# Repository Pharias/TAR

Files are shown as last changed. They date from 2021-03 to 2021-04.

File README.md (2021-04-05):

# TAR
Git-Projekt für TAR von Felix Kuschel und Manuel Starz

Enthält die Projektdateien:
  -  Dokumentation (LaTeX)
  -  Schaltplan (KiCAD)
  -  Programmcode (C/C++)

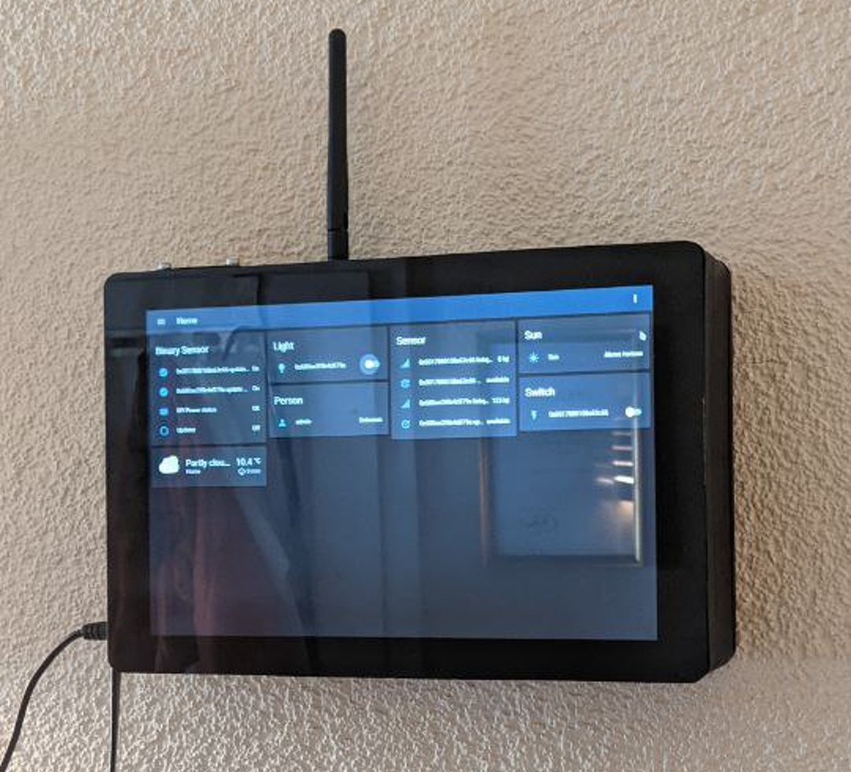
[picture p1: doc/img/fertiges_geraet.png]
Bild der SHZ


## Image für Raspberry Pi
Images für die einfache Einrichtung (Basierend auf Raspberry Pi OS):
 -  Raspberry Pi 4: [mediafire Download](https://www.mediafire.com/file/eujoh6s4thpg363/shz_rp4.img.gz/file)
 -  Raspberry Pi 3: [mediafire Download](https://www.mediafire.com/file/bc2o542na3rea7j/shz_rp3.img.gz/file)

Kann mit [Raspberry Pi Imager](https://www.raspberrypi.org/software/) auf SD-Karte geflasht werden.

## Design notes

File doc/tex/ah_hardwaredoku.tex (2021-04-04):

\subsection{Hardware-Dokumentationen}\label{hardwaredoku}
Durch den Umfang der einzelnen Dokumentationen hier nur eine Auflistung der Dokumentationen mit dem Link zu den PDF im GIT-Projekt bzw. zu den Herstellerseiten.
\begin{itemize}
 	\item Raspberry Pi:\\ {\url{https://www.raspberrypi.org/documentation/hardware/raspberrypi/bcm2711/rpi_DATA_2711_1p0.pdf}}
 	\item MiFare MFRC522:\\ {\url{https://www.nxp.com/docs/en/data-sheet/MFRC522.pdf}}
 	\item CC2531 ZigBee SoC:\\ {\url{https://www.ti.com/lit/ds/symlink/cc2531.pdf}}
 	\item ATmega128RFA1-ZU:\\ {\url{https://ww1.microchip.com/downloads/en/DeviceDoc/Atmel-8266-MCU_Wireless-ATmega128RFA1_Datasheet.pdf}}
\end{itemize}
\newpage

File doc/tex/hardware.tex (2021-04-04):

\section{Hardware}\label{hardware}
% Raspberry Pi 4
\input{tex/hw_raspberrypi}
% Aufbau des Prototypen
\input{tex/hw_prototype}
% Gehäuse
\input{tex/hw_case}
\newpage
% Raspberry Pi HAT
\input{tex/hw_hat}
% Dokumentation des Testaufbaus
\input{tex/hw_testaufbau}
\newpage

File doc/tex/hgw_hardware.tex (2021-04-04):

\subsection{Hardware}\label{hgw_hardware}
Bei der Entwicklung der Hardware haben wir für unser Projekt intern einige Rahmenbedinungen festgelegt:
\begin{itemize}
	\item das Projekt sollte nach Möglichkeit von durchschnittlich begabten Hobbyhandwerkern durchgeführt werden
	\item die Fertigstellung des Projekts sollte mit handelsüblichen Werkzeugen möglich sein
	\item die Grundplattform sollte der 2020 herausgebrachte Raspberry Pi 4 8GB sein\footnote{Wikipedia: Raspberry Pi - Generations}
	\item das Gerät sollte Zigbee-Endgeräte
verwalten können, da diese von vielen Herstellern vertriebenen werden.
\end{itemize}
\noindent Die Beschaffung der Teile lief dank Online-Versandhandel relativ problemlos. 
Beim Erstellen des Prototyps haben wir nur aus Bildschirm, dem Raspberry Pi und dem Zigbee-USB-Stick zusammengebaut (vgl. Abschnitt \ref{hw_prototype}: \nameref{hw_prototype}). 
Die Vorlage  Standfüße stammt vom Hersteller des Bildschirms Sunfounder \footnote{Sunfounder: 10.1 Inch Touch Screen for Raspberry Pi(NEW) - 3D-printed Touch Screen Support}.
Diese haben wir aus PETG\footnote{PETG: Glycol modifiziertes PET} auf dem 3D-Drucker Ender 3  selbst gedruckt. 
Im Folgenden haben wir uns mit der Software des Projekts befasst (vgl. Abschnitt \ref{hgw_software}: \nameref{hgw_software} und Kapitel \ref{software}: \nameref{software}).\par
\noindent Nachdem der Prototyp soweit funktionsfähig war, haben wir das Präsentationsmodell entworfen. 
Dabei ging es uns vornehmlich um die Unterbringung der geplanten Komponenten in einem einfach herzustellendem Gehäuse. 
Hierfür waren einige Verlängerung der Kabel nötig, um Stromzufuhr, Netzwerk und die Antenne des Zigbee-Sticks nach außen zu führen (vgl. Abschnitt \ref{hw_case_modellentwicklung}: \nameref{hw_case_modellentwicklung} und Abschnitt \ref{ku_produkt}: \nameref{ku_produkt}). \\
\noindent Das Gehäuse wurde nach dem Druck mit dem Bildschirm verklebt und die einzelnen Komponenten eingebaut (vgl. Abschnitt \ref{hw_case_herstellung}: \nameref{hw_case_herstellung}). 
Nach dem Zusammenbau haben wir einen Präsentationsaufbau, der die Funktionsweise unseres Prototyps in einem ,,typischen'' Heimnetzwerk darstellen soll (vgl. Abschnitt \ref{hw_testaufbau}: \nameref{hw_testaufbau}).\\
\noindent Näheres zur Umsetzung der Hardware im Kapitel \ref{hardware}: \nameref{hardware}.

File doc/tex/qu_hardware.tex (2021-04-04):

\subsection{Verwendete Hardware}\label{qu_hardware}
\begin{table}[H]
\begin{tabularx}{\textwidth}{|p{5cm}|p{6cm}|p{3.2cm}|}
    	\hline
 	    \textbf{Hardware} & \textbf{Verwendung} & \textbf{Version} \\
    	\hline
    	\hline
    	Raspberry Pi & Hauptplatine für die Smart Home Zentrale & Version 4B (8GB)\\
 	    \hline
 	    CC2531 Zigbee USB Stick mit Firmware & USB-Stick mit ZigBee-Chip & Rev 2.4\\
    	\hline
    	Sunfounder 10.1 Touch Screen  & Bildschirm und Input für die Smart Home Zentrale & Unbekannt\\
 	    \hline
 	    Creality Ender 3 Pro & Fertigung der Kunststoffteile & Modifiziert\\
 	    \hline
    \end{tabularx}
    \caption{Verwendete Hardware}
    \label{tab:qu_hardware}
\end{table}

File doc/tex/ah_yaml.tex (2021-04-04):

\subsection{YAML-Dateien}\label{ah_yaml}
\subsubsection{Home Assistant Konfiguration}\label{ah_yaml_ha_configuration}
\inputminted[
frame=lines,
framesep=2mm,
baselinestretch=1.2,
fontsize=\footnotesize,
linenos,
breaklines, 
breakafter=d
]{yaml}{misc/ha_configuration.yaml}
\subsubsection{Zigbee2MQTT Konfiguration}\label{ah_yaml_zigbee2mqtt}
\inputminted[
frame=lines,
framesep=2mm,
baselinestretch=1.2,
fontsize=\footnotesize,
linenos,
breaklines, 
breakafter=d
]{yaml}{misc/zigbee2mqtt_configuration.yaml}
\subsubsection{Zigbee Geräteauflistung}\label{ah_yaml_devices}
\inputminted[
frame=lines,
framesep=2mm,
baselinestretch=1.2,
fontsize=\footnotesize,
linenos,
breaklines, 
breakafter=d
]{yaml}{misc/devices.yaml}
\newpage

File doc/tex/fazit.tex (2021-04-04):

\section{Epilog \& Fazit}\label{fazit}
% Hier können wir jeder noch n kleines Fazit bzw ne Danksagung oder sowas machen ;)
Zum Abschluss möchten wir sagen, dass wir nach knapp fünf Monaten eine recht ansehnliche Lösung für Smart Home Besitzer entwerfen konnten. 
Dieses Projekt ist in dieser Zeit zu einer Herzensangelegenheit von uns beiden geworden und wird noch einige Zeit über die Abgabe dieser Technikerarbeit hinaus von uns erweitert und betreut.\\
\noindent Unser Ziel wird es sein, das ganze Projekt als ein Baukastensystem für den technisch versierten Smart Home Besitzer, als auch für den Anfänger im Smart Home Bereich auf den Markt zu bringen.
% Statistik?
%\input{tex/fz_statistik}
% Fehler und Probleme
\input{tex/fz_probleme}
% Danksagung
\input{tex/fz_danksagung}
% Latex vs. Word. Auskommentieren für Herr Kohlers Sonderversion ;)
%\input{tex/fz_LatexVsWord}
\newpage

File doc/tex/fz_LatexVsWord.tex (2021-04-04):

\subsection{\LaTeX vs Word}\label{fz_LatexVsWord}
Danke Herr Kohler. 
Ihre fast zwei Jahre langes Gejammer über WYSIWYG-Dokumenteneditoren haben dazu geführt, dass wir uns in den letzten Zügen der Dokumentation dazu entschlossen haben, OHNE JEGLICHE VORERFAHRUNG diese in \LaTeX zu schreiben. 
Ich hoffe, Sie sind stolz auf das Monster, dass Sie geschaffen haben...
\newpage

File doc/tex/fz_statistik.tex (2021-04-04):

\subsection{Statistik}\label{fz_statistik}
Neu aufgesetzte Raspberry Pis: 143\\
Zeilen Bash-Skript: 397\\
Tassen Kaffee: 41\\
Tassen Kakao: 79\\
Filament: 127,31m\\
Erfolgserlebnisse: 15\\
Niederschläge: 18\\
Aha!-Momente: 36\\
Größe der Images: 5.276.969.656 Byte\\
% Muss man noch zählen...
Zeilen \LaTeX - Skript: alle!\\

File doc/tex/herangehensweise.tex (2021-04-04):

\section{Herangehensweise}\label{herangehensweise}
Nach Festlegung der Anforderungen haben wir uns an die Beschaffung der benötigten Materialien und die Einrichtung der Hard- und Software gemacht. 
Hierfür wurde zum Teil bereits vorhandene Hardware, z.B. den Raspberry Pi 4 mit weiteren Komponenten wie dem Touch-Bildschirm, Lautsprechern und einem Mikrofon ergänzt. 
Wir haben die Umsetzung des Projekts in zwei Abschnitte aufgegliedert:
% Hardware
\input{tex/hgw_hardware}
\newpage
% Software
\input{tex/hgw_software}
\newpage

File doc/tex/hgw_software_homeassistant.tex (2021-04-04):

\subsubsection{Home Assistant}\label{hwg_software_homeassistant}
Im Bereich Software haben wir uns bereits verfügbare Lösungen für Smart Home Zentralen angeschaut. 
Ursprünglich war unser Plan, eine eigene Softwarelösung mit Web-Interface oder einer App-Anbindung für Smartphones zu programmieren.\\
\noindent Diese Idee haben wir nach kurzer Zeit aber wieder verworfen, da dieser Markt sowohl mit kostenlosen als auch kostenpflichtigen Lösungen mehr als gesättigt ist. 
Von den kostenlosen und quelloffenen Lösungen war für uns Home Assistant am interessantesten.
Vor allem wegen der großen Menge an Erweitrungsmöglichkeiten und der unserer Meinung nach recht ansprechenden Web-Oberfläche.
Home Assistant verfügt über drei grundlegende Möglichkeiten, installiert zu werden:
\begin{itemize}
    \item als eigenes Betriebssystem-Image (Home Assistant Operating System)
    \item als Docker Container
    \item als Programm auf einem Server.
\end{itemize}
Unabhängig von der Installationsart wird der Home Assistant in zwei Versionen angeboten:
\begin{itemize}
    \item als Core Version
    \item als Supervised Version.
\end{itemize}
Die Core Version ist die einfache Basisversion des Home Assistants, während die Supervised Version ein Addon-Repository integriert. \footnote{siehe \url{https://www.home-assistant.io/installation/}}\\
\noindent Zusätzlich vertreibt Home Assistant auch noch eine fertige Out-of-the-Box-Lösung namens Home Assistant Blue\footnote{siehe \url{https://www.home-assistant.io/blue}} für 140\$ , allerdings gibt es nur wenige Länder, in denen das Gerät verfügbar ist und es besitzt anders als unsere Lösung integrierten keinen Bildschirm.\\
\noindent Für unsere Anwendung war das eigene Betriebssystem-Image nicht verwendbar, da sich auf dem System keine grafische Oberfläche nachinstallieren ließ. 
Aus diesem Grund haben wir uns für zuerst die Programm-Variante des Home Assistants entschieden.\\
\noindent Allerdings gab es bei der Installation der Supervised Version auf unterschiedlichen Versionen des Raspberry Pis Probleme.
Die Core-Version war für unsere Zwecke ungeeignet, da der Arbeitsaufwand für die Integration von zusätzlichen Komponenten und Systemerweiterungen für die Zielgruppe des Projekts zu komplex wäre. \\
\noindent Während unserer Testphase hat sich gezeigt, dass die Verknüpfung von Home Assistant Core, Mosquitto Broker sowie Zigbee2MQTT nicht zu dauerhaft reproduzierbaren Erfolgen geführt hat und sich deshalb nicht wie von uns geplant automatisieren ließ. 
Deshalb haben wir uns für die Container-Variante mit Docker entschieden. 
Das Installationsskript (vgl. \ref{ah_skript}: \nameref{ah_skript}) installiert die benötigten Programme und übernimmt die Grundeinrichtung des Home Assistants bis zu dem Punkt, an dem die Einrichtung über die Weboberfläche durch den Nutzer erfolgt.\\
\noindent Um neben dem Skript noch eine weitere Art der Installation zu ermöglichen, bieten wir die Möglichkeit der Nutzung eines Images.
Für die beiden in Verwendung befindlichen Raspberry Pi Versionen\footnote{Raspberry Pi B Version 3 und Version 4(8GB)} haben wir entspechend nach Ablauf des Installationsskripts ein Backup-Image erzeugt.
Der Benutzername und das Passwort entsprechen bei den Images den standardmäßig in Raspberry Pi OS hinterlegten Nutzern und sollten beim booten sicherheitshalber geändert werden.\\
\noindent Nähere Informationen hierzu im Kapitel \ref{software}: \nameref{software}.

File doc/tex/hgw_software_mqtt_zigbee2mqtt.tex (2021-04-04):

\subsubsection{MQTT und Zigbee2MQTT}\label{hwg_software_mqtt_zibee2mqtt}
Um mit Zigbee die von uns angestrebte Steuerung und Integration von Leuchtmitteln und Geräten zu ermöglichen, benötigen wir den Übertragungsstandard MQTT. Dieser bietet die Möglichkeit, die Zigbee-Daten an den Home Assistant weiter zu reichen.
%Um die von uns angestrebte Steuerung und Integration mit Zigbee-Leuchtmitteln und -Geräten zu ermöglichen, benötigen wir den Übertragungsstandard MQTT und die Möglichkeit die Zigbee Daten über diesen an Home Assistant weiter zu reichen. 
Wir haben uns schon frühzeitig auf den Mosquitto Broker zur Verarbeitung des Zigbee-Protokolls entschieden.
\begin{itemize}
    \item Mosquitto broker (Opensource MQTT broker)
    \item Zigbee2MQTT als Zigbee Schnittstelle
\end{itemize}
\noindent \paragraph{Beschreibung MQTT}
\begin{quote}
    \color{quotetext}
    MQTT is an OASIS standard for IoT connectivity. It is a publish/subscribe, extremely simple and lightweight messaging protocol, designed for constrained devices and low-bandwidth, high-latency or unreliable networks. The design principles are to minimise network bandwidth and device resource requirements whilst also attempting to ensure reliability and some degree of assurance of delivery. These principles also turn out to make the protocol ideal of the “Internet of Things” world of connected devices, and for mobile applications where bandwidth and battery power are at a premium.\footnote{MQTT.org (2021): What is MQTT}
\end{quote}
\noindent \paragraph{Beschreibung Mosquitto Broker}
\begin{quote}
    \color{quotetext}
 	    Eclipse Mosquitto is an open source (EPL/EDL licensed) message broker that implements the MQTT protocol versions 5.0, 3.1.1 and 3.1. Mosquitto is lightweight and is suitable for use on all devices from low power single board computers to full servers.

        The MQTT protocol provides a lightweight method of carrying out messaging using a publish/subscribe model. This makes it suitable for Internet of Things messaging such as with low power sensors or mobile devices such as phones, embedded computers or microcontrollers.

        The Mosquitto project also provides a C library for implementing MQTT clients, and the very popular mosquitto-pub and mosquitto-sub command line MQTT clients.\footnote{mosquitto.org (2021): Eclipse Mosquitto$^{TM}$ An open source MQTT broker}
\end{quote}
\newpage
\noindent \paragraph{Beschreibung Zigbee2MQTT}
\begin{quote}
    \color{quotetext}
 		Zigbee2MQTT is made up of three modules, each developed in its own Github project. Starting from the hardware (adapter) and moving up; zigbee-herdsman connects to your Zigbee adapter an makes an API available to the higher levels of the stack. For e.g. Texas Instruments hardware, zigbee-herdsman uses the TI zStack monitoring and test API to communicate with the adapter. Zigbee-herdsman handles the core Zigbee communication. The module zigbee-herdsman-converters handles the mapping from individual device models to the Zigbee clusters they support. Zigbee clusters are the layers of the Zigbee protocol on top of the base protocol that define things like how lights, sensors and switches talk to each other over the Zigbee network. Finally, the Zigbee2MQTT module drives zigbee-herdsman and maps the zigbee messages to MQTT messages. Zigbee2MQTT also keeps track of the state of the system. It uses a database.db file to store this state; a text file with a JSON database of connected devices and their capabilities.\footnote{Koen Kanters (2021): Zigbee2MQTT}
\end{quote}

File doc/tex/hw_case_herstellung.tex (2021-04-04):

\subsubsection{Herstellung des Gehäuses}\label{hw_case_herstellung}
Zur Herstellung des Gehäuses kommt ein 3D-Drucker der Marke Creality 3D zum Einsatz. 
Der stark modifizierte Ender 3 Pro (vgl. Abb. \ref{fig:ender3}: \nameref{fig:ender3}) druckt die zuvor erstellten STL-Dateien mit PETG-Filament der Firma dasfilament. 
Der für den 3D-Druck nötige G-Code haben wir mit Ultimaker CURA generiert und mit Hilfe von OctoPrint (vgl. Abb. \ref{fig:octoprint}: \nameref{fig:octoprint}) an den Drucker übertragen. Das Gehäuse besteht aus vier Einzelteilen, je zwei Teile für die Seitenwände und zwei Teile für den Deckel.\par
\begin{figure}[H]
	\begin{center}
	
	\end{center}
	\caption[3D-Drucker Ender 3 Pro (mod)]{3D-Drucker Ender 3 Pro (mod)}
	\label{fig:ender3}
\end{figure}
\begin{figure}[H]
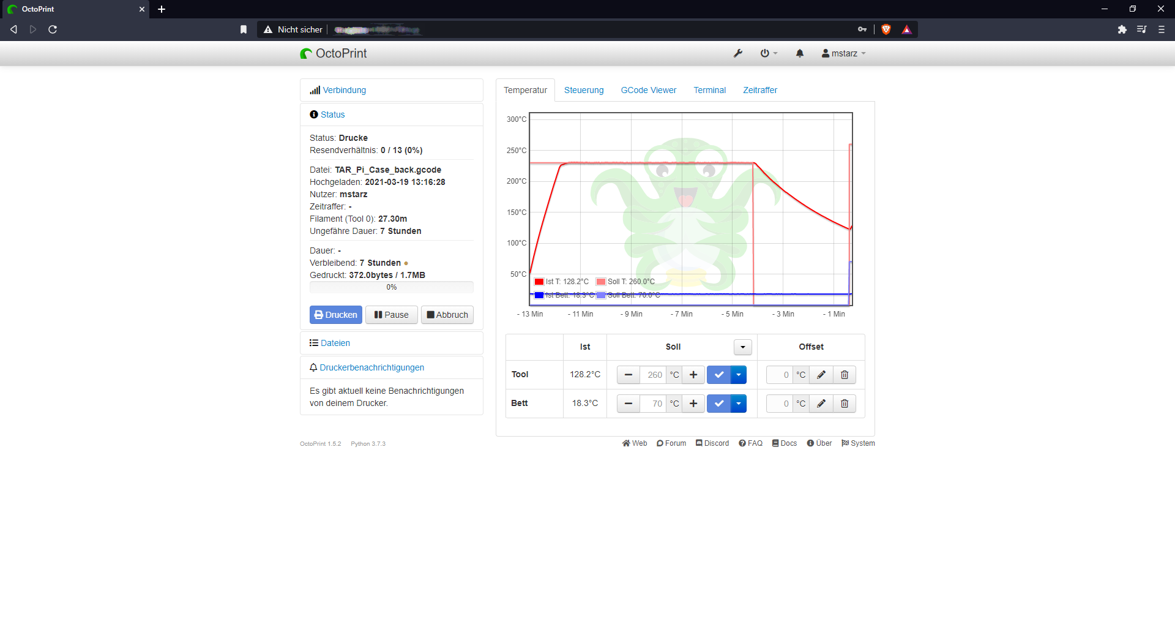
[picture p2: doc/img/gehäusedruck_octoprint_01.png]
	
	\caption[OctoPrint-Weboberfläche]{OctoPrint-Weboberfläche}
	\label{fig:octoprint}
\end{figure}
\noindent Die gedruckten Teile (vgl. Abb. \ref{fig:printet_parts}: \nameref{fig:printet_parts}) werden dann zum Teil mit Zwei-Komponenten-Epoxid-Kleber verbunden (vgl. Abb. \ref{fig:glued_parts}: \nameref{fig:glued_parts}) und mit Hilfe von Schleifpapier und einigen Schichten Klarlack zu einem klavierlackähnlichen Finish veredelt (vgl. Abb. \ref{fig:filed_and_painted_parts}: \nameref{fig:filed_and_painted_parts}).\\ 
\noindent Die Seitenwände werden dann mit dem Bildschirm mit Hilfe des Zwei-Komponenten-Epoxidklebers und Heißkleber permanent verklebt (vgl. Abb. \ref{fig:finished_case_front}: \nameref{fig:finished_case_front}).
Danach wurden die Platinen und Kabel im Gehäuse angebracht (vgl. Abb. \ref{fig:finished_case_front}: \nameref{fig:finished_case_front}). 
Die Rückseite besteht der Einfachheit halber aus zwei identischen, punktsymmetrischen Teilen, die ebenfalls miteinander verklebt wurden.\par
\begin{figure}[H]
	\begin{subfigure}[b]{0.5\linewidth}
		\centering
		
		\caption[Druck eines der Deckel-Teile]{Druck eines der Deckel-Teile}
	\end{subfigure}
	\begin{subfigure}[b]{0.5\linewidth}
		
		\caption[Druck der Wand-Teile]{Druck der Wand-Teile}
	\end{subfigure}
	\caption[Das Gehäuse entsteht]{Das Gehäuse entsteht}
	\label{fig:printing_parts}
\end{figure}
\par
\begin{figure}[H]
	\centering
	\begin{subfigure}[b]{0.3\linewidth}
		
		\caption[Rückseite]{Rückseite}
		\label{printet_parts_back}
	\end{subfigure}
	\begin{subfigure}[b]{0.3\linewidth}
		
		\caption[Linke Seite]{Linke Seite}
		\label{printet_parts_left}
	\end{subfigure}
	\begin{subfigure}[b]{0.3\linewidth}
		
		\caption[Rechte Seite]{Rechte Seite}
		\label{printet_parts_right}
	\end{subfigure}
	\caption[Ausgedruckte Teile des Gehäuses]{Ausgedruckte Teile des Gehäuses}
	\label{fig:printet_parts}
\end{figure}
\par
\begin{figure}[H]
	\begin{subfigure}[b]{0.5\linewidth}
		\centering
		
		\caption[Verklebung des Gehäuses]{Verklebung des Gehäuses}
		\label{fig:glued_parts}
	\end{subfigure}
	\begin{subfigure}[b]{0.5\linewidth}
		\centering
		
		\caption[Abgeschliffene und lackierte Teile]{Abgeschliffene und lackierte Teile}
		\label{fig:filed_and_painted_parts}
	\end{subfigure}
	\begin{subfigure}[b]{0.5\linewidth}
		\centering
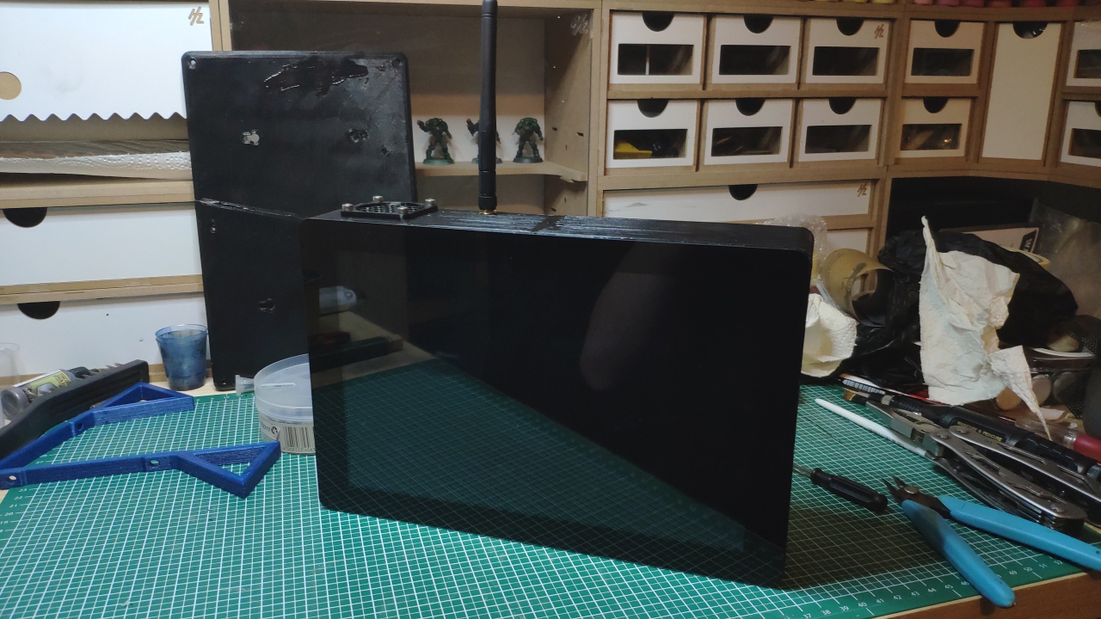
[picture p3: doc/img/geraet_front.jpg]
		
		\caption[Gehäuse und Bildschirm verklebt (von vorne)]{Gehäuse und Bildschirm verklebt (von vorne)}
		\label{fig:finished_case_front}
	\end{subfigure}
	\begin{subfigure}[b]{0.5\linewidth}
		\centering
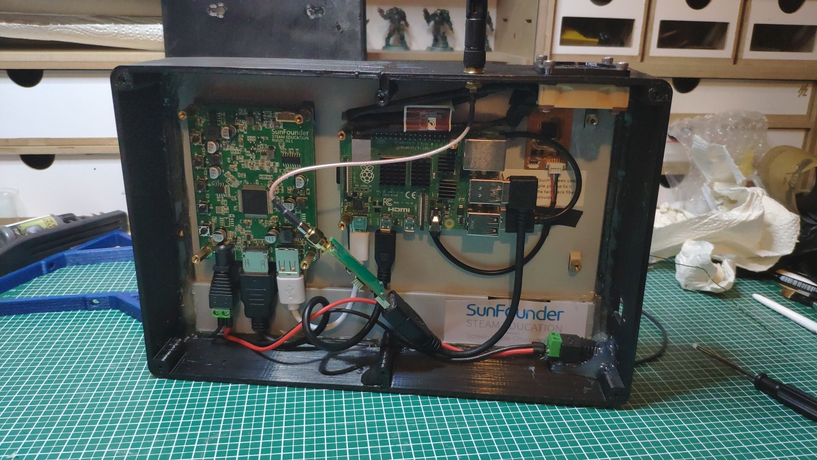
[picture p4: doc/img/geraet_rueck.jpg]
		
		\caption[Gehäuse und Bildschirm verklebt (von hinten)]{Gehäuse und Bildschirm verklebt (von hinten)}
		\label{fig:finished_case_back}
	\end{subfigure}
	\caption[Fertigung des Gehäuses]{Fertigung des Gehäuses}
	\label{fig:creating-case}
\end{figure}\par
\noindent Bei der Herstellung ist es aber zu einem Problem gekommen. 
Die Stützstrukturen haben den Druck am Lüftereinlass gestört, was dazu führt, dass das Lüftergitter an der  linken Seitenwand (vgl. Abb. \ref{printet_parts_left}: \nameref{printet_parts_left}) nicht richtig gedruckt wurde und die losen Filamentstücke zu Macken an den Gehäusewänden führen.

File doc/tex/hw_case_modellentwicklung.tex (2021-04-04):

\subsubsection{Modellentwicklung am Objekt}\label{hw_case_modellentwicklung}
\paragraph{Grundskizze}\\
\noindent Nachdem das Testmodell (vgl. Abb. \ref{fig:print-case-test_04}: \nameref{fig:print-case-test_04}) nicht zu 100 \% gepasst hat, haben wir die Abmessungen neu erfasst und diese in Fusion 360 übertragen (vgl. Abb. \ref{fig:case_footprint}: \nameref{fig:case_footprint}). 
Um Material für den 3D-Druck zu sparen, haben wir eine Papierschablone erstellt, die Zeichnung dann im Maßstab 1:1 auf Papier ausgedruckt, ausgeschnitten und am Bildschirm angelegt.\par
\noindent So haben wir die Maße angepasst und den Plan entsprechend ergänzt(vgl. Abb. \ref{fig:case_footprint_final}: \nameref{fig:case_footprint_final}).\\
\noindent Die Zeichnung haben wir in zwei eigenständige Dateien gesplittet, um die linke und die rechte Seite des Gehäuses konstruieren zu können.\par
\noindent Die Grundabmessung des Bildschirms haben wir in Fusion 360 als neue Zeichnung angelegt. 
Hierzu haben wir ein einfaches Rechteck mit den entsprechenden Außenmaßen gezeichnet (vlg. Abb. \ref{fig:design-case-01}: \nameref{fig:design-case-01}) und anschließend die Ecken mit einem Radius von 7 mm abgerundet (vgl. Abb. \ref{fig:design-case-02}: \nameref{fig:design-case-02}). 
Die Zeichnung haben wir in der Mitte geteilt, um die beiden Hälften des Gehäuses unabhängig von einander konstruieren zu können.\par
\begin{figure}[H]
	\begin{subfigure}[b]{.5\linewidth}
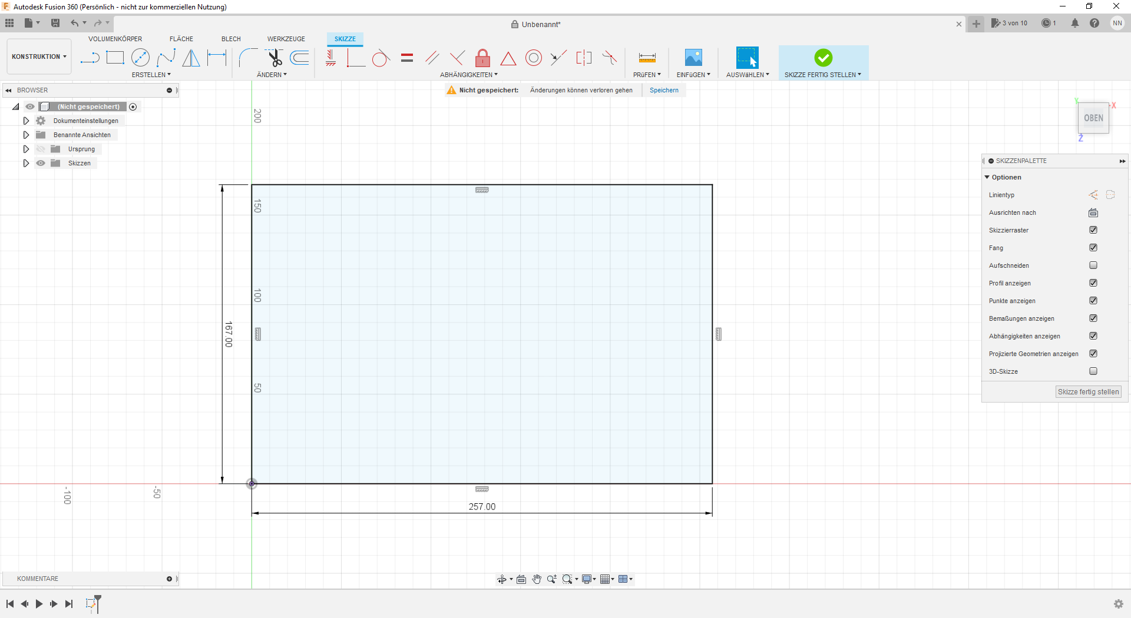
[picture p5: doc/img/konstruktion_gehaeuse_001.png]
		
		\caption[Zeichnen der Außenmaße]{Zeichnen der Außenmaße}
		\label{fig:design-case-01}
	\end{subfigure}
	\begin{subfigure}[b]{.5\linewidth}
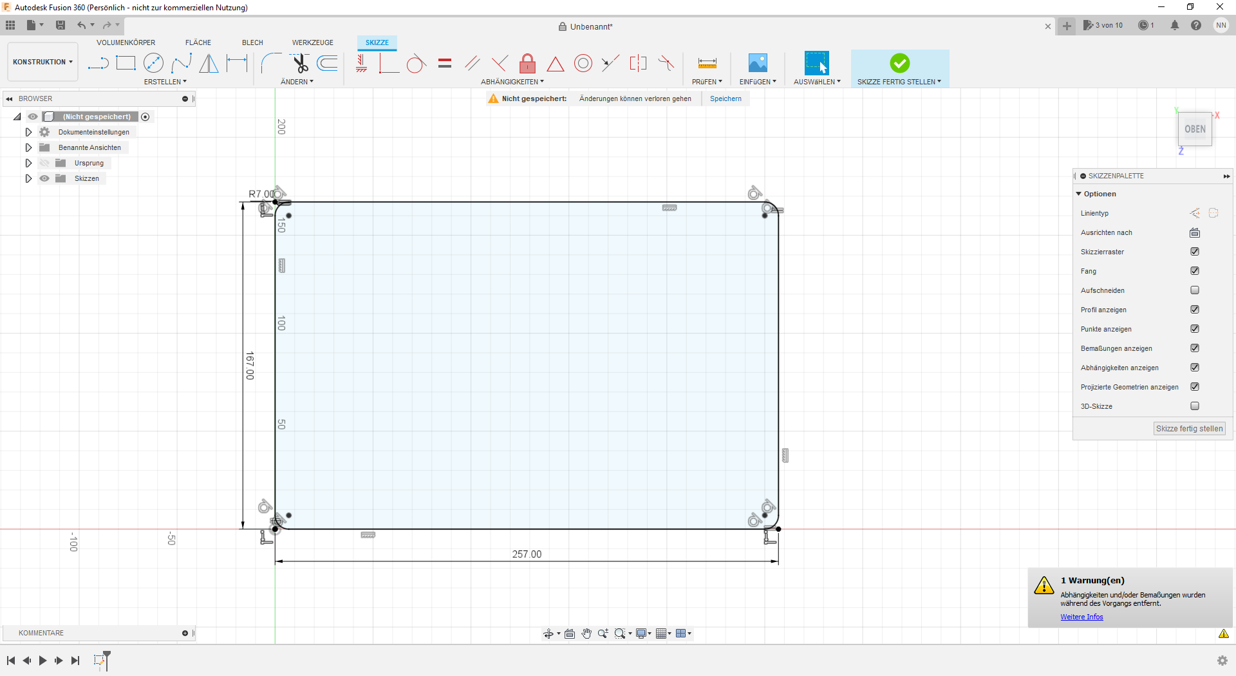
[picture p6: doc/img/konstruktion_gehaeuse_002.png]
		
		\caption[Abrunden der Ecken]{Abrunden der Ecken}
		\label{fig:design-case-02}
	\end{subfigure}
	\begin{subfigure}[b]{.5\linewidth}
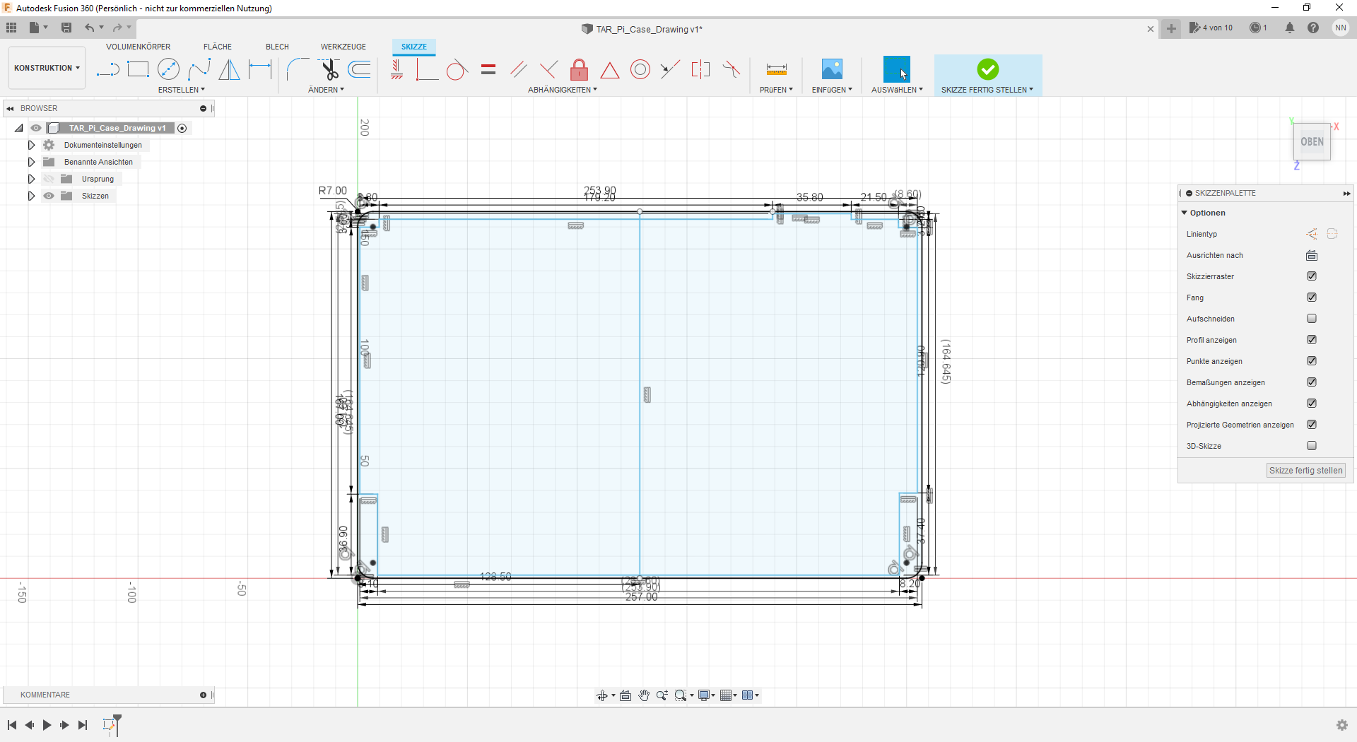
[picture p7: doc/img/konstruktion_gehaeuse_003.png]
		
		\caption[Zeichnen der Auflageflächen für das Gehäuse]{Zeichnen der Auflageflächen}
		\label{fig:design-case-03}
	\end{subfigure}
	\caption[Grundzeichnung als Basis des Modells]{Grundzeichnung als Basis des Modells}
	\label{fig:design-case-base}
\end{figure}\par
\noindent Die so entstandene Zeichnung (vgl. Abb. \ref{fig:design-case-03}: \nameref{fig:design-case-03}) haben wir dann in eine weitere Datei kopiert, die als Grundlage für die beide Seitenteile dient. 
Ausgehend von dieser Zeichnung aus haben wir die beiden Wandteile unabhängig voneinander entworfen.\par
\paragraph{Linkes Wandteil}
Beim linken Wandteil haben wir die Zeichnung um 2 mm entlang der Z-Achse nach oben extrudiert (vgl. Abb. \ref{fig:design-left-01}: \nameref{fig:design-left-01}), um eine Auflagefläche zu erzeugen. 
Auf der Oberseite haben wir eine weitere Zeichnung gelegt, um die Kontaktfläche für die Verklebung mit dem Bildschirm zu erweitern (vgl. Abb. \ref{fig:design-left-02}: \nameref{fig:design-left-02}), die wir dann wie zuvor um 3 mm entlang der Z-Achse extrudiert haben (vgl. Abb. \ref{fig:design-left-03}: \nameref{fig:design-left-03}) um auf die gleiche Höhe des Blechs auf der Rückseite des Bildschirms zu gelangen. \\
\noindent Diese sollte dem Gehäuse genug Auflagefläche auf dem Bildschirm bieten, um die Verklebung so stabil wie möglich zu machen. 
Auf die nun entstandene Erhöhung haben wir eine Zeichnung des Rahmens von 3 mm Stärke erstellt (vgl. Abb. \ref{fig:design-left-04}: \nameref{fig:design-left-04}), die wir dann um 6 mm entlang der Z-Achse extrudiert haben, um für die Verbinder der Schrauben genügend Platz vor dem herausstehenden Blechbereich im unteren Teil des Bildschirms zu bieten (vgl. Abb.  \ref{fig:design-left-05}: \nameref{fig:design-left-05}). \\
\noindent Auf die nun obenliegende Seite des Gehäuses haben wir die Zeichnung der Verbindungsstücke gelegt (vgl. Abbildung \ref{fig:design-left-06}: \nameref{fig:design-left-06}), um 19 mm entlang der Z-Achse extrudiert (vgl. Abb. \ref{fig:design-left-07}: \nameref{fig:design-left-07}). 
Im Kreismittelpunkt der Zeichnungen eine Bohrung für M3-Gewinde gesetzt (vgl. Abb. \ref{fig:design-left-08}: \nameref{fig:design-left-08}). 
Auf die Oberseite haben wir die Zeichnung für die Verbindung von Deckel und dem Seitenteil gesetzt (vgl. Abb. \ref{fig:design-left-09}: \nameref{fig:design-left-09}) und um 25 mm entlang der Z-Achse extrudiert (vgl. Abb. \ref{fig:design-left-10}: \nameref{fig:design-left-10}), damit der von uns verwendete 40 mm Lüfter im Gehäuse Platz findet.
Dies haben wir ebenfalls mit Bohrungen für M3-Gewinde versehen (vgl. Abb. \ref{fig:design-left-11}: \nameref{fig:design-left-11}).\par
\begin{figure}[H]
	\begin{subfigure}[t]{.3\linewidth}
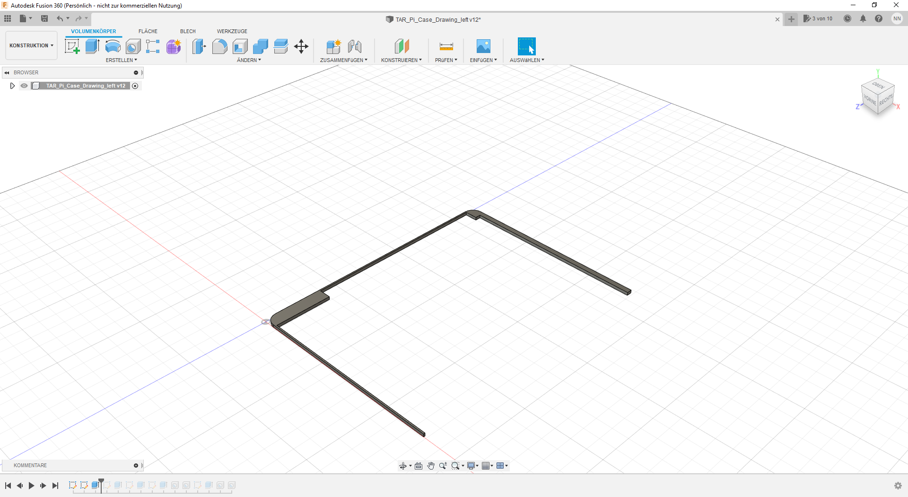
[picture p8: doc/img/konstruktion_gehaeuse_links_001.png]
		
		\caption[Extrusion der Grundzeichnung]{Extrusion der Grundzeichnung}
		\label{fig:design-left-01}
	\end{subfigure}
	\begin{subfigure}[t]{.3\linewidth}
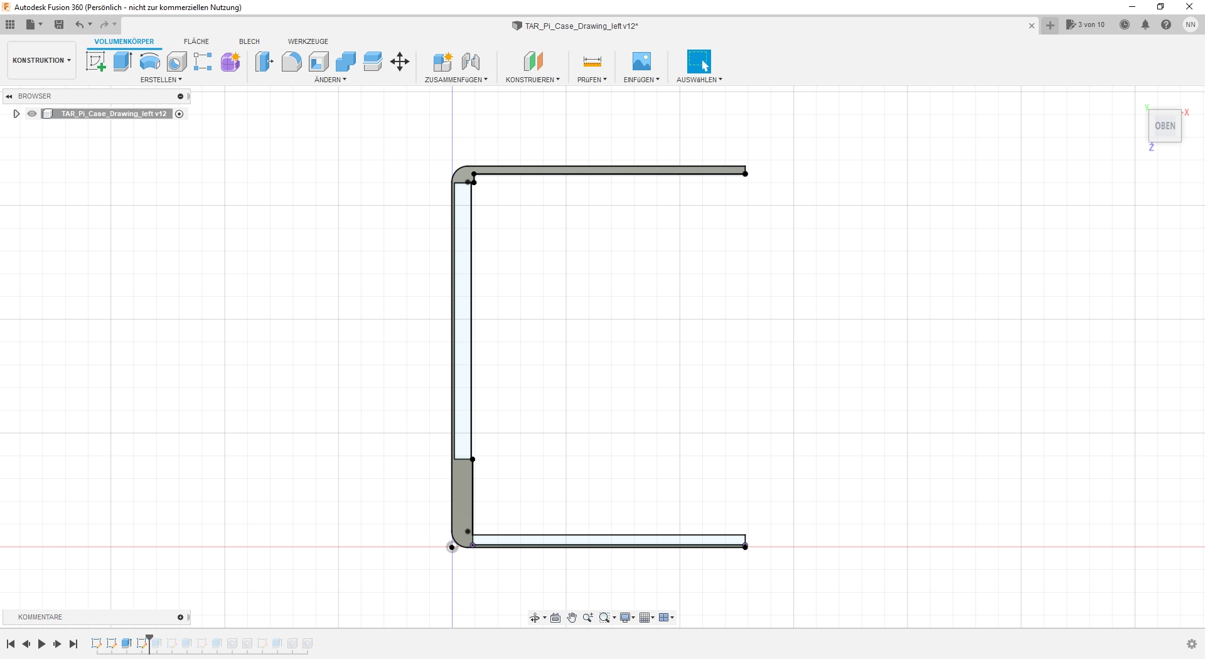
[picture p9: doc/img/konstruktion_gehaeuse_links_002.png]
		
		\caption[Erstellung der Folgezeichnung um Blech]{Erstellung der Folgezeichnung um Blech}
		\label{fig:design-left-02}
	\end{subfigure}
	\begin{subfigure}[t]{.3\linewidth}
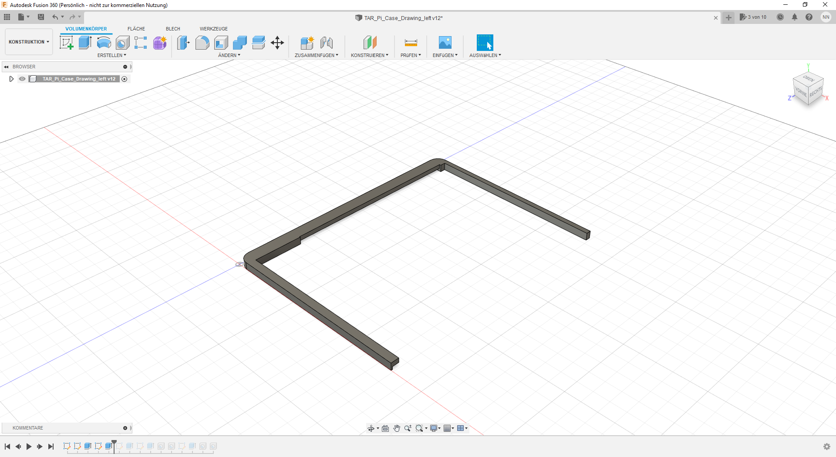
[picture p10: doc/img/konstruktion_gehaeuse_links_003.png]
		
		\caption[Extrusion der neuen Zeichnung]{Extrusion der neuen Zeichnung}
		\label{fig:design-left-03}
	\end{subfigure}
	\begin{subfigure}[t]{.3\linewidth}
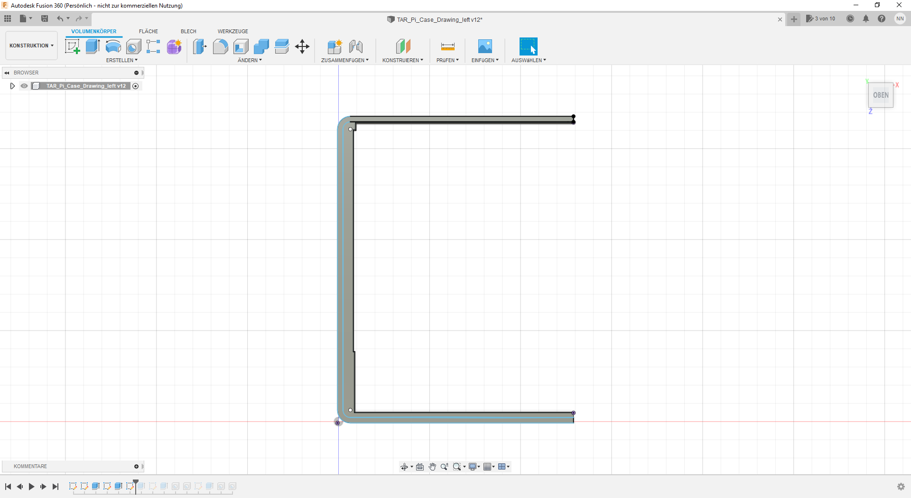
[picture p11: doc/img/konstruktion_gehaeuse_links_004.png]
		
		\caption[Zeichnung der Hauptwandstärke]{Zeichnung der Hauptwandstärke}
		\label{fig:design-left-04}
	\end{subfigure}
	\begin{subfigure}[t]{.3\linewidth}
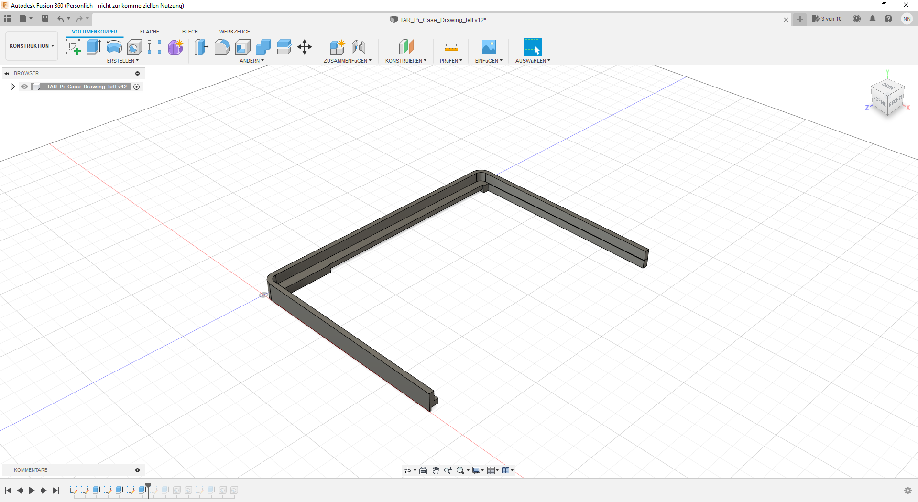
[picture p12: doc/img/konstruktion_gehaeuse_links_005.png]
		
		\caption[Extrusion der Hauptwand]{Extrusion der Hauptwand}
		\label{fig:design-left-05}
	\end{subfigure}
	\begin{subfigure}[t]{.3\linewidth}
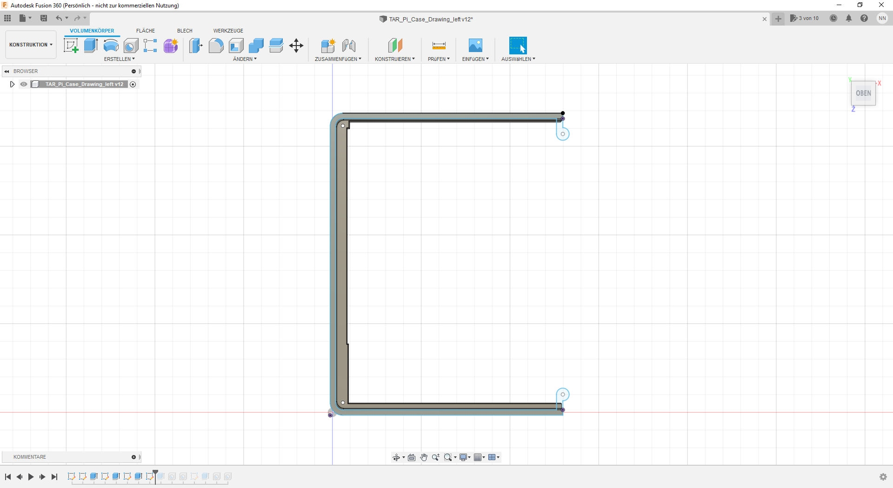
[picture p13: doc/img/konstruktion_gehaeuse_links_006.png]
		
		\caption[Zeichnung der Verbindungsstücke]{Zeichnung der Verbindungsstücke}
		\label{fig:design-left-06}
	\end{subfigure}
	\begin{subfigure}[t]{.3\linewidth}
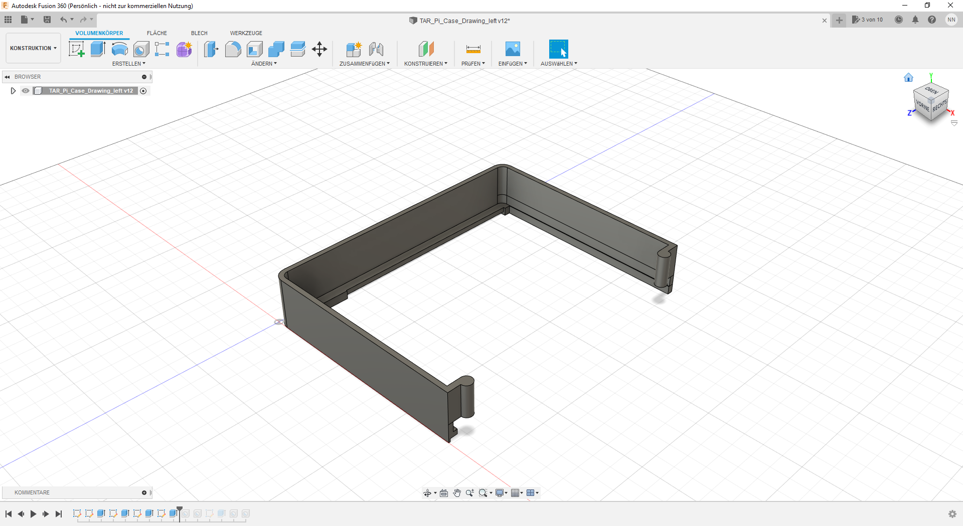
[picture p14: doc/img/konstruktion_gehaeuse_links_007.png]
		
		\caption[Extrusion der Hauptwand mit Verbindungsstücken]{Extrusion der Hauptwand mit Verbindungsstücken}
		\label{fig:design-left-07}
	\end{subfigure}
	\begin{subfigure}[t]{.3\linewidth}
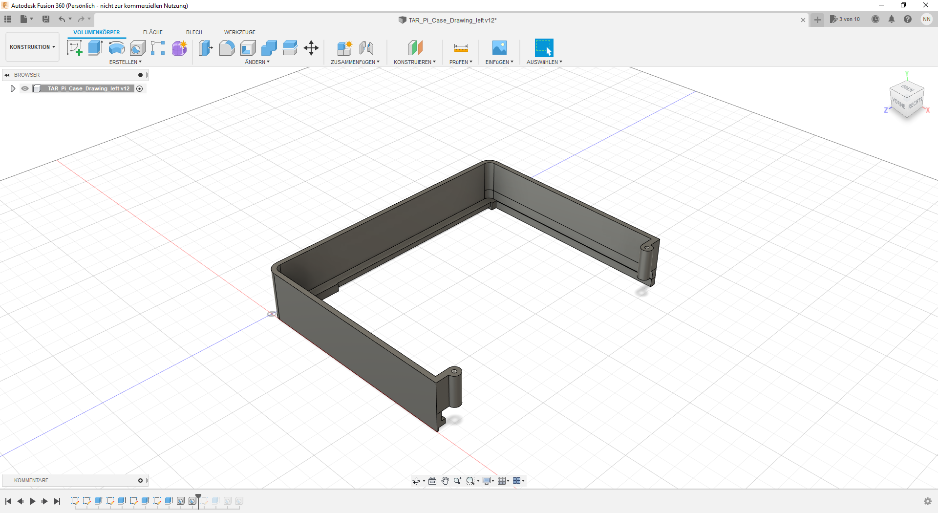
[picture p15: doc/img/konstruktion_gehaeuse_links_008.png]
		
		\caption[Bohrung für Schrauben]{Bohrung für Schrauben}
		\label{fig:design-left-08}
	\end{subfigure}
	\begin{subfigure}[t]{.3\linewidth}
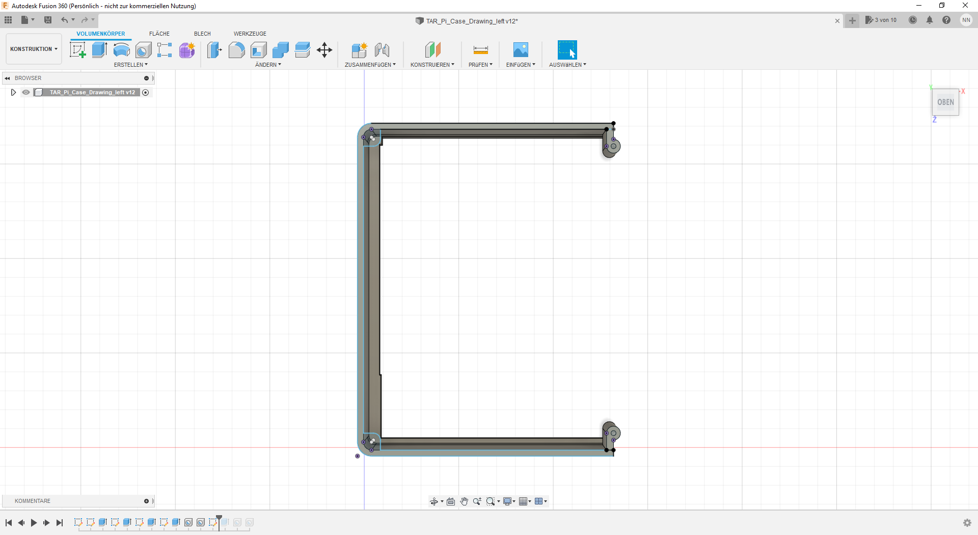
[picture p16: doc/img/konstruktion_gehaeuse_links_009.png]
		
		\caption[Zeichnung der Deckelverbindung]{Zeichnung der Deckelverbindung}
		\label{fig:design-left-09}
	\end{subfigure}
	\begin{subfigure}[t]{.3\linewidth}
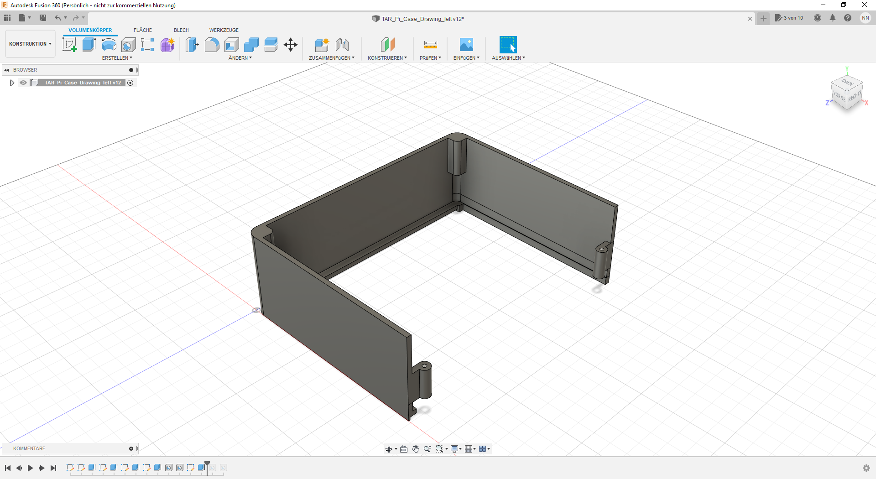
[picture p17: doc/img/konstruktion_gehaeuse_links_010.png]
		
		\caption[Extrusion der Hauptwand mit Deckelverbindung]{Extrusion der Hauptwand mit Deckelverbindung}
		\label{fig:design-left-10}
	\end{subfigure}
	\begin{subfigure}[t]{.3\linewidth}
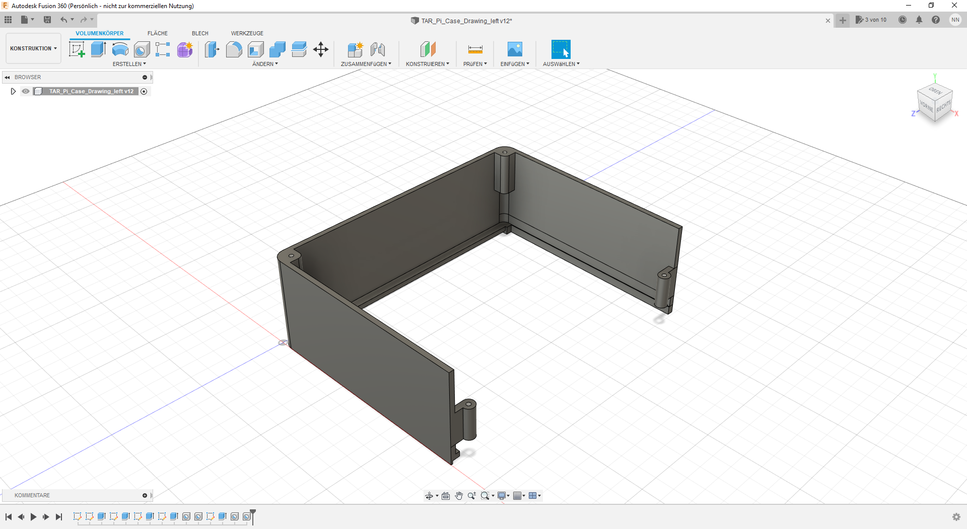
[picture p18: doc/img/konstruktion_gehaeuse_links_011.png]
		
		\caption[Bohrungen der Deckelverbindung]{Bohrungen der Deckelverbindung}
		\label{fig:design-left-11}
	\end{subfigure}
	\caption[Entwurf des linken Wandteils]{Entwurf des linken Wandteils}
	\label{fig:design-left}
\end{figure}\par
\newpage
\paragraph{Rechtes Wandteil}
Beim rechten Teil des Gehäuses ist die Vorgehensweise weitestgehend die selbe wie beim linken Gehäuseteil (vgl. Abb. \ref{fig:design-right-01}: \nameref{fig:design-right-01} - Abb. \ref{fig:design-right-08}: \nameref{fig:design-right-08} mit Abb. \ref{fig:design-left}: \nameref{fig:design-left}). 
Der Unterschied zwischen beiden Teilen, abgesehen von den Verbindungsstücken und der Aussparung für das Flachkabel des Bildschirms, sind zusätzlich die Aussparungen für Lüfter, Antenne, Netzwerkanschluss und Strombuchse. \\
\noindent Für den Lüfter und die Antenne haben wir auf dem oberen Teil des Gehäuses eine Zeichnung aufgelegt (vgl. Abb. \ref{fig:design-right-09}: \nameref{fig:design-right-09}), die  wir dann ins Negative extrudiert haben, um die gezeichnete Fläche aus dem Gehäuse zu löschen (vgl. Abb. \ref{fig:design-right-10}: \nameref{fig:design-right-10}). 
Mit der selben Vorgehensweise haben wir die Aussparung für eine RJ45-Verlängerung und eine 5,5 mm DC-Buchse gesetzt. 
Zuerst haben wir die Zeichnung für die Aussparung auf die Seite gelegt (vgl. Abb.  \ref{fig:design-right-11}: \nameref{fig:design-right-11}) und diese dann ebenfalls ins Negative extrudiert (vgl. Abb. \ref{fig:design-right-12}: \nameref{fig:design-right-12}). \\
\noindent Um für die Befestigung der 5,5 mm DC-Buchse eine Unterlage im Gehäuse zu haben, haben wir der Grundriss eines Rechtecks auf die Innenseite des Gehäusebodens gelegt (vgl. Abb.  \ref{fig:design-right-13}: \nameref{fig:design-right-13}) und extrudiert (vgl. Abb. \ref{fig:design-right-14}: \nameref{fig:design-right-14}), um die Möglichkeit zu haben, die Buchse mit dem Gehäuse zu verkleben. 
Damit die Buchse nicht zu tief im Gehäuse steckt, haben wir eine Zeichnung eines konzentrischen Kreises auf die bereits vorhandene Aussparung auf die Innenseite gelegt  (vgl. Abb.  \ref{fig:design-right-15}: \nameref{fig:design-right-15}) und dann um einige Millimeter ins Negative verkürzt, um die Aussparung zu generieren (vgl. Abb. \ref{fig:design-right}: \nameref{fig:design-right}).\par
\begin{figure}[H]
	\begin{subfigure}[t]{.3\linewidth}
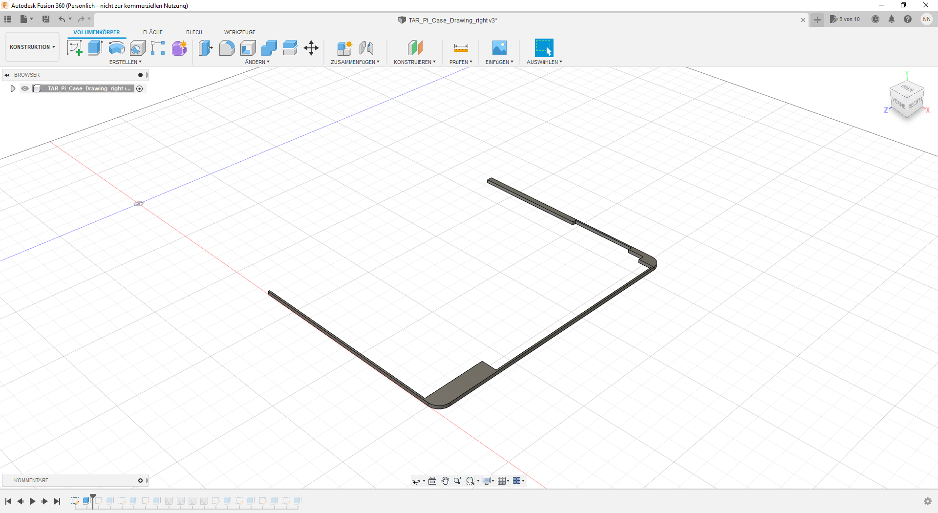
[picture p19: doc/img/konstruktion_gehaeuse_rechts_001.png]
		
		\caption[Extrusion der Grundzeichnung]{Extrusion der Grundzeichnung}
		\label{fig:design-right-01}
	\end{subfigure}
	\begin{subfigure}[t]{.3\linewidth}
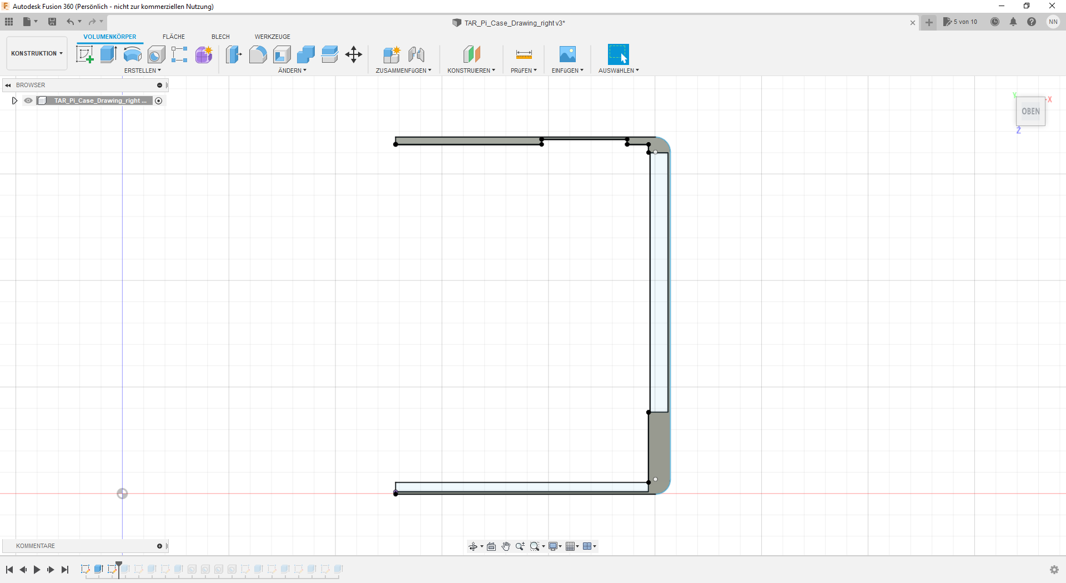
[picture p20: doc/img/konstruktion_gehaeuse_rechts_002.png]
		
		\caption[Erstellung der Folgezeichnung um Blech]{Erstellung der Folgezeichnung um Blech}
		\label{fig:design-right-02}
	\end{subfigure}
	\begin{subfigure}[t]{.3\linewidth}
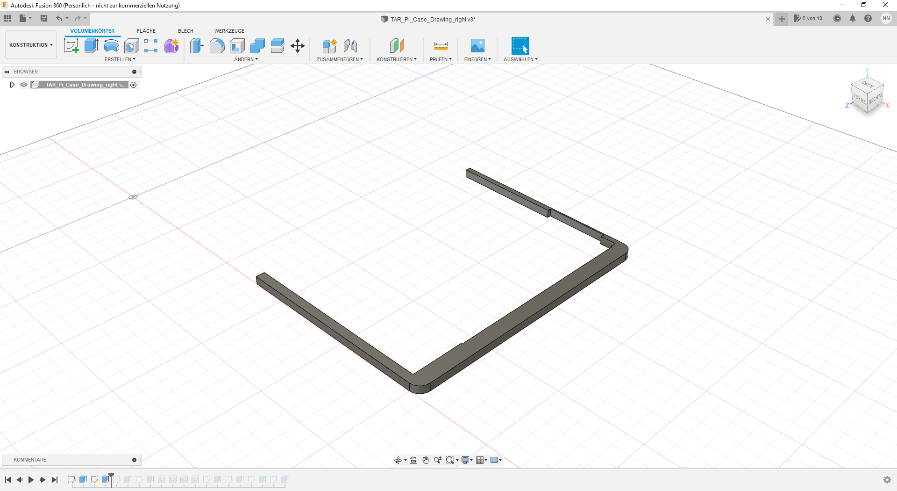
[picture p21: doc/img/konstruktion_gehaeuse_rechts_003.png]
		
		\caption[Extrusion der neuen Zeichnung]{Extrusion der neuen Zeichnung}
		\label{fig:design-right-03}
	\end{subfigure}
	\begin{subfigure}[t]{.3\linewidth}
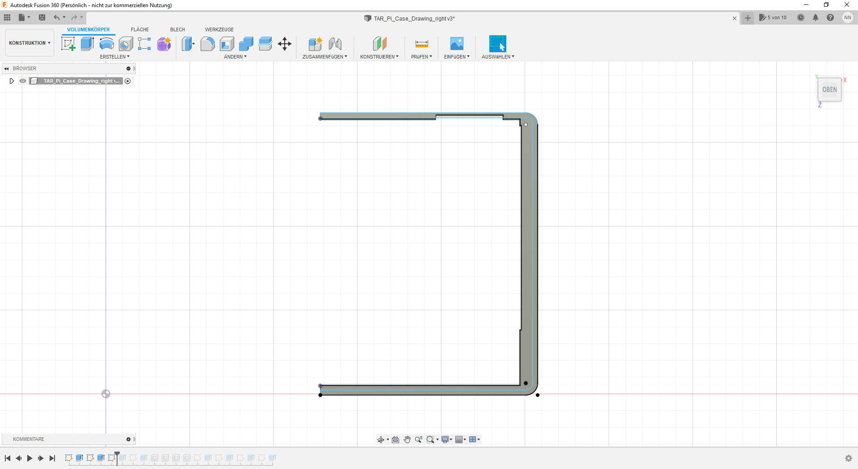
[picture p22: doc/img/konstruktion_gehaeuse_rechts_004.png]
		
		\caption[Zeichnung der Hauptwandstärke]{Zeichnung der Hauptwandstärke}
		\label{fig:design-right-04}
	\end{subfigure}
	\begin{subfigure}[t]{.3\linewidth}
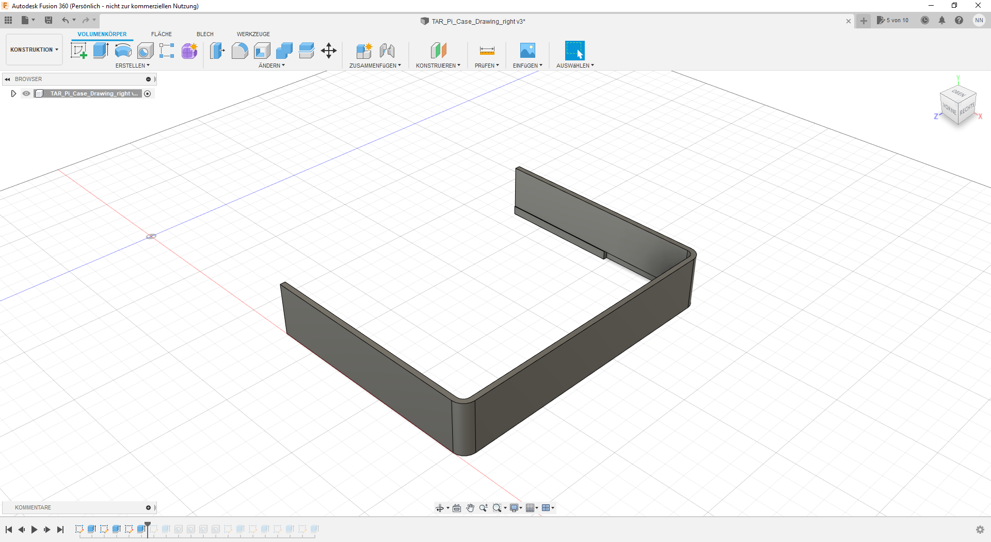
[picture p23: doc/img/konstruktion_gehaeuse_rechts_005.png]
		
		\caption[Extrusion der Hauptwand]{Extrusion der Hauptwand}
		\label{fig:design-right-05}
	\end{subfigure}
	\begin{subfigure}[t]{.3\linewidth}
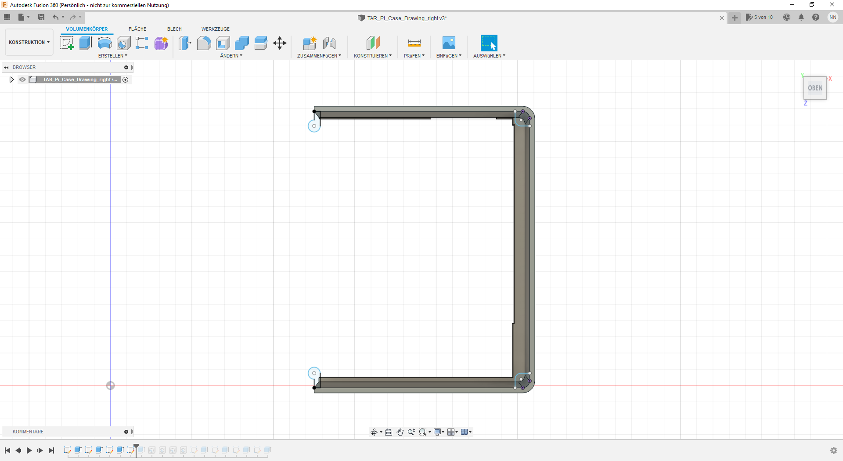
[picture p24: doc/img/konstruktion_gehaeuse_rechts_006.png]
		
		\caption[Zeichnung der Verbindungsstücke \& Deckelverbindung]{Zeichnung der Verbindungsstücke \& Deckelverbindung}
		\label{fig:design-right-06}
	\end{subfigure}
	\begin{subfigure}[t]{.3\linewidth}
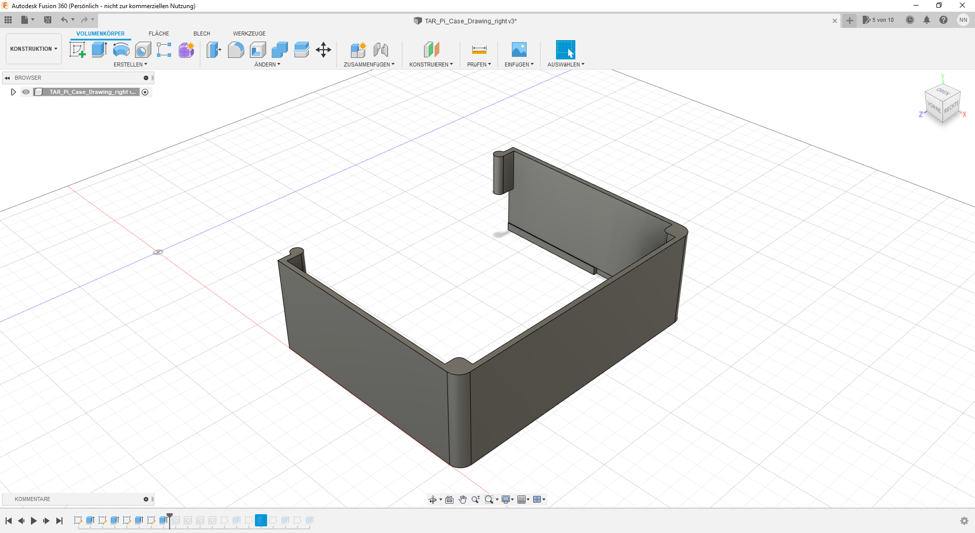
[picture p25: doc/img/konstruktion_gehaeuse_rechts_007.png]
		
		\caption[Extrusion der Hauptwand mit Deckelverbindung]{Extrusion der Hauptwand mit Deckelverbindung}
		\label{fig:design-right-07}
	\end{subfigure}
	\begin{subfigure}[t]{.3\linewidth}
		
		\caption[Bohrung für Schrauben]{Bohrung für Schrauben}
		\label{fig:design-right-08}
	\end{subfigure}
	\begin{subfigure}[t]{.3\linewidth}
		
		\caption[Zeichnung für Lüfteröffnung \& Antennenausgang]{Zeichnung für Lüfteröffnung \& Antennenausgang}
		\label{fig:design-right-09}
	\end{subfigure}
	\begin{subfigure}[t]{.3\linewidth}
		
		\caption[Extrusion der Lüfteröffnung]{Extrusion der Lüfteröffnung}
		\label{fig:design-right-10}
	\end{subfigure}
	\begin{subfigure}[t]{.3\linewidth}
		
		\caption[Zeichnung der Aussparung für Stromanschluss \& Netzwerkbuchse]{Zeichnung der Aussparung für Stromanschluss \& Netzwerkbuchse}
		\label{fig:design-right-11}
	\end{subfigure}
	\begin{subfigure}[t]{.3\linewidth}
		
		\caption[Extrusion der Netzwerkbuchse]{Extrusion der Netzwerkbuchse}
		\label{fig:design-right-12}
	\end{subfigure}
	\begin{subfigure}[t]{.3\linewidth}
		
		\caption[Zeichnung des Stromsteckerblocks]{Zeichnung des Stromsteckerblocks}
		\label{fig:design-right-13}
	\end{subfigure}
	\begin{subfigure}[t]{.3\linewidth}
		
		\caption[Extrusion des Stromsteckerblocks]{Extrusion des Stromsteckerblocks}
		\label{fig:design-right-14}
	\end{subfigure}
	\begin{subfigure}[t]{.3\linewidth}
		
		\caption[Zeichnung der Aussparung]{Zeichnung der Aussparung}
		\label{fig:design-right-15}
	\end{subfigure}
	\begin{subfigure}[t]{.3\linewidth}
		
		\caption[Extrusion der Aussparung]{Extrusion der Aussparung}
		\label{fig:design-right-16}
	\end{subfigure}
	\caption[Entwurf des rechten Wandteils]{Entwurf des rechten Wandteils}
	\label{fig:design-right}
\end{figure}\par
\paragraph{Gehäuserückwand}\par
Das Design der Gehäuserückwand basiert nur rudimentär auf der in Abb. \ref{fig:design-case-base}: \nameref{fig:design-case-base} erstellten Zeichnung. 
Die Außenmaße stimmen zwar überein, die Zeichnung für die Auflage auf den Seitenwänden haben wir aber neu erstellt. 
Zusätzlich haben wir eine Diagonale zur punktsymmetrischen Trennung der Teile eingefügt (vgl. Abb. \ref{fig:design-back-01}: \nameref{fig:design-back-01}), welche den Zeitaufwand für den Druck von zwei unterschiedlichen Teilen für die Rückseite reduzieren soll. \\
\noindent Nachdem wir die  Zeichnung extrudiert haben (vgl. Abb. \ref{fig:design-back-02}: \nameref{fig:design-back-02}), haben wir noch einen Vorsprung auf der kurzen Seite des Bauteils extrudiert (vgl. Abb. \ref{fig:design-back-03}: \nameref{fig:design-back-03}), um die beiden Rückwandteile besser verbinden zu können. 
Anschließend haben wir ein weiter Teil der inneren Zeichnung ins Negative extrudiert, um diesen Bereich freizustellen (vgl. Abb. \ref{fig:design-back-04}: \nameref{fig:design-back-04}) und um beim Druck der Teile Material zu sparen. \\
\noindent Damit für eventuelle Toleranzen zwischen den beiden Teilen Platz ist, haben wir auf dem Vorsprung die Aussparung für die darunterliegende Schraubendurchführung erhöht (vgl. Abb. \ref{fig:design-back-05}: \nameref{fig:design-back-05}) und den Vorsprung von unten mit einer Fase versehen, was den Materialverbrauch für das Teil weiter reduziert (vgl. Abb. \ref{fig:design-back-06}: \nameref{fig:design-back-06}). 
Zudem haben wir die obere Kante (vgl. Abb. \ref{fig:design-back-07}: \nameref{fig:design-back-07}), die Innenseite (vgl. Abb. \ref{fig:design-back-08}: \nameref{fig:design-back-08}) und auch den Vorsprung (vgl. Abbildung \ref{fig:design-back-09}: \nameref{fig:design-back-09}) mit einer Fase versehen. \\
\noindent Um die Bohrungen an die richtige Stellen setzen zu können, haben wir eine Hilfszeichnung auf die Außenfläche, also die Außenseite der Rückwand, aufgelegt (vgl. Abb. \ref{fig:design-back-10}: \nameref{fig:design-back-10}). 
Dort haben wir dann drei M3-Bohrungen für Senkkopfschrauben gesetzt (vgl. Abb. \ref{fig:design-back-11}: \nameref{fig:design-back-11}). \\
\noindent Für die Aufhängungen auf der Rückseite des Gehäuses haben wir eine weitere Zeichnung aufgelegt (vgl. Abb. \ref{fig:design-back-12}: \nameref{fig:design-back-12}) und dann ins Negativ extrudiert (vgl. Abb. \ref{fig:design-back-13}: \nameref{fig:design-back-13}).
So kann das Gehäuse mit zwei Schrauben an der Wand angebracht werden.  
Um beim Aufhängen nicht an einen bestimmten Typ Schrauben gebunden zu sein, haben wir eine kleine Fase an den engeren Teil der Aufhängungen gelegt (vgl. Abb. \ref{fig:design-back-14}: \nameref{fig:design-back-14}). 
\begin{figure}[H]
	\begin{subfigure}[t]{.3\linewidth}
		
		\caption[Grundrisszeichnung]{Grundrisszeichnung}
		\label{fig:design-back-01}
	\end{subfigure}	
	\begin{subfigure}[t]{.3\linewidth}
		
		\caption[Extrusion der Grundform]{Extrusion der Grundform}
		\label{fig:design-back-02}
	\end{subfigure}
	\begin{subfigure}[t]{.3\linewidth}
		
		\caption[Extrusion des Vorsprungs]{Extrusion des Vorsprungs}
		\label{fig:design-back-03}
	\end{subfigure}
	\begin{subfigure}[t]{.3\linewidth}
		
		\caption[Erstellen der Aussparung]{Erstellen der Aussparung}
		\label{fig:design-back-04}
	\end{subfigure}
	\begin{subfigure}[t]{.3\linewidth}
		
		\caption[Anpassung für Toleranz]{Anpassung für Toleranz}
		\label{fig:design-back-05}
	\end{subfigure}
	\begin{subfigure}[t]{.3\linewidth}
		
		\caption[Abfasen des Vorsprungs]{Abfasen des Vorsprungs}
		\label{fig:design-back-06}
	\end{subfigure}
	\begin{subfigure}[t]{.3\linewidth}
		
		\caption[Abfasen der Außenseite]{Abfasen der Außenseite}
		\label{fig:design-back-07}
	\end{subfigure}
	\begin{subfigure}[t]{.3\linewidth}
		
		\caption[Anbringung der Fase an der Innenseite]{Anbringung der Fase an der Innenseite}
		\label{fig:design-back-08}
	\end{subfigure}
	\begin{subfigure}[t]{.3\linewidth}
		
		\caption[Anbringung der Fase am Vorsprung]{Anbringung der Fase am Vorsprung}
		\label{fig:design-back-09}
	\end{subfigure}
	\begin{subfigure}[t]{.3\linewidth}
		
		\caption[Hilfszeichnung für Bohrungen]{Hilfszeichnung für Bohrungen}
		\label{fig:design-back-10}
	\end{subfigure}
	\begin{subfigure}[t]{.3\linewidth}
		
		\caption[Bohrungen mit Aussparung für Senkkopfschrauben]{Bohrungen mit Aussparung für Senkkopfschrauben}
		\label{fig:design-back-11}
	\end{subfigure}
	\begin{subfigure}[t]{.3\linewidth}
		
		\caption[Zeichnung für Wandaufhängungslöcher]{Zeichnung für Wandaufhängungslöcher}
		\label{fig:design-back-12}
	\end{subfigure}
	\begin{subfigure}[t]{.3\linewidth}
		
		\caption[Extrusion der Wandaufhängungslöcher]{Extrusion der Wandaufhängungslöcher}
		\label{fig:design-back-13}
	\end{subfigure}
	\begin{subfigure}[t]{.3\linewidth}
		
		\caption[Abfasen der Wandaufhängungslöcher]{Abfasen der Wandaufhängungslöcher}
		\label{fig:design-back-14}
	\end{subfigure}
	\begin{subfigure}[t]{.3\linewidth}
		
		\caption[Abfasen des Vorsprungs in der Mitte]{Abfasen des Vorsprungs in der Mitte}
		\label{fig:design-back-15}
	\end{subfigure}
	\caption[Entwurf der Gehäuserückwand]{Entwurf der Gehäuserückwand}
	\label{fig:design-back}
\end{figure}\par
\newpage

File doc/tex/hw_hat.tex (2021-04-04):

\subsection{Erstellung des RPi-HATs}\label{hw_hat}
Zur Schaltplanzeichnung haben wir das OpenSource-Programm KiCAD genutzt.
Dieses ist für zahlreiche Betriebssysteme verfügbar.\footnote{Siehe \url{https://www.kicad.org/download/}} 
Teilebibliotheken sind ebenso zahlreich im Internet verfügbar, wir haben uns auf den Anbieter SnapEDA beschränkt, da dieser die meisten gängigen Bauteile für Elektronik-CAD-Systeme anbietet. 
Eine weitere Bezugsquelle ist der Verkäufer Digi-Key Electronics, der einen Großteil seines Sortiments an SMD-Bauteilen als Bibliothek anbietet\footnote{Siehe \url{https://www.digikey.de/de/resources/design-tools/kicad}}. 
Als Grundlage für den HAT sollte die Projektvorlage ,,Raspberry Pi - 40-Pin HAT'' von Jon Buford dienen.
Diese Vorlage richtete sich nach den offiziellen HAT-Spezifikationen für den Raspberry Pi\footnote{Siehe \url{https://github.com/raspberrypi/hats}}.\par
\noindent Zu Beginn des Projekts haben wir in KiCAD die GPIO-Ports anhand der offiziellen Dokumentation beschriftet, um das Nachschlagen der Belegung für die Zukunft zu vermeiden.
\begin{figure}[H]
	
	\caption[Raspberry Pi 4 GPIO-Pins]{Raspberry Pi 4 GPIO-Pins}
	\label{rpi-gpio-pins}
\end{figure}
\par
\noindent Anschließend haben wir die (unserer Meinung nach) benötigten Komponenten auf den Schaltplan gezogen beziehungsweise vorher importiert und dann diese sauber verdrahtet (vgl. Abb. \ref{hat-design}: \nameref{hat-design}).\par
\begin{figure}[H]
	
	\caption[Aktueller Stand HAT-Design]{Aktueller Stand HAT-Design}
	\label{hat-design}
\end{figure}
\noindent Aufgrund der bereits weit vorangeschrittenen Zeit im Projektplan, der aktuellen COVID-19-Pandemie und unserer Unwissenheit im Bezug auf Schaltplanentwicklung, sowie der von uns verwendeten Hardware, mussten wir aber einsehen, dass die Entwicklung und Fertigung eines HAT's den Zeitrahmen sprengen würde und so haben wir Ende Februar 2021 beschlossen, dieses Projekt vorerst zurückzustellen und uns auf die Fertigstellung unserer bisherigen Testerfolge und Prototypen zu fokusieren.
Die KiCAD-Projekt-Dateien stehen, wie alle anderen Dateien des Projekts nach Abgabe der Technikerarbeit frei über das entsprechende GITHUB zur Verfügung.\par

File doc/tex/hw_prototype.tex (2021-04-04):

\subsection{Aufbau des Prototypen}\label{hw_prototype}
Der Prototyp war eine Kombination aus dem verwendeten Touchscreen sowie dem Raspberry Pi 4 und dem Zigbee-Stick. 
Dieser Prototyp diente als Entwicklungsplattform für die Software.\\
\noindent Auf der Detailansicht der Rückseite (vgl. Abb. \ref{fig:prototype_back}: \nameref{fig:prototype_back}) erkennt man den Raspberry Pi mt dem Zigbee-Stick und der angeschlossenen Antenne auf der rechten Seite.
Auf der linken Seite ist das Controller-Board des Bildschirms.
Dies dient gleichzeitig als Stromversorgung für den Raspberry Pi.
\begin{figure}[H]
	\begin{subfigure}[b]{0.5\linewidth}
		
		\caption[Vorderseite des Prototypen]{Vorderseite des Prototypen}
	\end{subfigure}
	\begin{subfigure}[b]{0.5\linewidth}
		
		\caption[Rückseiteseite des Prototypen]{Rückseite des Prototypen}
	\end{subfigure}
	\begin{subfigure}[b]{1\linewidth}
		
		\caption[Detailansicht der Rückseite]{Detailansicht der Rückseite}
		\label{fig:prototype_back}
	\end{subfigure}
	\caption[Prototyp der Smart Home Zentrale]{Prototyp der Smart Home Zentrale}
	\label{prototype}
\end{figure}
\newpage

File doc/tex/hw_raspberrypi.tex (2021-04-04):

\subsection{Raspberry Pi 4}\label{hw_raspberrypi}
Als Basis für die Smart Home Zentrale haben wir einen Raspberry Pi in der Version 4 mit 8 GB gewählt, um als von anderen Servern unabhängige Plattform agieren zu können. 
Der Raspberry Pi 4 ist mit einem ARM Cortex-A72 Prozessor ausgestattet, der über 4 Kerne verfügt.
Zusätzlich hat der Raspberry Pi 4 über einen Gigabit-Netzanschluss.
In der Makerszene ist der Raspberry Pi weit verbreitet und dient bei anspruchsvolleren Projekten als Kern.\par
\begin{quote}
 		\color{quotetext}
 		Der Raspberry Pi hat sich seit der ersten Veröffentlichung Anfang 2012 weltweit schon millionenfach verkauft und erfreut sich immer noch größter Beliebtheit. Denn viele Raspberry Pi User haben nicht nur einen Einplatinen-Computer zu Hause, sondern teils 4-5 Stück.
Der eine fungiert als HD-Mediaplayer mit externer Festplatte für das heimische Kino oder als Internetradio mit Display, der nächste als Webcam-Server für die Kameraüberwachung mit Livestream auf das Handy, dann noch einer für die Hausautomatisierung wie bspw. die Heizungs- oder Lichtsteuerung und noch einer als einfacher WLAN-Druckerserver oder als Mini-Computer zum allgemeinen Surfen im Internet, um ein paar wenige Anwendungsszenarien zu nennen.
Sie merken, der kleine ,,Tausendsassa'' kann nicht nur viel, sondern ist zudem auch noch extrem günstig und eben das macht den Reiz aus. Lediglich den Hang zum Programmieren sollten Sie mitbringen und selbst nicht mal das, denn Sie können auch einfach nach Anleitung aus Foren oder Büchern nachprogrammieren, oder ganz bequem ein fertiges Image auf den Raspberry Pi installieren - trauen Sie sich! 
\footnote{reichelt.de: Produktbeschreibung des Raspberry Pi 4}
\end{quote}
\newpage

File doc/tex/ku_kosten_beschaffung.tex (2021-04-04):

\subsubsection{Beschaffungskosten}\label{ku_kosten_beschaffung}
\begin{center}
\begin{table}[H]
    \begin{tabularx}{\textwidth}{|p{5.6cm}|p{1.2cm}|p{3.44cm}|p{3.5cm}|}
        \hline
 	    \textbf{Produkt} & \textbf{Menge} & \textbf{Kosten pro Stück}  & \textbf{Kosten insgesamt}\\
	    \hline
	    \hline
	    Raspberry Pi 4 Modell B 8 GB & 1 & 87,22 \euro{} & 87,22 \euro{} \\
	    \hline
	    SanDisk Extreme microSD 128 GB & 1 & 19,99 \euro{} & 19,99 \euro{} \\
	    \hline
	    SUNFOUNDER RPi 10.1'' Touch Display & 1 & 129,99 \euro{} & 129,99 \euro{} \\
	    \hline
	    Noctua NF-A4x10 5v & 1 & 12,90 \euro{} & 12,90 \euro{} \\
	    \hline
	    ITSTUFF CC2531 Zigbee USB-Stick & 1 & 14,90 \euro{} & 14,90 \euro{} \\
	    \hline
	    ITSTUFF Alu-Kühlkörper Set RPi 4 & 1 & 4,91 \euro{} & 4,91 \euro{} \\
	    \hline
	    Eightwood SMA Verlängerung & 1 & 7,99 \euro{} & 7,99 \euro{} \\ 
	    \hline
	    VCE 5,5 mm Stecker \& Buchse & 1 & 8,29 \euro{} & 8,29 \euro{} \\
	    \hline
	    dasFilament PTGE schwarz 1,75 mm & 0,52 & 24,95 \euro{}\footnote{Kosten der Spule (800 g).} & 11,61\euro{}\footnote{Kosten verwendetes Material für Gehäusedruck} \\
	    \hline
	    USB-Verlängerung & 1 & 9,99 \euro{} & 9,99 \euro{}\\
	    \hline
	    \hline
	    % hier noch die Kosten für das Zeug, das du gekauft hast, Felix. der Stick steht ja schon drin, aber weiß nicht ob der Preis passt...
	    %\hline
	    \textbf{Gesamtkosten} &  &  & \textbf{309,37 \euro{}} \\ % Kosten zusammenrechnen ;)
	    \hline
    \end{tabularx}
    \caption{Beschaffungskosten}
    \label{tab:ku_kostenberechnung}
\end{table}
\end{center}

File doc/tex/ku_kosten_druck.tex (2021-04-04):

\subsubsection{Kostenberechung für die 3D-Druckteile}\label{ku_kosten_druck}
\noindent Die Kosten lassen mit folgender Formel darstellen:\\
\[
K_{gesamt} =  (K_{Material/g} \cdot M_{Material}) +  (T_{Druck} \cdot  K_{kWh} \cdot V_{\emptyset/h})
\]
Die Kosten der 3D-Druckteile lassen sich in zwei Einzelpositionen aufteilen: Material und Energie.
Die Materialkosten lassen sich leicht erfassen, da wir die Kosten der Spule Filament mit 24,95 \euro{} und einem Gewicht von 800 g Filament auf der Spule gegeben haben.
So ergibt sich ein Preis von 0,03(12...)\euro{} ($K_{Material/g}$) pro Gramm verwendetem Filament.
Der Druck der Gehäuseteile verbrauchte 423 g Material ($M_{Material}$), das heißt, dass die Materialkosten sich auf 13,19 \euro{} belaufen.\par
\noindent Die Energiekosten zu berechnen ist etwas komplexer.
Der 3D-Drucker verbraucht circa 120 W pro Stunde($V_{\emptyset/h}$)\footnote{Robert (2019): Antwort auf Creality Ender 3 printer power consumption? - 3dprinting Stack Exchange}, was bei einem Strompreis von 0,31 \euro{} / kWh ($K_{kWh}$) bedeuten würde, dass wir pro Stunde etwa 0,0372 \euro{} Stromkosten haben. 
Bei einer Gesamtdruckzeit von 36 Stunden und 36 Minuten($T_{Druck}$) ergeben sich also Stromkosten von 1,37 \euro{}.\par
\noindent Addiert man nun die Kosten für Material und Energie, so ergibt sich ein Fertigungspreis von 12,98 \euro{} ($K_{gesamt}$). 
Dabei ist der Zeitaufwand für die Veredelung, also Schleifen und Lackieren, noch nicht mit einkalkuliert.\par

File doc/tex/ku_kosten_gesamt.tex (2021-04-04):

\subsubsection{Gesamtkosten}\label{ku_kosten_gesamt}
\begin{center}
\begin{table}[H]
    \begin{tabularx}{\textwidth}{|p{9.9cm}|p{4.7cm}|}
        \hline
 	    \textbf{Position} & \textbf{Kosten} \\
 	    \hline
 	    \hline
 	    Materialkosten & 309,37 \euro{} \\
	    \hline
	    Stromkosten Druck & 1,37 \euro{} \\
	    \hline
	    Stundenlohn & 3800,00 \euro{} \\
	    \hline
	    Kosten Präsentationsboard & 113,27 \euro{} \\
	    \hline
	    \hline
	    \textbf{Gesamtkosten} & \textbf{4224,01 \euro{}} \\ % Kosten zusammenrechnen ;)
	    \hline
    \end{tabularx}
    \caption{Gesamtkostenberechnung}
    \label{tab:ku_gesamtkostenberechnung}
\end{table}
\end{center}

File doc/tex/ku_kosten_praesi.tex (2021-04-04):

\subsubsection{Kosten Präsentationsboard}\label{ku_kosten_praesi}
\begin{center}
\begin{table}[H]
    \begin{tabularx}{\textwidth}{|p{5.6cm}|p{1.2cm}|p{3.44cm}|p{3.5cm}|}
        \hline
 	    \textbf{Produkt} & \textbf{Menge} & \textbf{Kosten pro Stück}  & \textbf{Kosten insgesamt}\\
	    \hline
	    \hline
	    OSB Platte & 1 & 11,22 \euro{} & 11,22 \euro{} \\
	    \hline
	    Kantholz & 4,2 m & 1,38 \euro{} & 2,76 \euro{} \\
	    \hline
	    Lampenfassung E27 Schwarz & 2 & 2,99 \euro{} & 5,98 \euro{} \\
	    \hline
	    Winkelverbinder Gleichschenklig & 4 & 4,99 \euro{} & 19,96 \euro{} \\
	    \hline
	    Konstruktionswinkel & 2 & 1,19 \euro{} & 2,38 \euro{} \\
	    \hline
	    Schrauben & 1 & 12,99 \euro{} & 12,99 \euro{} \\
	    \hline
	    Mantelleitung NYM-J 3 x 1,5 Grau 5 m & 1 & 4,99 \euro{} & 4,99 \euro{} \\ 
	    \hline
	    Abzweigkasten Aufputz & 3 & 1,59 \euro{} & 4,77 \euro{} \\
	    \hline
	    Schutzkontakt Flachstecker mit seitlicher Einführung & 1 & 1,69 \euro{}\ & 1,69\euro{} \\
	    \hline
	    Schutzkontakt Steckdose & 1 & 6,99 \euro{} & 6,99 \euro{} \\
	    \hline
	    König KNM-FTM10 Tablet Wandhalterung & 1 & 10,55 \euro{} & 10,55 \euro{} \\
	    \hline
	    Philips HUE Smart Plug & 1 & 29,99 \euro{} & 29,99 \euro{} \\
	    %\hline
	    \hline
	    \hline
	    \textbf{Gesamtkosten} &  &  & \textbf{113,27 \euro{}} \\ % Kosten zusammenrechnen ;)
	    \hline
    \end{tabularx}
    \caption{Kosten Präsentationsaufbau}
    \label{tab:ku_kostenpraesi}
\end{table}
\end{center}

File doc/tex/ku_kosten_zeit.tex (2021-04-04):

\subsubsection{Arbeitszeit}\label{ku_kosten_zeit}
Gerechnet wird in Stunden, ein Arbeitstag hat 8 Stunden.
\begin{center}
\begin{table}[H]
    \begin{tabularx}{\textwidth}{|p{11.8cm}|p{2.8cm}|}
        \hline
 	    \textbf{Projektabschnitt} & \textbf{Dauer (in h)} \\
	    \hline
	    \hline
	    Recherche & 60 \\
	    \hline
	    Themenfindung & 6 \\
	    \hline
	    Anfertigung Lastenheft & 20 \\
	    \hline
	    Beschaffung Hardware & 4 \\
	    \hline
	    Entwicklung Prototyp & 40 \\
	    \hline
	    Konstruktion Gehäuse & 40 \\
	    \hline
	    Software Installation & 8 \\
	    \hline
	    Entwurf Skript & 80 \\
	    \hline
	    Erstellung Images & 4 \\
	    \hline
	    Entwurf Raspberry Pi HAT & 30 \\
	    \hline
	    Dokumentation & 80 \\
	    \hline
	    Funktionsprüfung & 20 \\
	    \hline
	    Präsentationsaufbau & 8 \\
	    \hline
	    \hline
	    \textbf{Gesamt} & \textbf{400} \\
	    \hline
    \end{tabularx}
    \caption{Erfassung der Arbeitszeiten}
    \label{tab:ku_arbeitszeiten}
\end{table}
\end{center}
\noindent Bei dem aktuell gültigen Mindestlohn von 9,50 \euro{} \footnote{Deutscher Gewerkschaftsbund (2021): Mindestlohn 2021/2022: Was ändert sich?} kommen wir so auf Arbeitskosten von 3800 \euro{}.

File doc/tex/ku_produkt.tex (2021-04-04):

\subsection{Das ,,fertige`` Produkt}\label{ku_produkt}
\begin{figure}[H]
	
	\caption[Smart Home Zentrale]{Smart Home Zentrale}
	\label{fig:smart-home-zentrale}
\end{figure}
\noindent In Abbildung \ref{fig:smart-home-zentrale} wird das Ergebnis der Technikerarbeit von Felix Kuschel und Manuel Starz präsentiert. 
Die Smart Home Zentrale verfügt über eine ZigBee-Antenne, einem 10.1'' großen Touchbildschirm und der Möglichkeit, per LAN und oder WLAN mit dem Heimnetz in Verbindung zu treten.\par
\noindent Das Gehäuse ist für die Wand-Montage (vgl. Abb. \ref{fig:smart-home-zentrale}: \nameref{fig:smart-home-zentrale}) oder als Aufstellgerät (vgl. Abb. \ref{fig:case-with-feet}: \nameref{fig:case-with-feet}) entworfen worden.
\begin{figure}[H]
	
	\caption[Gehäuse mit Füßen (Render in Meshmixer)]{Gehäuse mit Füßen (Render in Meshmixer)}
	\label{fig:case-with-feet}
\end{figure}

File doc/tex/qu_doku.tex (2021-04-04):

\subsection{Dokumentationsquellen}\label{qu_doku}
Quellen für Verweise, die in Fußnoten innerhalb dieser Dokumentation erwähnt wurden:
\begin{itemize}
        \item github.com: Zigbee2MQTT Projektseite\\ 
        {\url{https://github.com/koenkk/zigbee2mqtt//}}
        \item mosquitto.org: Startseite\\ 
        {\url{https://mosquitto.org//}}
 		\item Li (2017): Was ist ein Smart-Home-Hub? Alles über die intelligente Zentrale\\ {\url{https://www.otto.de/updated/ratgeber/erklaert-was-ist-ein-smart-home-hub-80634/}}
 		\item Robert (2019): Antwort auf Creality Ender 3 printer power consumption? - 3dprinting Stack Exchange\\ {\url{https://3dprinting.stackexchange.com/questions/8616/creality-ender-3-printer-power-consumption#8623/}}
 		\item reichelt.de: Produktbeschreibung des Raspberry Pi 4\\{\url{https://www.reichelt.de/raspberry-pi-4-b-4x-1-5-ghz-8-gb-ram-wlan-bt-rasp-pi-4-b-8gb-p276923.html}}
 		\item Wikipedia: Raspberry Pi - Generations\\{\url{https://en.wikipedia.org/wiki/Raspberry_Pi#Generations}}
 		\item Sunfounder: 10.1 Inch Touch Screen for Raspberry Pi(NEW)\\{\url{http://wiki.sunfounder.cc/index.php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}}
 		\item MQTT.org (2021): What is MQTT\\ {\url{https://mqtt.org/faq/}}
 		\item mosquitto.org (2021): Eclipse Mosquitto$^{TM}$ An open source MQTT broker\\ {\url{https://mosquitto.org/}}
 		\item Koen Kanters (2021): Zigbee2MQTT\\ {\url{https://github.com/koenkk/zigbee2mqtt#internal-architecture}}
 		\item Deutscher Gewerkschaftsbund (2021): Mindestlohn 2021/2022: Was ändert sich?\\{\url{https://www.dgb.de/themen/++co++6ca263de-fb0e-11e9-bdcf-52540088cada#wiehoch2021}}
\end{itemize}
Quellen, die für die Herstellung dieser Dokumentation genutzt wurden:
\begin{itemize}
	\item Menmiloud Mohammed: \LaTeX -Tutorial.com\\{\url{https://latex-tutorial.com/}}
	\item Overleaf: \LaTeX -Guides\\{\url{https://www.overleaf.com/learn}}
\end{itemize}

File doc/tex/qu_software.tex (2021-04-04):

\subsection{Verwendete Software}\label{qu_software}
\begin{table}[H]
\begin{tabularx}{\textwidth}{|p{5cm}|p{6cm}|p{3.2cm}|}
 	\hline 
 	\textbf{Software} & \textbf{Verwendung} & \textbf{Version} \\ 
 	\hline 
 	\hline
 	Raspberry Pi OS & Betriebssystem und Oberfläche für Hardware & 5.4 \\ 
 	\hline 
 	Home Assistant & Betriebssystem und Oberfläche für Smart Home & 5.12 \\ 
 	\hline
 	Mosquitto broker & Broker für den MQTT Nachrichtenstandard & 5.1.1 \\ 
 	\hline
 	Zigbee2MQTT & Anbindung von Zigbee an MQTT & 1.18.1-2 \\ 
 	\hline
 	KiCad EDA & Erstellung von Schaltplan und Gerber-Datei des HAT's & 5.1.8 \\ 
 	\hline 
 	TexMaker & Erstellung der Dokumentation & 5.0.4 \\ 
 	\hline
 	\url{overleaf.com } & Gemeinsame Erstellung der Dokumentation & Web \\
 	\hline
 	Fusion360 & Erstellung von Gehäusemodell & 2.0.9849 \\ 
 	\hline
 	CURA & Erstellung von G-Code für 3D-Drucker & 4.7 \\ 
 	\hline
 	GanttProject & Erstellung von Gantt-Diagrammen & 3.0.3 \\ 
 	\hline
 	Autodesk Meshmixer & Vorschau-Render der STL-Dateien & 3.5.474 \\
 	\hline
 	paint.net & Bildmanipulation & 4.2.15\\
 	\hline
 	Win32 Disk Imager & Erstellung der Images aus den Micro-SD-Karten & 1.0 \\
 	\hline
 	7Zip & Komprimieren der Images & 19.00\\
 	\hline
 	\url{shellcheck.net/} & Überprüfung von Bash-Skripten & Web \\
 	\hline
 	\url{deepl.com/translator} & Übersetzungssoftware & Web \\
 	\hline
 	Microsoft Teams & KANBAN Board und die Kommunikation & 1.4.00.7174 \\
 	\hline
\end{tabularx} 
\caption{Verwendete Software}
\label{tab:qu_software}
\end{table}

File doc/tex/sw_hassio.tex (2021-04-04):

\subsection{Home Assistant Supervised}\label{sw_hassio}
Nachdem das Installationsskript (vgl. Abschnitt \ref{ah_skript}: \nameref{ah_skript}) fehlerfrei Home Assistant Supervised installiert hat, können wir mit der Einrichtung über die Weboberfläche fortfahren. 
Dafür öffnen wir, im selben Netzwerk wie unser Raspberry Pi, die Webseite http://<raspberry-pi-adresse>:8123 mit einem beliebigen Browser.\\
\noindent Hier sehen wir einen Anmeldebildschirm (vgl. Abb. \ref{fig:ha1}: \nameref{fig:ha1}) in welchen wir unseren Benutzeraccount mit Passwort für Home Assistant anlegen. 
Anschließend legen wir den Namen und den Standort des Home Assistant fest (vgl. Abb. \ref{fig:ha2}: \nameref{fig:ha2}). 
Der Standort dient der Ermittlung von Wetterdaten und wird für das Geofencing benötigt. 
Auf dem nächsten Bildschirm (vgl. Abb. \ref{fig:ha3}: \nameref{fig:ha3}) können wir bereits vorhandene Smart-Home-Systeme wie Google Cast und Phillips Hue integrieren. 
Da wir allerdings eine eigene Integration von Zigbee Leuchtmitteln anstreben, überspringen wir diesen Schritt. 
Nun leitet uns der Home Assistant auf seine Startseite weiter (vgl. Abb. \ref{fig:ha4}: \nameref{fig:ha4}). 
Dieses Dashboard wird von Home Assistant aus allen ihm bereits bekannten Geräten bzw. Entitäten generiert. 
\begin{figure}[H]
    \begin{subfigure}{.5\linewidth}
        
        \caption[Anmeldebildschirm]{Anmeldebildschirm}
        \label{fig:ha1}
    \end{subfigure}
    \begin{subfigure}{.5\linewidth}
        
        \caption[Festlegen von Name und Standort]{Festlegen von Name und Standort}
        \label{fig:ha2}
    \end{subfigure}
    \begin{subfigure}{.5\linewidth}
        
        \caption[Mögliche Integrationen werden erkannt]{Mögliche Integrationen werden erkannt}
        \label{fig:ha3}
    \end{subfigure}
    \begin{subfigure}{.5\linewidth}
        
        \caption{erstes Dashboard}
        \label{fig:ha4}
    \end{subfigure}
    \label{fig:Einrichtung des Home Assistant}
\end{figure}

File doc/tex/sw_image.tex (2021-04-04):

\subsection{Erstellung des Betriebssystem-Image}\label{sw_image}
Nach erfolgreichem Test des Installationsskripts\footnote{Siehe Abschnitt \ref{ah_skript}: \nameref{ah_skript}} haben wir für je einen Raspberry Pi 3 und einen Raspberry Pi 4 ein Image erstellt.\\
\noindent Hierzu haben wir mit Hilfe des Raspberry Pi Imagers eine 8 Gigabyte große Micro-SD-Karte\footnote{Zum Zeitpunkt der Erstellung des Images kleinstmögliche vorhandene Micro-SD-Karte} mit Raspberry Pi OS in der 32-Bit-Variante geflasht. 
Dieser kann über die Tastenkombination [STRG]+[SHIFT]+[X] die Grundeinstellungen wie SSH, Domänennamen und Passwort festlegen (vgl. \ref{fig:create_image_01}).
Dementsprechend wurden für die beiden Versionen folgende Einstellungen vorgenommen:\\
\begin{table}[H]
    \begin{tabularx}{\textwidth}{|p{3cm}|p{3cm}|p{4cm}|p{3.7cm}|}
        \hline
        \textbf{Image-Name} & \textbf{User} & \textbf{Passwort} & \textbf{Domänenname} \\
        \hline
        \hline
        \texttt{shz\_rp3.img.gz} & pi & raspberry & shzpi3\\
        \hline
        \texttt{shz\_rp4.img.gz} & pi & raspberry & shzpi4\\
        \hline
    \end{tabularx}
    \caption{Überblick über die Images für die Raspberry Pis}
    \label{tab:image_uebersicht}
\end{table}
\noindent Nachdem das Image auf die SD-Karte geflasht wurden, haben wir die Raspberry Pis mit den entsprechenden Karten bestückt und uns per SSH mit den Geräten verbunden.\\
\noindent Der Shell-Befehl hierfür lautet:
\mint{bat}|ssh pi@<Domänenname>|.
\noindent Mit der Verwendung des Standardpassworts haben wir uns mit den Raspberry Pis verbunden (vgl. Tab. \ref{tab:image_uebersicht}: \nameref{tab:image_uebersicht}).\\
\noindent Anschließend haben wir das Skript auf dem Pi eingerichtet und gestartet (vgl. \ref{fig:create_image_02}).
Nach der Ausführung des Skriptes (vgl. \ref{fig:create_image_03}) wurde die SD-Karte mit Win32 Disk Imager in eine .img-Datei konvertiert (vgl. \ref{fig:create_image_04}).
Anschließend wurde das Image mit 7Zip komprimiert, um Speicherplatz zu sparen (vgl. \ref{fig:create_image_05}). Diese Images können dann mit dem Raspberry Pi Imager\footnote{Alternative: balnea Etcher} wieder auf SD-Karten geflasht werden.\\
\noindent Die Images\footnote{Stand: Ende März 2021} können über folgende Links heruntergeladen werden:
\begin{itemize}
    \item Raspberry Pi 3 Image: \url{https://www.mediafire.com/file/bc2o542na3rea7j/shz_rp3.img.gz/file}
    \item Raspberry Pi 4 Image: \url{https://www.mediafire.com/file/eujoh6s4thpg363/shz_rp4.img.gz/file}
\end{itemize}
\begin{figure}[H]
    \begin{subfigure}[b]{0.5\linewidth}
        
        \caption[Einstellungen des Raspberry Pi Imager]{Einstellungen des Raspberry Pi Imager}
        \label{fig:create_image_01}
    \end{subfigure}
    \begin{subfigure}[b]{0.5\linewidth}
        
        \caption[Durchgeführte Befehle auf Raspberry Pi]{Durchgeführte Befehle auf Raspberry Pi}
        \label{fig:create_image_02}
    \end{subfigure}
    \begin{subfigure}[b]{0.5\linewidth}
        
        \caption[Letze Ausgabe des Pi]{Letzte Ausgabe des Pi}
        \label{fig:create_image_03}
    \end{subfigure}
    \begin{subfigure}[b]{0.5\linewidth}
        
        \caption[Erstellen des Images]{Erstellen des Images}
        \label{fig:create_image_04}
    \end{subfigure}
    \begin{subfigure}[b]{0.5\linewidth}
        
        \caption[7Zip-Einstellungen]{7Zip-Einstellungen}
        \label{fig:create_image_05}
    \end{subfigure}
    \caption[Erstellen der Images]{Erstellen der Images}
    \label{fig:create_image}
\end{figure}

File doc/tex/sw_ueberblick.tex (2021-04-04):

\subsection{Überblick}\label{sw_ueberblick}
Auf der Softwareseite dient Raspberry Pi OS\footnote{Raspberry Pi OS with Desktop, Kernel Version 5.4} als Basis für die Smart Home Zentrale.
Darauf können die gewählten Softwarelösungen verwendet werden:
\begin{itemize}
    \item Home Assistant Supervised (Web Oberfläche und Verwaltung)
    \item Mosquitto Broker (MQTT Broker)
    \item Zigbee2mqtt (Zigbee-Schnittstelle).
\end{itemize}
\noindent Zur Installation der einzelnen Komponenten und für die Vorkonfiguration des Systems haben wir ein Bash-Skript (vgl. \ref{ah_skript}) erstellt, dass das Betriebssystem entsprechend vorbereitet und den Home Assistant Supervised installiert.\\
\noindent Wir haben uns für die oben genannte Implementierung von MQTT und Zigbee2MQTT entschieden, da unsere Versuche, den Mosquitto Broker sowie Zigbee2MQTT als seperate Docker Container zu installieren, zwar erfolgreich waren, allerdings die Ergebnisse nicht zuverlässig reproduzierbar waren. 
Eine Installation beider Komponenten via Home Assistant Superviser Add-on Shop stellt eine zuverlässige Methode dar und unterscheidet sich hinsichtlich der Funktionalität nicht, weshalb wir uns für die Verwendung des Add-on Shops entschieden haben.

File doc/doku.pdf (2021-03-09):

TECHNIKERARBEIT; RASPBERRYPI; Betreut durch Matthias KOHLER; 9. Marz 2021 ¨

ENTWICKLUNG EINER SMART HOME
ZENTRALE AUF BASIS EINES

Felix KUSCHEL & Manuel STARZ

KUSCHEL & STARZ

## Inhaltsverzeichnis

1 Vorwort | 3
2 Quellen | 4
3 Anhang | 5
FTI2 2020/2021 | 1

## Erklarung ¨

Wir versichern, dass die vorliegende Abschlussarbeit von uns selbststandig ange- ¨ fertigt und nur die angegebenen Hilfsmittel benutzt wurden. An Stellen, die dem Wortlaut oder dem Sinne nach anderen Werken entnommen sind, haben wir dies durch die Angabe der Quellen kenntlich gemacht.

Datum, Ort | Felix Kuschel
Datum, Ort | Manuel Starz

## 1 Vorwort

### 1.1 Einleitung

Bei dieser Ausarbeitung handelt es sich um die Abschlussarbeit zur Weiterbildung zum staatlich gepruften Techniker in der Fachrichtung Informationstechnik. Diese ¨ Arbeit basiert auf dem in den zwei Jahren erlernten Stoffs sowie selbst erarbeiteten Kenntnissen und dient zur Feststellung des Erreichen des Fortbildungsziels.

### 1.2 Projektrahmen

Das Projekt zur Erstellung einer Smart Home Zentrale wurde von uns, Felix Kuschel und Manuel Starz, durchgefuhrt. Der Projektzeitraum war vom 1. September 2020 bis ¨ zum 30.03.2021 angesetzt. Es stand zur Umsetzung des Projekts ein unterrichtsfreier Tag pro Woche zur Verfugung. ¨
Des weiteren wurden die in dem Zeitraum zur Verfugung stehenden Ferien ¨ zur Umsetzung des Projekts genutzt. Die Projektbetreuung erfolgten seitens der Schule durch Herr Matthias Kohler. Da das Projekt nicht in Zusammenarbeit mit einem Unternehmen durchgefuhrt wurde, gibt es keine weiteren Betreuer. Die ¨ Materialkosten fur die im Projekt genutzte Hardware wurde von den uns selbst ¨ getragen.

### 1.3 Aufgabenstellung

Das Projekt ist aus dem Zusammenschluss der Abschlussarbeitsideen von uns, Felix Kuschel und Manuel Starz, entstanden und wurde mit Rucksprache mit dem ¨ betreuenden Lehrer entwickelt.
Durch die große Verfugbarkeit von Smart Home Ger ¨ | aten und den zahlreichen ¨
Standards der Anbieter entschlossen wir uns, eine einfache und leicht zu replizieren-
de Losung zu entwickeln, die Smart Home Ger ¨ | ate mehrerer Hersteller miteinander ¨
verknupft und so die Notwendigkeit mehrerer verschiedener sogenannter Hubs zu ¨ eliminieren.
Des weiteren soll das Gerat noch ¨ | uber einen Touchscreen steuerbar sein und die ¨
Werte der verbundenen Smart Home Gerate anzeigen. Dies umfasst unter anderem ¨ den Status von Leuchtmitteln, die Werte von Thermostaten sowie den Zustand von Tur- und Fensterkontakten. Die genaue Aufgabenstellung kann dem abgegebenen ¨ Lastenheft im Anhang entnommen werden.

### 1.4 Zusatzinformationen

Die Rohdaten des Projekts wurden der Einfachheit in einem GIT-Projekt zusammen-
gefasst. Dadurch konnten die Durchfuhrenden unabh ¨ | angig voneinander an dem ¨
Projekt und der Dokumentation arbeiten.
Der Link zu dem Projekt lautet:
https://github.com/Pharias/TAR
Ursprunglich wurde f ¨ | ur die Verwendung des schulinternen GIT verwendet. Dies ¨
stand zum Zeitpunkt der Erstellung der Dokumentation allerdings nicht zur Verfugung, ¨ weshalb eine Alternative genutzt wurde.

## 2 Quellen

### 2.1 Verwendete Software

Software | Verwendung | Version
Raspberry Pi OS | Betriebssystem und Oberflache f ¨ ur Hardware ¨ | 5.4
Home Assistant | Betriebssystem und Oberflache f ¨ ur Smart Home ¨ | 5.12
KiCad EDA | Erstellung von Schaltplan und Gerber-Datei des Hats | 5.1.8
TexMaker | Erstellung der Dokumentation | 5.0.4
- | • | •

### 2.2 Verwendete Hardware

Hardware | Verwendung | Version
Raspberry Pi | Hauptplatine fur die ¨ Smart Home Zentrale | Version 4B (8GB)
CC2531 Zigbee USB Stick mit Firmware | USB-Stick mit ZigBee-Chip | Rev 2.4
Sunfounder 10.1 Touch Screen | Bildschirm und Input fur¨ die Smart Home Zentrale | Unbekannt

## 3 Anhang

### 3.1 Lastenheft

TAR
Erstellt am: 04.06.2020
Lastenheft | 12:40:00
SmartHome e.V.
An der Ecke 12
70707 Kleinstadt

# Lastenheft

I. VERANLASSUNG

Der Smart–Home Sektor wird zu einem immer größer werdenden Markt und immer mehr Hersteller liefern neue Produkte um das eigene Haus zu steuern. Um einen zentralen Informationspunkt oder eine zentrale Steuereinheit einzurichten, soll ein Produkt entwickelt werden, welches sich mit Smart-Home-Anwendungen verschiedener Hersteller verbinden kann, um deren Produkte dann per Touchscreen oder wahlweise per Sprachassistent steuern kann.
II. PROJEKTUMFELD

Für das Projekt stehen diverse Smart-Home-Komponenten zur Verfügung, darunter unter anderem die Smart-Lampen von IKEA, Phillips Hue und diverse Zigbee Komponenten.
III. ZIELBEDINGUNG

Das Produkt soll eine Lösung zur Verknüpfung von Smart-Home-Geräten via Zigbee-Bridge darstellen und einen Sprachassistenten integrieren, in diesem Fall MyCroft. Darüber soll das Produkt als zentrale Steuereinheit für die angebundenen Sensoren und Geräte dienen und den Status dieser in einem kompakten Display darstellen.
IV. PRODUKTEINSATZ

Das Produkt dient zur Steuerung eigener Zigbee fähiger Smart-Home-Komponenten. Als solches kann es vom Kunden im eigenen Netz integriert werden und dient dort als Steuerung oder Übersicht der eigenen Smart-Home-Geräten
V. PRODUKTMERKMALE
V.1. | Hardware in einem Gehäuse (Touch-Bildschirm mit Raspberry Pi 4B als „Gehirn“)
V.2. | Dashboard-Funktion für Smart-Home-Geräte
V.3. | Integration von Zigbee, MQTT
V.4. | GUI erstellt über Java oder als WebUI (eventuell als SmartPhone-App)
V.5. | Mögliche Integration von Sprachassistenten MyCroft

VI. PRODUKTDATEN

Das Gerät soll neben Daten der Sensoren (Luftdruck, Temperatur, Feuchtigkeit, etc.) auch den Zustand von anderen Smart-Home-kompatiblen Geräten anzeigen können (ein- oder ausgeschaltet, Fenster offen, etc.)
VII. ABLAUFORGANISATION

Die Abläufe für die in Punkt V genannten Vorgänge entsprechen zum Großteil dem geplanten Umfang des Projekts. Zusätzlich soll noch ein Gehäuse entwickelt werden, dass die Hardware (Bildschirm, SBC, Mikrofon und eventuell Kamera und Netzteil) in einem Gerät vereint. Weitere Produktfähigkeiten werden bei Bedarf nachgereicht. Der Projektablauf soll als SCRUM stattfinden, ein Sprint hat die geplante Dauer von einem Monat.

FTI1 | Seite 1 von 2 | Manuel Starz;Felix Kuschel
Lastenheft.docx FTI2 2020/2021 | 5

TAR
Erstellt am: 04.06.2020
Lastenheft | 12:40:00

VIII. PRODUKTLEISTUNG

Sehr gut | Gut | Normal | Nicht Relevant
Funktionalität | | x
Bedienerfreundlichkeit | x
Änderbarkeit | | x
Erweiterbarkeit | | | x
FTI1 | Seite 2 von 2 | Manuel Starz;Felix Kuschel
Lastenheft.docx FTI2 2020/2021 | 6

### 3.2 Hardware-Dokumentationen

Durch den Umfang der einzelnen Dokumentationen hier nur eine Auflistung der Dokumentationen mit dem Link zu den PDF im GIT-Projekt bzw. den Herstellerseiten.

- Raspberry Pi:
https://www.raspberrypi.org/documentation/hardware/raspberrypi/bcm2711/rpi_DATA_2711_1p0.pdf (https://www.raspberrypi.org/documentation/hardware/raspberrypi/bcm2711/rpi_DATA_2711_1p0.pdf)
- MiFare MFRC522:
https://www.nxp.com/docs/en/data-sheet/MFRC522.pdf
- CC2531 ZigBee SoC:
https://www.ti.com/lit/ds/symlink/cc2531.pdf
- ATmega128RFA1-ZU:
https://ww1.microchip.com/downloads/en/DeviceDoc/Atmel-8266-MCU_Wireless-ATmega128RFA1_Datasheet.pdf (https://ww1.microchip.com/downloads/en/DeviceDoc/Atmel-8266-MCU_Wireless-ATmega128RFA1_Datasheet.pdf)

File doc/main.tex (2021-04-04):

\documentclass[12pt,a4paper]{article}
% Encoding
\usepackage[utf8]{inputenc}
\usepackage[T1]{fontenc}
% Deutsches Sprachpaket
\usepackage[ngerman]{babel}
% Font: Helvetica
\usepackage{helvet}
\renewcommand{\familydefault}{\sfdefault}
\usepackage{amsmath}
\usepackage{amsfonts}
\usepackage{amssymb}
\usepackage{graphicx}
\usepackage[left=3cm,right=2.5cm,top=2.5cm,bottom=2.5cm]{geometry}
\usepackage[headsepline,footsepline]{scrlayer-scrpage}
\usepackage{microtype}
\usepackage{pdfpages}
\usepackage{color}
\usepackage{listings}
\usepackage{minted}
\usepackage{xcolor}
\usepackage[bottom,hang]{footmisc}
% Farben für Codehighlighting unter listings
\definecolor{codegreen}{rgb}{0,0.6,0}
\definecolor{codegray}{rgb}{0.5,0.5,0.5}
\definecolor{codepurple}{rgb}{0.58,0,0.82}
\definecolor{backcolour}{rgb}{0.95,0.95,0.92}
\usepackage[hyphens]{url}
\usepackage[official]{eurosym}
\usepackage{array}
\usepackage{subcaption}
\usepackage{tabularx}
\usepackage{lastpage}
\usepackage[colorlinks=true,urlcolor=blue,linkcolor=black]{hyperref}
\hyphenpenalty=9999
\exhyphenpenalty=9999
\setlength{\headheight}{25pt}
\pagestyle{scrheadings}
\clearpairofpagestyles
\clearmainofpairofpagestyles
\clearplainofpairofpagestyles
\author{Felix Kuschel
	\and Manuel Starz}
\title{Entwicklung einer Smart Home Zentrale auf Basis eines RaspberryPI}
% Kopfzeile
\ihead{}
\chead{}
\ohead{\textsc{Seite \pagemark\:von \pageref{LastPage}}}
% Fußzeile
\ifoot{\textsc{FTI2 2020/2021}}
\cfoot{}
% Achtung, Muss 2 mal comilieren, sonst Fehler bei maximalen Seitenanzahl.
\ofoot{\textsc{Kuschel \& Starz}} 
\date{-}
\definecolor{quotetext}{rgb}{.35,.35,.35} %{1,.64,0}
% Codehighlighting stylesheet
\lstdefinestyle{mystyle}{
    backgroundcolor=\color{backcolour},   
    commentstyle=\color{codegreen},
    keywordstyle=\color{magenta},
    numberstyle=\tiny\color{codegray},
    stringstyle=\color{codepurple},
    basicstyle=\ttfamily\footnotesize,
    breakatwhitespace=false,         
    breaklines=true,                 
    captionpos=b,                    
    keepspaces=true,                 
    numbers=left,                    
    numbersep=5pt,                  
    showspaces=false,                
    showstringspaces=false,
    showtabs=false,                  
    tabsize=2
}
\lstset{style=mystyle}
\begin{document}
	% Titelseite
	\input{tex/titelseite}
	% Inhaltsverzeichnis
	\tableofcontents
	\newpage
	% Erklärung
	\input{tex/erklaerung}
	% Vorwort
 	\input{tex/vorwort}
 	% Zielsetzung
	\input{tex/zielsetzung}
	% Herangehensweise
	\input{tex/herangehensweise}
	% Zeitplan
	\input{tex/zeitplan}
	% Komplettübersicht
	\input{tex/komplettuebersicht}
	% Hardware
	\input{tex/hardware}
	% Software
	\input{tex/software}
	% Epilog & Fazit
	\input{tex/fazit}	
	% Quellen
	\input{tex/quellen}
	% Anhang
 	\input{tex/anhang}
 	% Überschrift für Verzeichnisse
 	\section{Verzeichnisse}
 	% Tabellenverzeichnis
    \listoftables
 	% Abbildungsverzeichnis
 	\listoffigures
\end{document}

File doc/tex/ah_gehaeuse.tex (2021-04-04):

\subsection{Gehäuse-Zeichunungen}\label{ah_gehaeuse}

\label{fig:case_footprint}
Erster Versuch der Zeichnung des Fußabdruckes des Gehäuses
\newpage

\label{fig:case_footprint_final}
Finale Version der Zeichnung des Fußabdruckes des Gehäuses
\newpage

Linker Teil des Gehäuses
\label{fig:case_left}
\newpage

Rechter Teil des Gehäuses
\label{fig:case_right}
\newpage

Ein Teil des Gehäusesdeckels
\label{fig:case_back}
\newpage

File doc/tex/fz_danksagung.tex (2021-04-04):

\subsection{Danksagung}\label{fz_danksagung}
Danke an unsere Freundinnen, die uns den Rücken so gut es ging freigehalten haben und uns zwei Nerds unterstützt haben, wo sie nur konnten.
Danke an unsere Familien, die uns mit ihren Weisheiten und Erfahrungen weiterhelfen konnten.
Danke an unsere Lehrer, die sich die letzten zwei Jahre mit uns herumquälen durften.

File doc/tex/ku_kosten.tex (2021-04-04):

\subsection{Kostenaufstellung}\label{ku_kosten}
Im Anschluss haben wir die Kosten des Projekts dargestellt (vgl. Tab \ref{tab:ku_gesamtkostenberechnung}: \nameref{tab:ku_gesamtkostenberechnung}\par
% Beschaffungskosten
\input{tex/ku_kosten_beschaffung}
\newpage
% Arbeitszzeit
\input{tex/ku_kosten_zeit}
% Kosten 3D-Druck
\input{tex/ku_kosten_druck}
% Kosten Präsentationsaufbau
\input{tex/ku_kosten_praesi}
% Gesamtkosten
\input{tex/ku_kosten_gesamt}

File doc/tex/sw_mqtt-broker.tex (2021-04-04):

\subsection{Mosquitto Broker}\label{sw_mqtt-broker}
Als erste wichtige Erweiterung benötigen wir für unseren Home Assistant einen MQTT Broker. 
Da wir eine Supervised Version des Home Assistant auf unserem Pi vewenden, nutzen wir für die Installation den Supervisor Add-on Shop von Home Assistant (vgl. Abb.  \ref{fig:ha11}: \nameref{fig:ha11}).\\
\noindent Hier wählen wir den Mosquitto Broker zur Installation aus (vgl. Abb. \ref{fig:ha12}: \nameref{fig:ha12}). 
Um den Mosquitto Broker zu aktivieren, navigieren wir über den Menüpunkt ,,Einstellungen'' zum Punkt ,,Integrationen'' und suchen dort nach MQTT. 
Wir aktivieren die Verknüpfung von Home Assistant und Mosquitto Broker, indem wir die Schaltfläche ,,Suche aktivieren'' klicken.
Nach Durchführung dieser Schritte ist der Mosquitto Broker aktiv.
\begin{figure}[H]
    \begin{subfigure}{.5\linewidth}
        
        \caption{Supervisor Dashboard}
        \label{fig:ha5}
    \end{subfigure}
    \begin{subfigure}{.5\linewidth}
        
        \caption{Supervisor Add-on Shop}
        \label{fig:ha6}
    \end{subfigure}
    \begin{subfigure}{.5\linewidth}
        
        \caption{MQTT add-on seite}
        \label{fig:ha7}
    \end{subfigure}
    \begin{subfigure}{.5\linewidth}
        
        \caption{Einstellungen}
        \label{fig:ha8}
    \end{subfigure}
    \begin{subfigure}{.5\linewidth}
        
        \caption{Startseite Integrationen }
        \label{fig:ha11}
    \end{subfigure}
    \begin{subfigure}{.5\linewidth}
        
        \caption{Suchfunktion Integrationen }
        \label{fig:ha12}
    \end{subfigure}
    \begin{subfigure}{.5\linewidth}
        
        \caption{Suche nach MQTT }
        \label{fig:ha13}
    \end{subfigure}
\end{figure}

%\begin{figure}[H]
%    \includegraphics[width=1\textwidth]{img/HA6.png}
%    \caption{Supervisor Dashboard}
%    \label{fig:ha5}
%\end{figure}
%\begin{figure}[H]
%    \includegraphics[width=1\textwidth]{img/HA7.png}
%    \caption{Supervisor Add-on Shop}
%    \label{fig:ha6}
%\end{figure}
%\begin{figure}[H]
%    \includegraphics[width=1\textwidth]{img/HA8.png}
%    \caption{MQTT add-on seite }
%    \label{fig:ha7}
%\end{figure}
%\begin{figure}[H]
%    \includegraphics[width=1\textwidth]{img/HA9.png}
%    \caption{Einstellungen}
%    \label{fig:ha8}
%\end{figure}
%\begin{figure}[H]
%    \includegraphics[width=1\textwidth]{img/HA10.png}
%    \caption{Benuterverwaltung}
%    \label{fig:ha9}
%\end{figure}
%\begin{figure}[H]
%    \includegraphics[width=1\textwidth]{img/HA11.png}
%    \caption{Benutzer MQTT anlegen }
%    \label{fig:ha10}
%\end{figure}

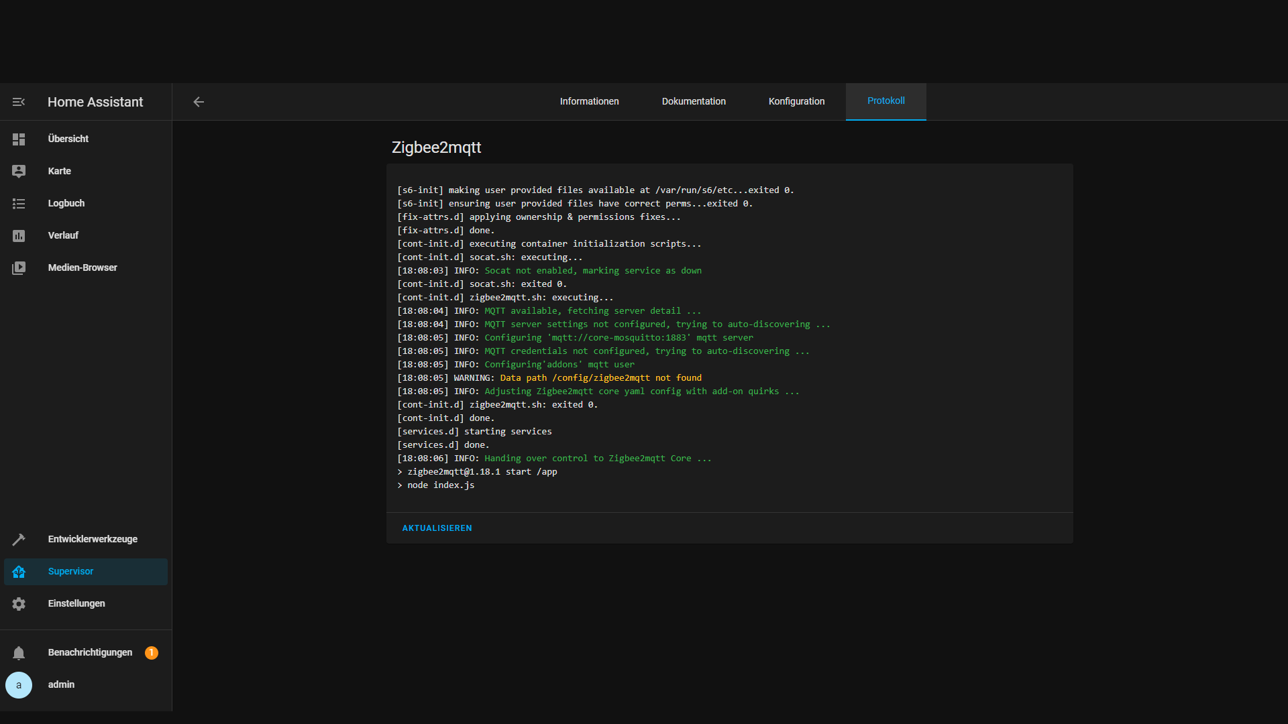
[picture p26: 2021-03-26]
doc/img/HA22.png

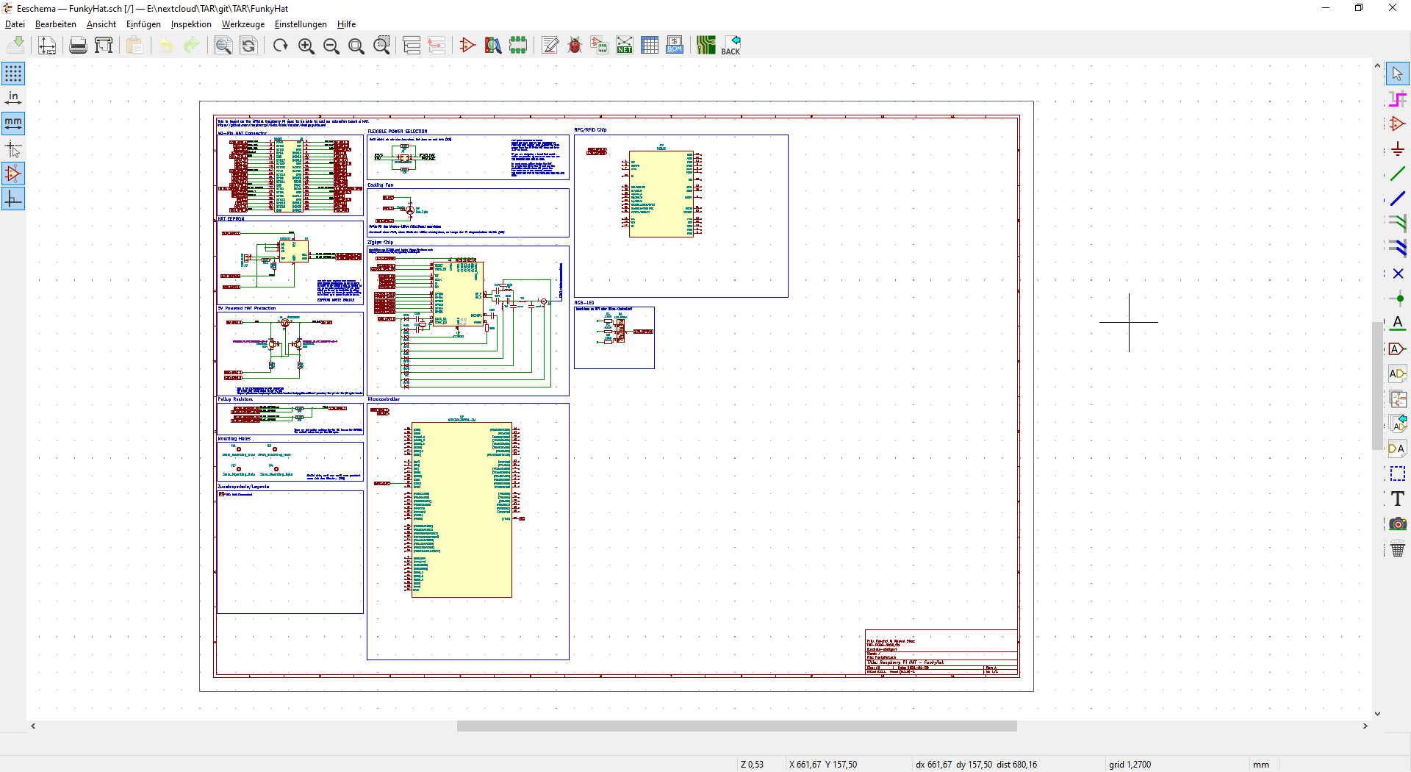
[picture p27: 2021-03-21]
doc/img/hat_schaltplan.png

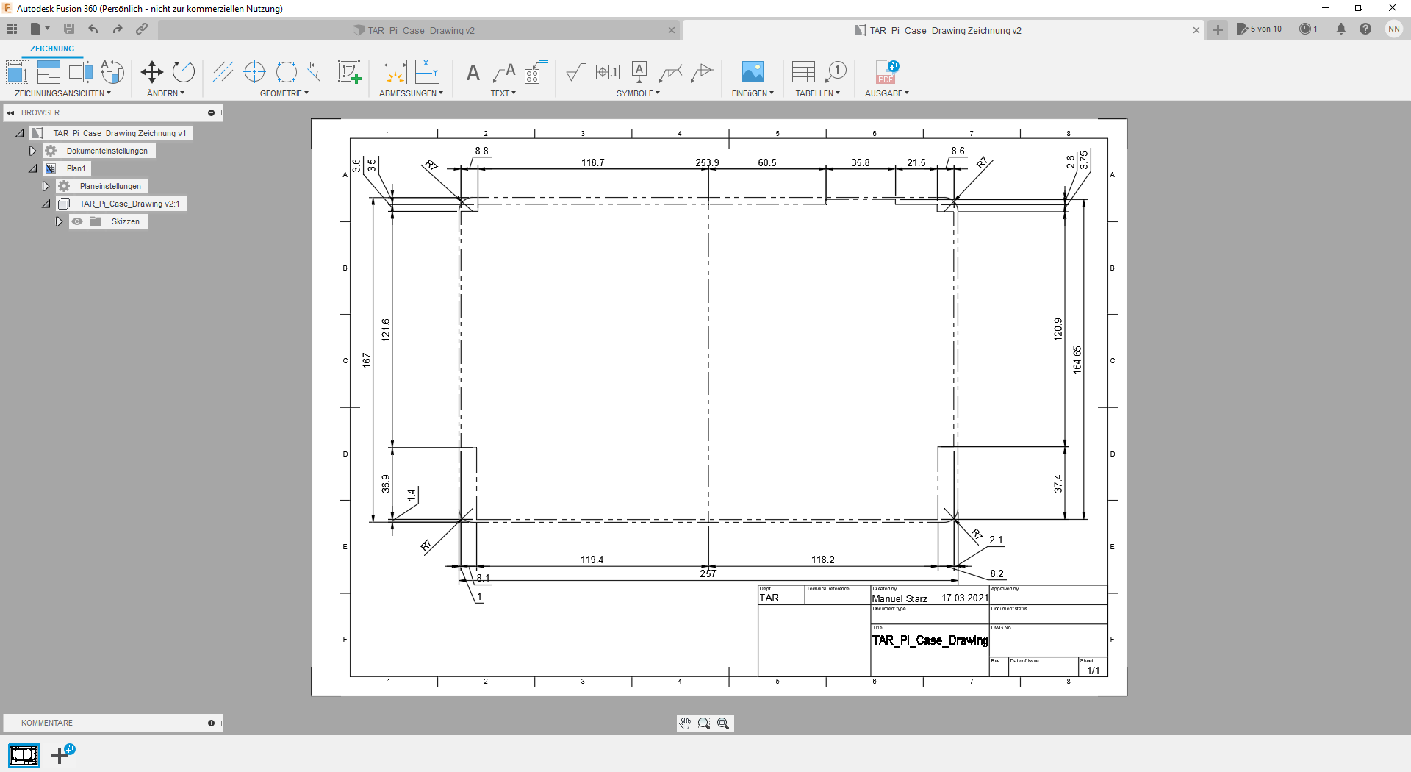
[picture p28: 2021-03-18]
doc/img/konstruktion_gehaeuse_004.png

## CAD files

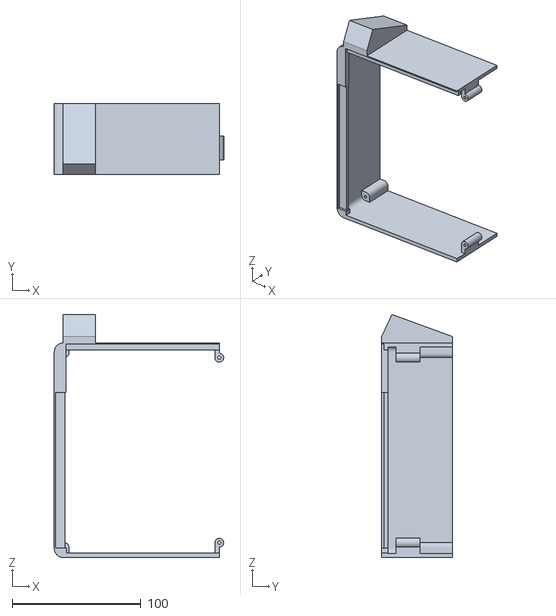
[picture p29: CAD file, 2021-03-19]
Case/TAR_Pi_Case_stand_left.stl
132.0 x 55.0 x 189.1

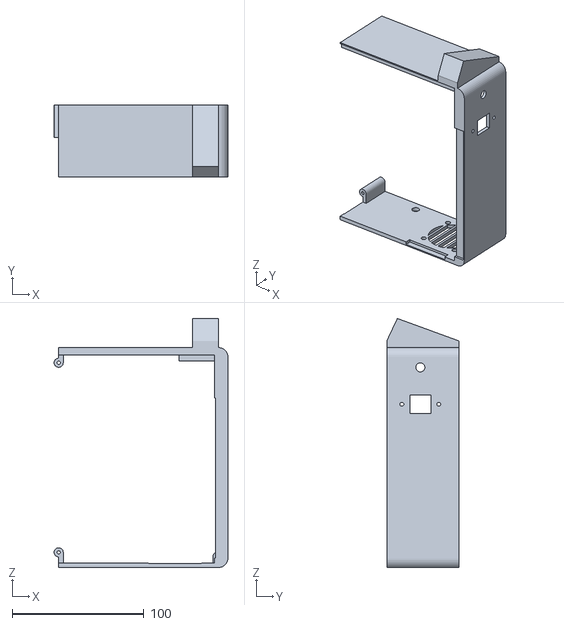
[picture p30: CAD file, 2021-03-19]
Case/TAR_Pi_Case_stand_right.stl
132.0 x 55.0 x 189.1

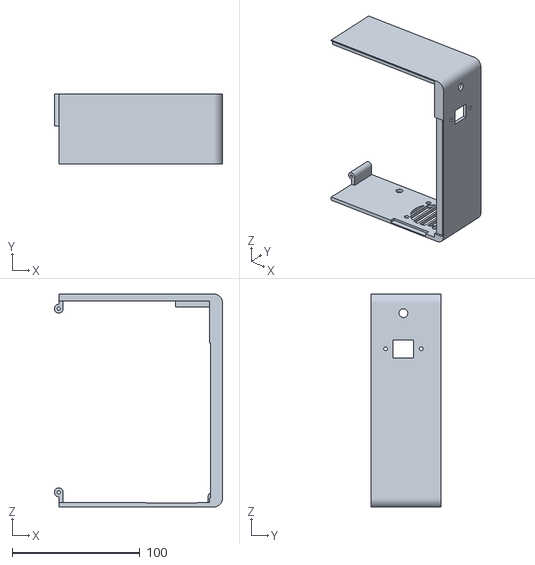
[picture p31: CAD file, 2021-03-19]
Case/TAR_Pi_Case_right.stl
132.0 x 55.0 x 167.0

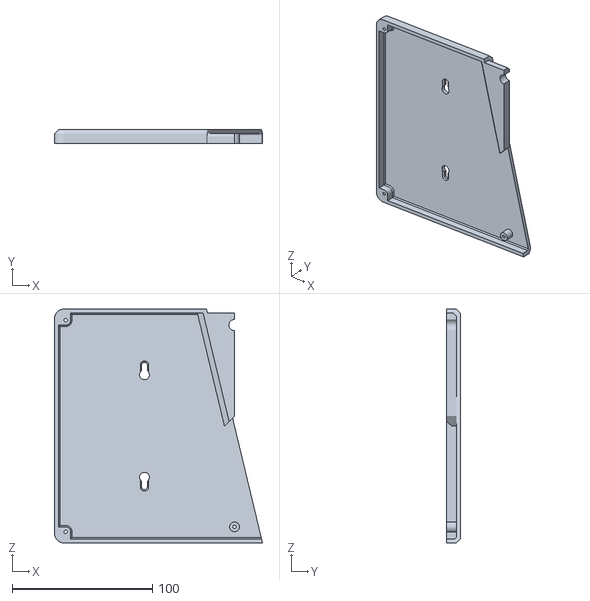
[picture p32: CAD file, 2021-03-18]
Case/TAR_Pi_Case_back.stl
148.5 x 10.0 x 167.0

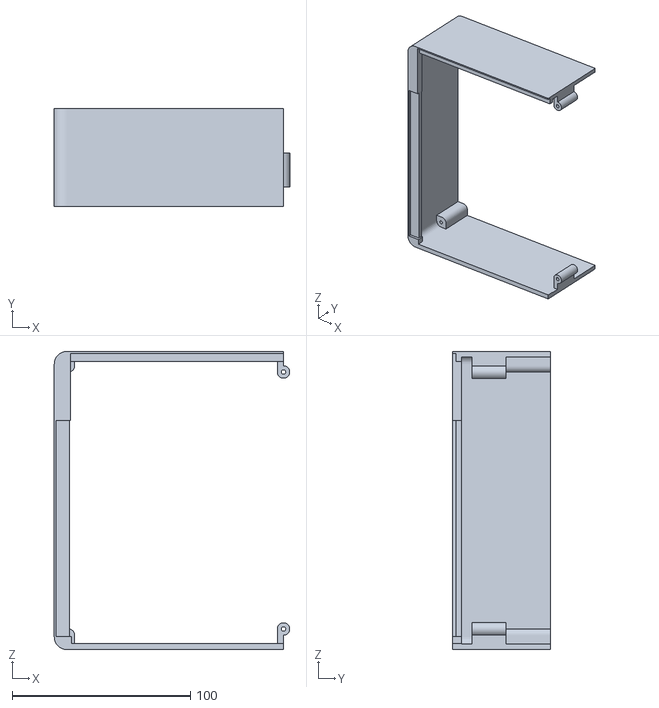
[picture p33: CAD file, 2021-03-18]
Case/TAR_Pi_Case_left.stl
132.0 x 55.0 x 167.0

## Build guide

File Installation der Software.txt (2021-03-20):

Instalation von Home Assistan in Dockercontainer innerhalb von RaspberryPiOs

Schritt 1 - Raspberry Pi OS Installieren

Raspberry Pi OS auf SD Karte Installieren via PiImager

Schritt 2 - Docker Installieren 

sudo apt-get update
sudo apt-get upgrade
sudo reboot

curl -fsSL https://get.docker.com -o docker-script.sh
sudo sh docker-script.sh

**bei fehler**
sudo dpkg --configure -a

sudo usermod -aG docker pi

**Validierung**
docker info

Schritt 3 - Home Assistant Container Installieren

**Verzeichnis für docker erstellen**
mkdir /home/pi/docker/homeassistant

docker run --init -d \
  --name homeassistant \
  --restart=unless-stopped \
  -v /etc/localtime:/etc/localtime:ro \
  -v /home/pi/docker/homeassistant:/config \
  --network=host \
  homeassistant/raspberrypi3-homeassistant:stable
  
Schritt 4 - MQTT server in Docker Container installieren

**Verzeichnis für Mqtt erstellen**
mkdir /home/pi/docker/mqtt

Schritt 5 - Zigbee2Mqtt Installieren

**Verzeichnis für Zigbee2Mqtt erstellen**
mkdir /home/pi/docker/zigbee2mqtt

docker run \
   -it \
   -v /home/pi/docker/zigbee2mqtt \		// Verzeichnis von Zigbee2Mqtt	
   --device=/dev/ttyACM0 \				// ort des Adapters
   -e TZ=Europe/Berlin \				// Zeitzone
   -v /run/udev:/run/udev:ro \			
   --privileged=true \
   koenkk/zigbee2mqtt  
   
**cc2531 identifizieren**

sudo lsusb -v

**Regel Konfigurieren idVendor = [] idProduct =[]**

echo "SUBSYSTEM==\"tty\", ATTRS{idVendor}==\"0451\", ATTRS{idProduct}==\"16a8\", SYMLINK+=\"cc2531\",  RUN+=\"/usr/local/bin/docker-setup-cc2531.sh\"" | sudo tee /etc/udev/rules.d/99-cc2531.rules
sudo udevadm control --reload-rules

**docker setup erstellen**

sudo nano /usr/local/bin/docker-setup-cc2531.sh

#!/bin/bash
 USBDEV=`readlink -f /dev/cc2531`
 read minor major < <(stat -c '%T %t' $USBDEV)
 if [[ -z $minor || -z $major ]]; then
     echo 'Device not found'
     exit
 fi
 dminor=$((0x${minor}))
 dmajor=$((0x${major}))
 CID=`docker ps -a --no-trunc | grep koenkk/zigbee2mqtt | head -1 |  awk '{print $1}'`
 if [[ -z $CID ]]; then
     echo 'CID not found'
     exit
 fi
 echo 'Setting permissions'
 echo "c $dmajor:$dminor rwm" > /sys/fs/cgroup/devices/docker/$CID/devices.allow
 
**Berechtigungen Erteilen**
 
sudo chmod 744 /usr/local/bin/docker-setup-cc2531.sh

**event listener erstellen**

sudo nano /usr/local/bin/docker-event-listener.sh

 #!/bin/bash
 docker events --filter 'event=start'| \
 while read line; do
     /usr/local/bin/docker-setup-cc2531.sh
 done
 
**Berechtigungen Erteilen**

sudo chmod 744 /usr/local/bin/docker-event-listener.sh

**listener service erstellen**

sudo nano /etc/systemd/system/docker-event-listener.service

[Unit]
 Description=Docker Event Listener for TI CC2531 device
 After=network.target
 StartLimitIntervalSec=0
 [Service]
 Type=simple
 Restart=always
 RestartSec=1
 User=root
 ExecStart=/bin/bash /usr/local/bin/docker-event-listener.sh

 [Install]
 WantedBy=multi-user.target
 
 **Berechtigungen Erteilen**

sudo chmod 744 /etc/systemd/system/docker-event-listener.service

**Deamon neuladen**
sudo systemctl daemon-reload

sudo systemctl start docker-event-listener.service
sudo systemctl status docker-event-listener.service
sudo systemctl enable docker-event-listener.service

##########################################################################
Quellen
##########################################################################
https://www.zigbee2mqtt.io/information/docker.html
https://www.home-assistant.io/installation/raspberrypi
https://rsw.io/how-to-install-docker-on-a-raspberry-pi/

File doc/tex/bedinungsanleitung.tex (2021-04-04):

Um eine Reibungslose Installation zu ermöglichen haben wir für die Verwendung unseres Prototypen, sowie für die Installation durch Image oder Installationsskript eine Genaue Bedienungsanleitung erstellt. Diese hat als ziel es jedem zu ermöglichen unseren Prototypen in Betierb zu nehmen oder die Software auf bereits vorhandener Hardware zu installieren

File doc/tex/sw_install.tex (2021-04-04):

\subsection{Installationsskript}\label{sw_install}
Das Installationsskript (s. Anhang \ref{ah_skript}: \nameref{ah_skript}) dient dazu, die im Projekt verwendeten Softwarekomponenten möglichst ohne großen Aufwand und mit so wenig Nutzereingaben wie möglich zu installieren und einzurichten. 
Da auf den Raspberry Pis das Debian-Derivat Raspberry Pi OS läuft, handelt es sich beim Installationsskript um ein Bash-Skript.\\
\noindent Das Installationsskript des Home Assistant Supervisors verfügt über viele Ausgaben, sowie eine nicht mit einem Parameter automatisierbare Abfrage.
Aus diesem Grund haben wir das Skript in unser Installationsskript kopiert, die Abfrage entsprechend überbrückt und die Ausgaben in die von unserem Skript genutzte Log-Datei umgeleitet.
Dadurch bekommt der Nutzer im Idealfall lediglich kurze Statusmeldungen über den aktuellen Stand und bei Abschluss der Installation eine Erfolgsmeldung.\\
\noindent Die einzelnen Aufgaben, die das Installationsskript durchführt, wurden in eigene Funktionen ausgegliedert. 
Dadurch lassen sich am Skript selbst schneller Änderungen durchführen. 
Das Skript erkennt dabei über Operatoren, welche Schritte durchgeführt werden sollen und kann so auf neu aufgesetzten als auch auf bereits länger im Benutzung befindlichen Raspberry Pis ausgeführt werden.\\
\noindent So besteht die Möglichkeit, beispielsweise die Installation von Docker oder dem Systemupdate abzulehnen (vgl. \ref{ah_skript}: \nameref{ah_skript} Zeile 34 ff).
Gibt der Nutzer keinen Operanden oder einen ungültigen Operanden an, wird ein Hilfetext mit der Funktion \texttt{show\_help} (vgl. \ref{ah_skript}: \nameref{ah_skript} Zeile 34ff) ausgegeben, der den Nutzer über die Operatoren, sowie eine allgemeine Verwendung des Skripts informiert.\\
\noindent Möchte der Nutzer das komplette Smart Home Zentralen Paket selbst installieren, ist der Operand \texttt{-a} an den Befehl \texttt{./sh\_install} anzuhängen. 
Dadurch wird die Installation vollständig durchgeführt, das heißt, dass ein Systemupdate durchgeführt wird, die Abhängigkeiten Network Manager, AppArmor und JQ, sowie Docker und der Docker-Container Home Assistant Supervised für Raspberry Pi installiert werden.\\
\noindent Möchte der Nutzer die Installation ohne die Ausführung eines vorhergehenden Systemupdates und ohne die Installation von Docker durchführen, kann er das Skript mit dem Operand \texttt{-h} starten, was lediglich den Home Assistant Supervised nach dem offiziellen Skript für die Installation \footnote{GITHUB: supervised-installer \url{https://github.com/home-assistant/supervised-installer}} durchführt.\\ 
\noindent Ob die oben genannten Abhängigkeiten vorhanden sind, wird bei der Installation unabhängig von der Nutzereingabe geprüft und gegebenenfalls bei Fehlen dieser nachinstalliert (vgl. \ref{ah_skript}: \nameref{ah_skript} Zeile 85ff \& \ref{ah_skript} Zeile 297ff: \nameref{ah_skript}).\\
\noindent Sollte das Skript ausgeführt werden, ohne das Docker auf dem Raspberry Pi installiert ist und nur die Installation des Home Assistant Supervised angefordert wird, wird Docker mit installiert (vgl. \ref{ah_skript} Zeile 284ff: \nameref{ah_skript}).
Diese und andere Fehlervermeidungen übernimmt die Funktion \texttt{preflightcheck}, die eventuell vom Nutzer falsch gesetzte Parameter sauber setzt.
Die Installation erfolgt weitestgehend über den internen Paketmanager apt\footnote{Für das Systemupdate und die Installation der Abhängigkeiten.}.\\
\noindent Für Docker wird ein Skript von docker.com heruntergeladen und ausgeführt (vgl. \ref{ah_skript}: \nameref{ah_skript} Zeile 108ff).
Der Abschnitt der Home Assistant Installation basiert auf dem Bash-Skript von Home Assistant selbst\footnote{GITHUB: installer.sh \url{https://github.com/home-assistant/supervised-installer/blob/master/installer.sh}}, wir haben aber die Terminal-Ausgaben des Skripts in unsere Log-Datei umgeleitet und die Abfrage zur Neukonfiguration des Network-Managers unterdrückt.
Lediglich die Ausgaben des Docker-Installationsskripts erscheinen nun noch zusätzlich zu den Statusmeldungen unseres Skripts auf dem Bildschirm.\\
\newpage
\noindent Eine Übersicht und Kurzerklärung der Funktionen im Skript:
\begin{table}[H]
\begin{tabularx}{\textwidth}{|p{4.7cm}|p{8cm}|p{1.5cm}|}
 	\hline 
 	\textbf{Funkion} & \textbf{Kurzbeschreibung} & \textbf{Zeile} \\ 
 	\hline 
 	\hline
 	\texttt{show\_help} & Anzeige der Hilfe im Terminal. & 34 \\ 
 	\hline 
 	\texttt{get\_time} & Aktualisiert die Variable ,,TIMESTAMP''. & 56 \\ 
 	\hline
 	\texttt{run\_update} & Führt \texttt{apt-get update}, \texttt{apt-get uppgrade} \& \texttt{apt-get autoremove} mit automatischer Bestätigung aus. & 60 \\ 
 	\hline
 	\texttt{get\_piver} & Ermittelt die Version des Raspberry Pis und bricht bei unbekannter Version ab. & 68 \\
 	\hline
 	\texttt{install\_dependencies} & Installiert Network-Manager, AppArmor und JQ bei Bedarf. & 85 \\ 
 	\hline 
 	\texttt{install\_docker} & Lädt das Installationsskript von Docker herunter und führt dieses aus. & 105 \\ 
 	\hline
 	\texttt{install\_homeassistant} & Führt Systemvorbereitung und die Installation von Home Assistant durch. & 125 \\
 	\hline
 	\texttt{preflightcheck} & Überprüft das System, ob die Abhängigkeiten installiert sind und ob Docker oder Home Assistant bereits installiert sind. & 277 \\ 
 	\hline
 	\texttt{set\_all} & Setzt die Variablen für eine Komlettinstallation & 345 \\ 
 	\hline
 	\texttt{set\_docker} & Setzt die Variablen für eine Installation von Docker & 352 \\ 
 	\hline
 	\texttt{set\_homeassistant} & Setzt die Variablen für eine Installation von Home Assistant & 356 \\
 	\hline
 	\texttt{set\_update} & Setzt die Variablen für ein Systemupdate & 360\\
 	\hline
\end{tabularx} 
    \caption[Skript-Funktionen]{Skript-Funktionen}
    \label{tab:Skript-Funktionen}
\end{table}

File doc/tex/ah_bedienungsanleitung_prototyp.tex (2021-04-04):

Bedienungsanleitung Des Prototyps

Für die Einrichtung des Geräts werden folgende Dinge benötigt

beiliegendes Netzteil
beiliegende Schrauben und Dübel zur Wandmontage

Schritt 1 - Festlegen des Standorts

geeigneten Montageplatz für die Smart-Home-Zentrale festlegen
    (am besten geeignet ist ein Zentral gelegener Ort)
    
Schritt 2 Monage der Smart-Home-Zentrale

Smart-Home-Zentrale mit den beiliegenden Schrauben an der Wand Befestigen
    (falls auf eine Wandmontage verzichtet wird kann dieser Schritt übersprungen werden)
    
Schritt 3 Netzwerkverbindung herstellen

LAN Verbindung durch ein RJ-45 Netzwerkkabel Herstellen
    (falls eine WLAN Verbindung Genutzt Werden Soll kann dieser Schritt übersprungen werden)
    
Schritt 4 - Spannungsversorgnung herstellen

Stromversorgung für die Smart-Home-Zentrale durch beiliegendes Netzteil Herstellen
    (die Smart-Home-Zentrale Starten darauf hin direkt)
    
Schritt 5 - Einrichtung des Home Assistant

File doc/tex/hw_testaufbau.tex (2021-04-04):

\subsection{Präsentationsaufbau}\label{hw_testaufbau}
\begin{figure}[H]
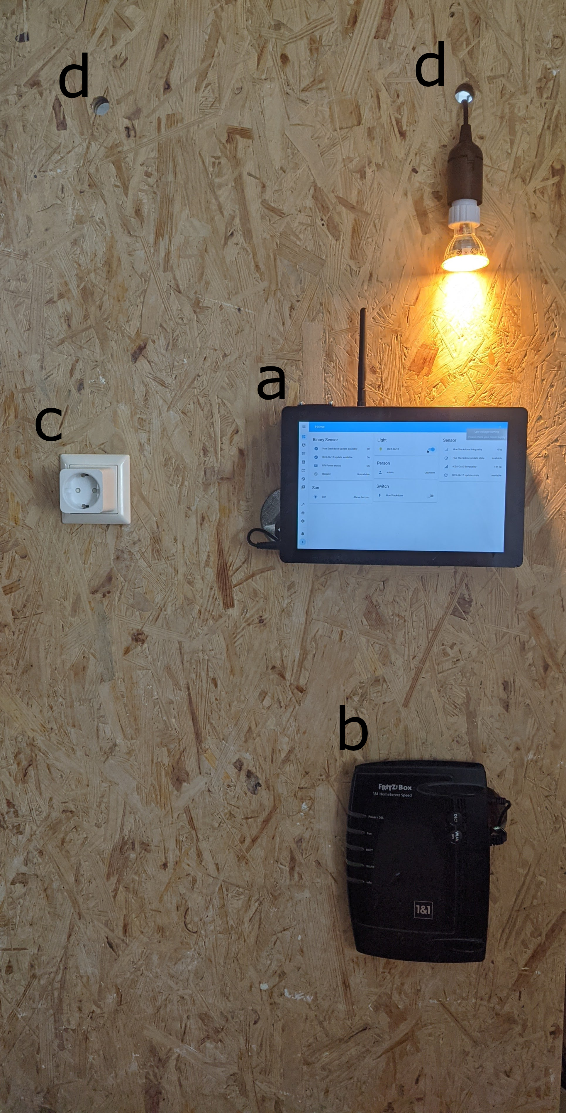
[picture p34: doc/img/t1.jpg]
    
    \caption[Präsentationsaufbau]{Präsentationsaufbau}
    \label{fig:praesentationsaufbau}
\end{figure}
Um die Ergebnisse unseres Technikerarbeit und unserem Prototypen präsentieren zu können, haben wir einen Präsentationsaufbau auf Basis einer OSB-3-Verlegeplatte gebaut (vgl. Abb. \ref{fig:praesentationsaufbau}: \nameref{fig:praesentationsaufbau}).
Dieser ist neben der Smart Home Zentrale mit einem Router, zwei Zigbee-fähigen Glühbirnen, einer Phillips Hue Zigbee Steckdose und einem Amazon Fire8 HD Tablet ausgestattet.
Der Aufbau soll die Funktion der Smart Home Zentrale in der Steuerung von Smart Home Komponenten praktisch aufzeigen und wurde von uns selbst gebaut.

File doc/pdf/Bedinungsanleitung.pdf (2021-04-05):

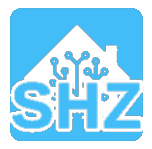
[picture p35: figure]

# BEDIENUNGS- & INSTALLATIONSANLEITUNG

### 5. April 2021

DE

## Inhaltsverzeichnis

1 Aufbau der Smart Home Zentrale | 2
2 Installation per Skript | 4
3 Einrichtungsanleitung Home Assistant, MQTT und Zigbee2MQTT | 5
4 Einbinden von Endgeräten | 17
BEDIENUNGSANLEITUNG | 1

## 1 Aufbau der Smart Home Zentrale

Für die Einrichtung der Smart Home Zentrale werden folgende Dinge benötigt:

- beiliegendes Netzteil
- beiliegendes Ethernet-Kabel
- beiliegende Schrauben und Dübel zur Wandmontage.

Schritt 1: Platzierung der Smart Home Zentrale
Geeigneten Montageplatz für die Smart Home Zentrale festlegen, am besten geeignet ist ein zentral gelegener Ort.

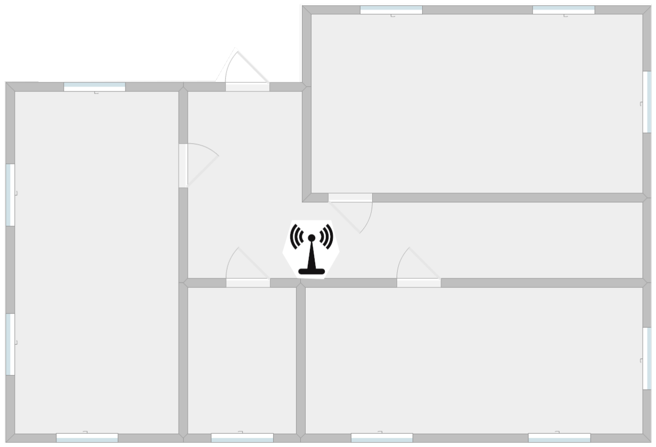
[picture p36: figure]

Abbildung 1: Platzierung der Smart Home Zentrale

Schritt 2: Montage der Smart Home Zentrale
Smart Home Zentrale mit den beiliegenden Schrauben an der Wand Befestigen (falls auf eine Wandmontage verzichtet wird kann dieser Schritt übersprungen werden).

Schritt 3: Netzwerkverbindung herstellen
Gerät mit Hilfe des Ethernet-Kabels mit einem Router verbinden.

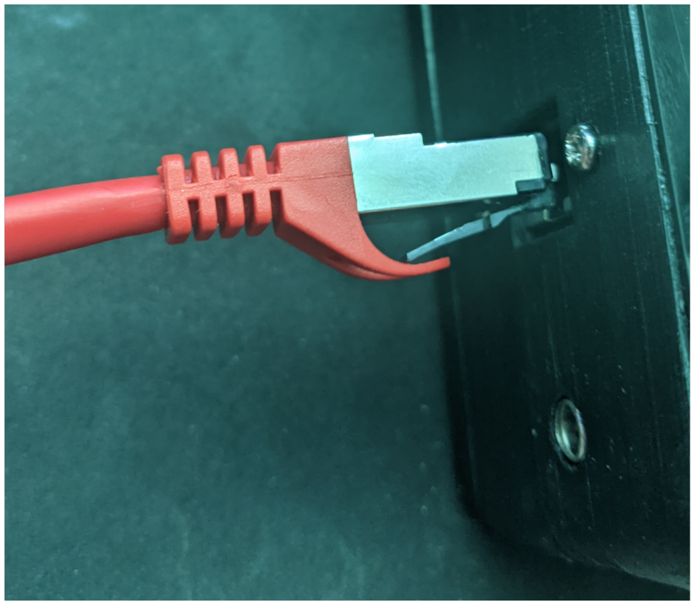
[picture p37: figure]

Abbildung 2: Ethernet-Kabel anschließen

Schritt 4: Spannungsversorgung herstellen
Netzteil mit der Smart Home Zentrale verbinden, die Smart-Home-Zentrale Starten daraufhin direkt.

Bitte folgen Sie nun der Einrichtungsanleitung ab Punkt 3.1

## 2 Installation per Skript

Folgende Anleitung ist für Nutzer gedacht, die mit eigener Hardware eine Smart Home Zentrale aufbauen wollen. Es werden hierfür Befehle aufgelistet, die alle als root-Nutzer (sudo <Befehl>) ausgeführt werden sollten.

WICHTIG: DAS SKRIPT IST NUR FÜR RASPBERRY PI V3 B UND V4 B GE-DACHT! SOLLTEN SIE EINE ANDERE HARDWAREPLATTFORM NUTZEN, VER-WENDEN SIE BITTE DAS OFFIZIELLE INSTALLATIONSSKRIPT DES HOME AS-SISTANT SUPERVISED¹

Schritt 1: Download des Installationsskripts
Um eine Installation durch das Installationsskript auszuführen muss zunächst das Skript von GitHub geladen werden:

curl -Lo shz_install https://github.com/Pharias/TAR/blob/main/shz_install

Schritt 2: Ausführen des Installationsskripts
Nun kann durch das Ausführen des Befehls

./sht_install -a

die Gesamtinstallation gestartet werden.
Nach erfolgreichen Installation kann mit der Einrichtung fortgefahren werden.

Optional: Zusätzliche Skriptparameter
Das Skript verfügt über die Möglichkeit, mit unterschiedlichen Parametern gestartet zu werden. Diese lauten:
- -a: aktualisiert das System, installiert alle Abhängigkeiten²
- -d: installiert NUR Docker
- -h: installiert NUR Home Assistant³
- -u: aktualisiert das System
- -?: zeigt eine kurze Hilfeseite an.
1 | https://github.com/home-assistant/supervised-installer
2 | Docker, Network Manager, AppArmor, JQ
3 | und gegebenenfalls die Abhängigkeiten, falls nicht vorhanden

## 3 Einrichtungsanleitung Home Assistant, MQTT und

## Zigbee2MQTT

### 3.1 Einrichten von Home Assistant

Schritt 1: Anmelden auf der Weboberfläche
Wurde die Smart Home Zentrale eingeschaltet, das Installationsskript ausgeführt oder das Image installiert, kann mit der Einrichtung der Software fortgefahren werden. Öffnen Sie in einem Webbrowser die Seite:
http://<IP.Der.Zentrale>:8123.
Nach kurzer Zeit sollten Sie den Anmeldebildschirm des Home Assistant sehen. Legen Sie einen Benutzer an und bestätigen Sie die Eingabe mit dem Button "Benutzerkonto anlegen".

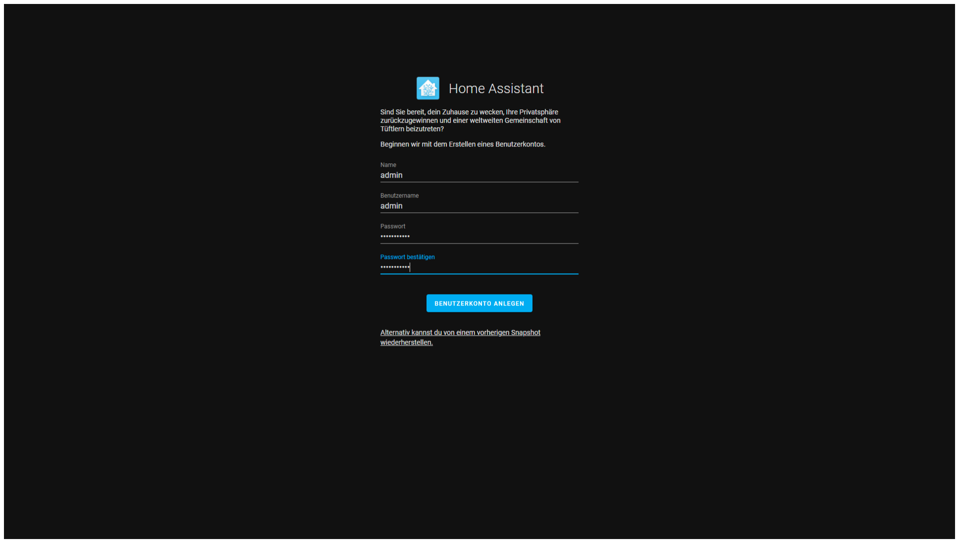
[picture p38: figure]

Abbildung 3: Anmeldebildschirm

Schritt 2: Standort festlegen
Im nächsten Bildschirm legen Sie Ihren Standort fest, um auf standortbasierte Dienste wie Geofencing und Wettervorhersagen zuzugreifen.

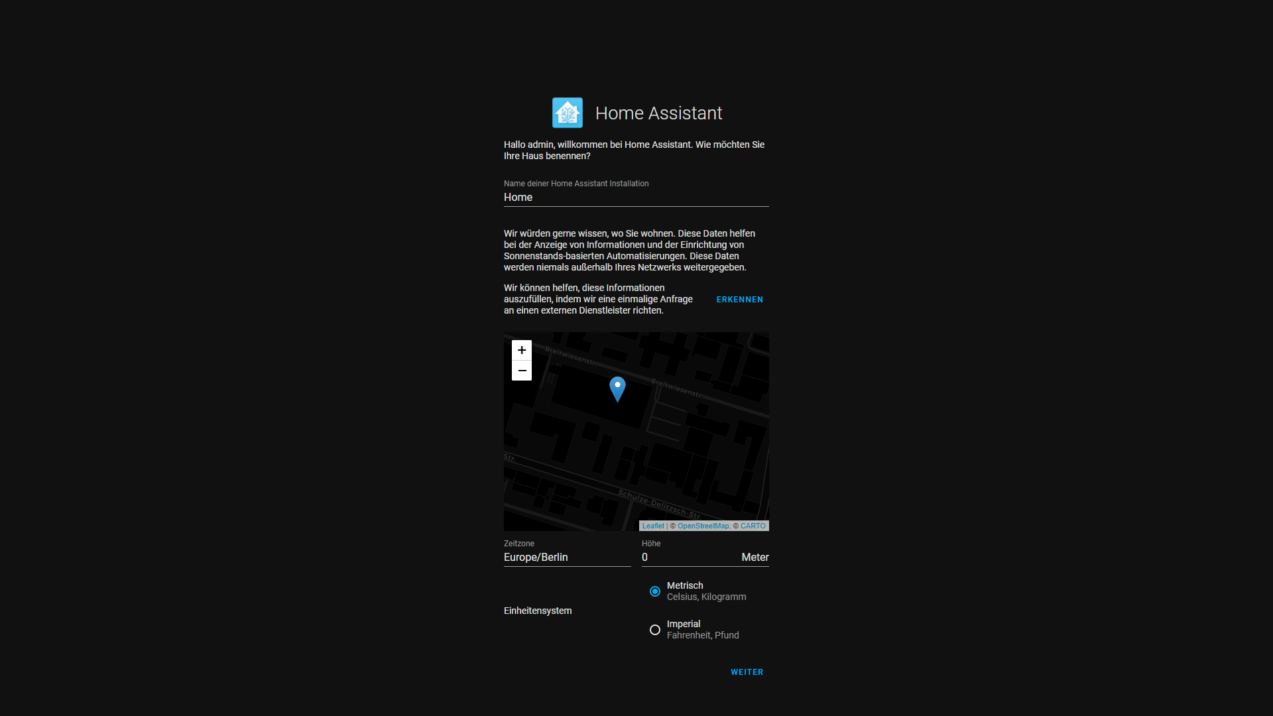
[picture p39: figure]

Abbildung 4: Festlegen von Name und Standort

Schritt 3: Erkennung von Smart Home Systemen im Netzwerk
Nun ermöglicht es Ihnen der Home Assistant, bereits installierte Smart-Home Systeme, wie zum Beispiel Phillips Hue, IKEA oder Google Cast, zu integrieren

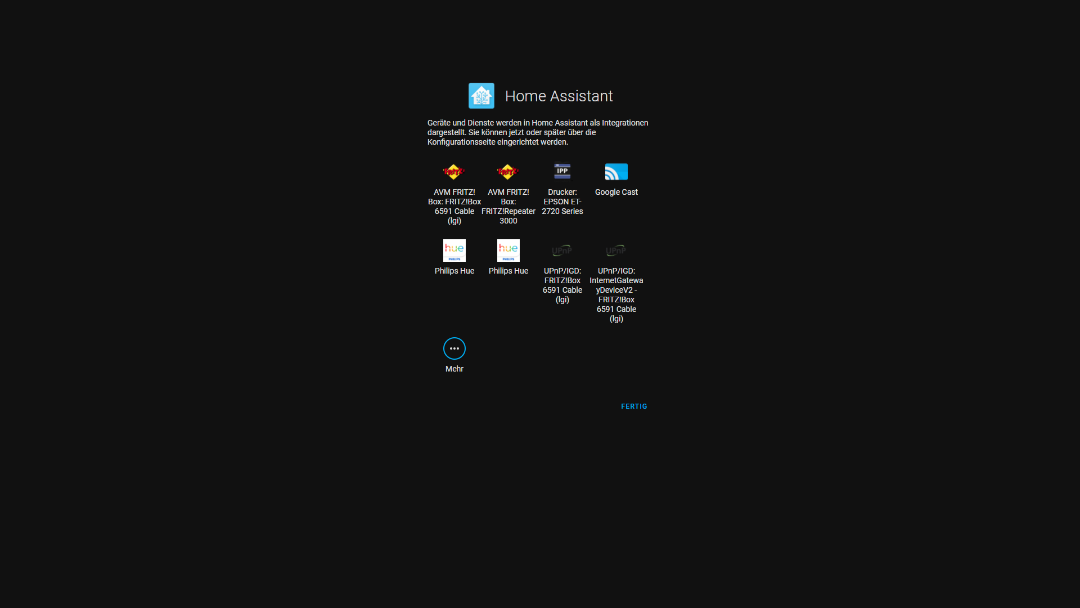
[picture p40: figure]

Abbildung 5: Mögliche Integrationen werden erkannt

Sollten Sie keine Integrationen ausgewählt haben, zeigt der nächster Bildschirm ein minimales Dashboard an.

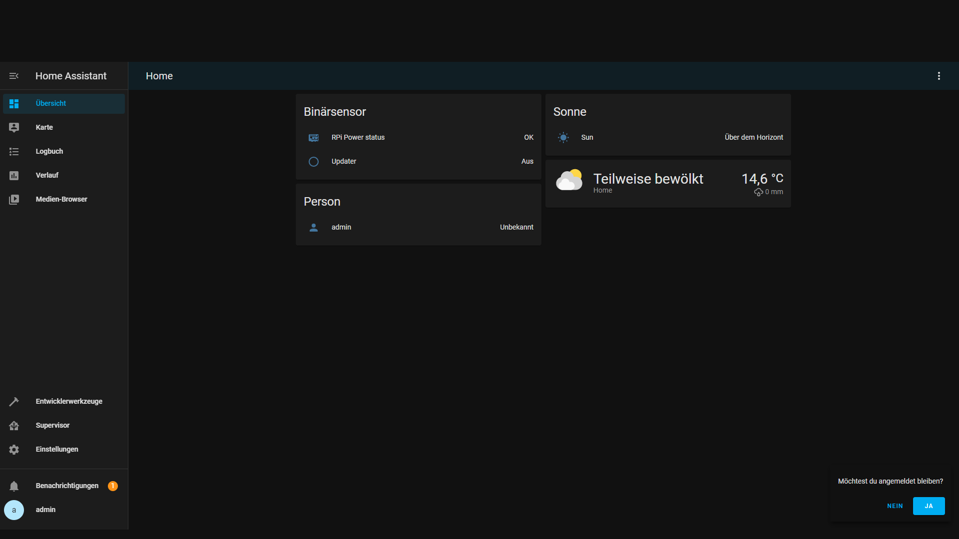
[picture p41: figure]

Abbildung 6: erstes Dashboard

### 3.2 Installation des MQTT Add-ons

Falls Sie das Installationsskript oder Image für bereits vorhandene Hardware nutzen und Sie keine Zigbee Geräte über Ihre Smart Home Zentrale steuern möchten, können Sie die weiteren Schritte überspringen, denn der Home Assistant Supervised steht Ihnen nun zur Verfügung.

Schritt 1: Installation Von MQTT
Um das MQTT Add-on zu installieren, navigieren Sie zunächst in das Supervisor Dashboard und wählen dort in der Kopfzeile den Add-on Shop aus.

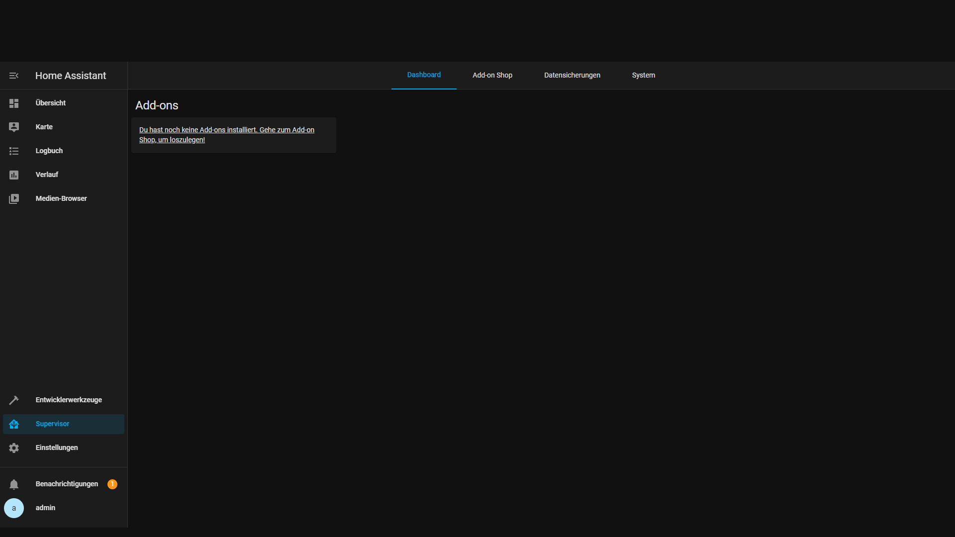
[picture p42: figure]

Abbildung 7: Supervisor Dashboard

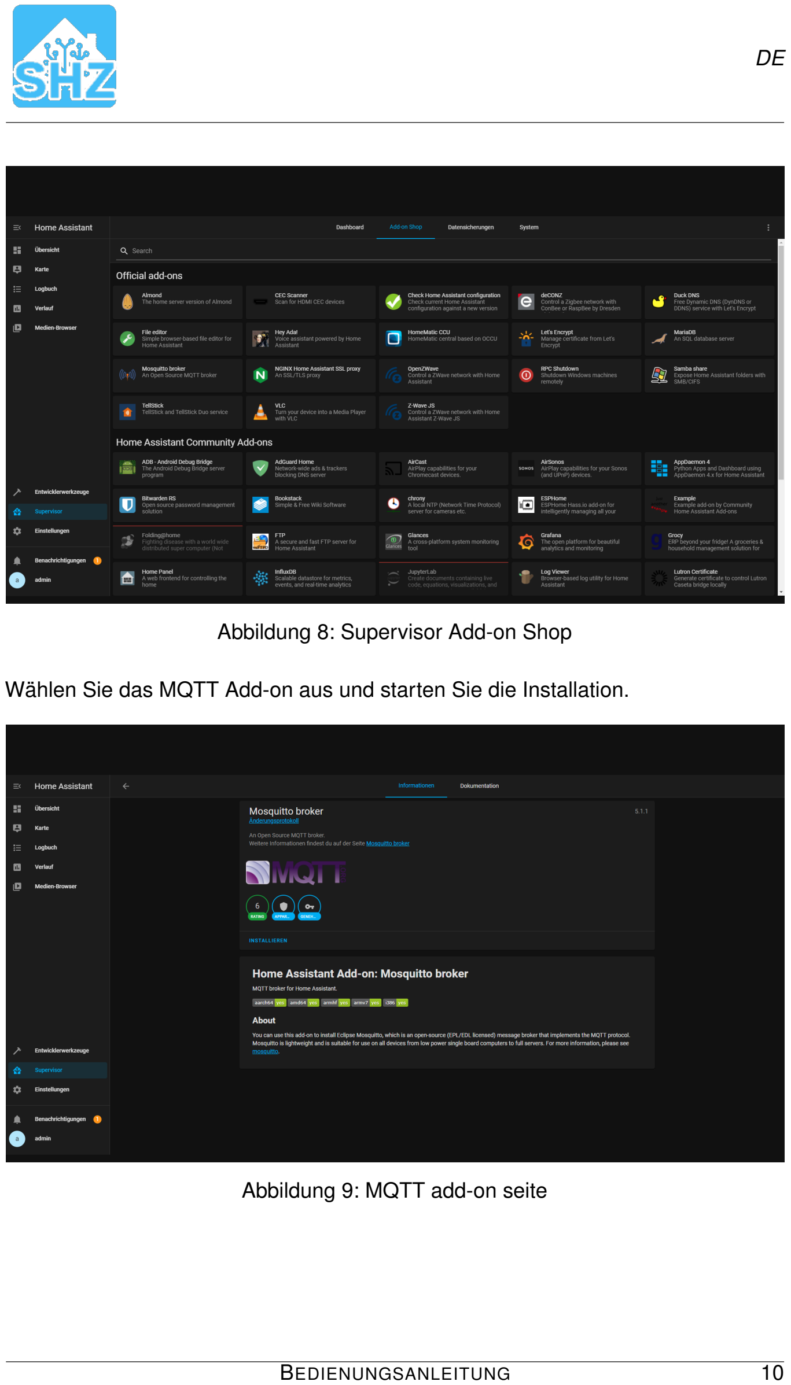
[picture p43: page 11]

Abbildung 8: Supervisor Add-on Shop

Wählen Sie das MQTT Add-on aus und starten Sie die Installation.

Abbildung 9: MQTT add-on seite

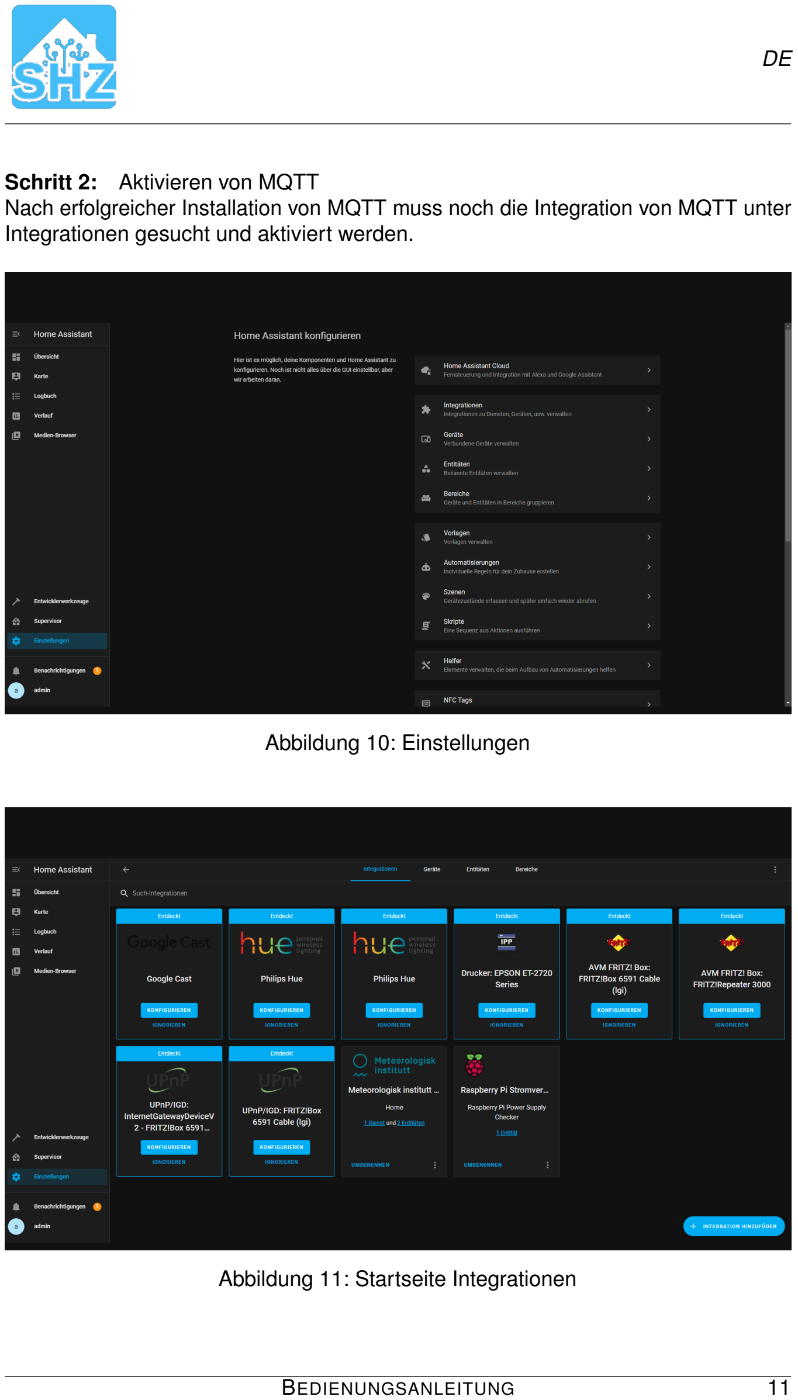
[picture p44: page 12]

Schritt 2: Aktivieren von MQTT
Nach erfolgreicher Installation von MQTT muss noch die Integration von MQTT unter Integrationen gesucht und aktiviert werden.

Abbildung 10: Einstellungen

Abbildung 11: Startseite Integrationen

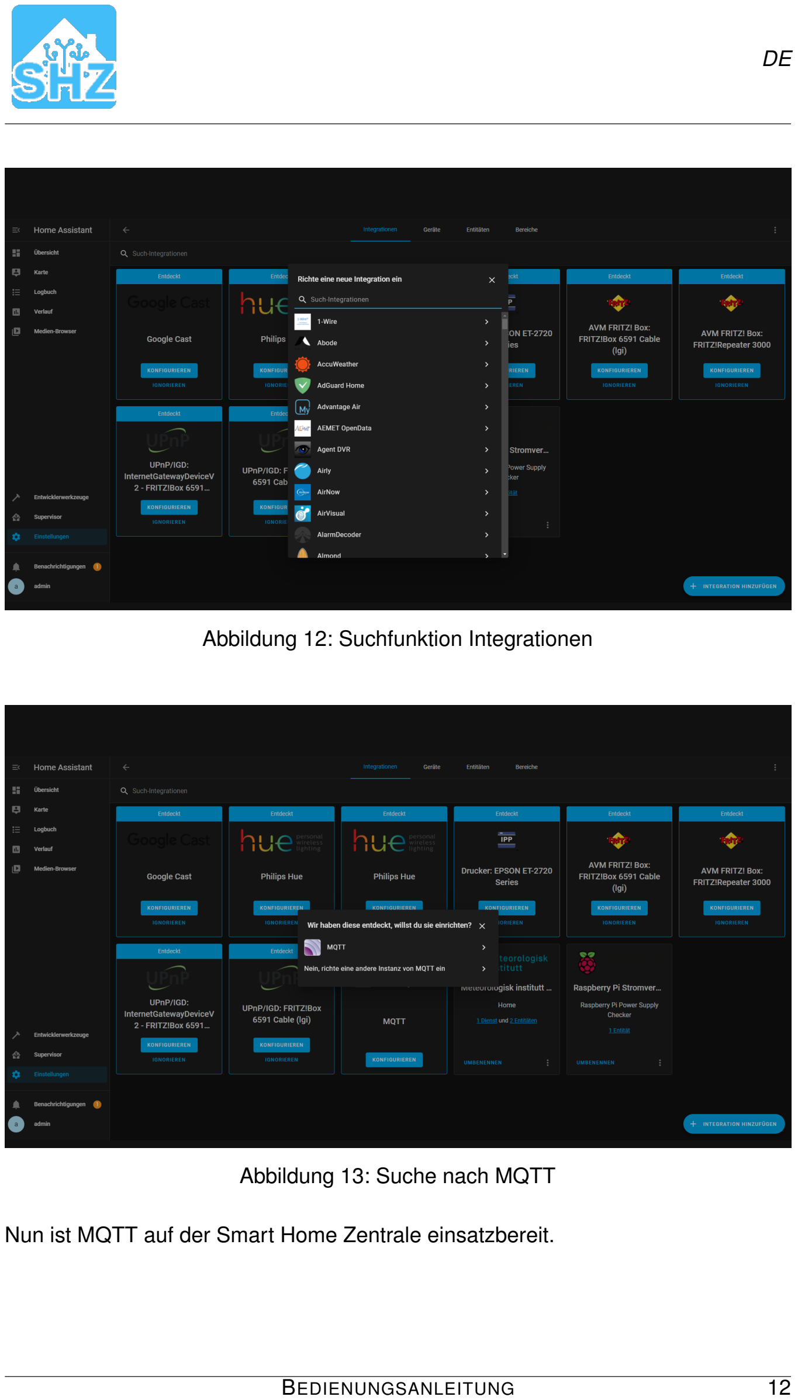
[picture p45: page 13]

Abbildung 12: Suchfunktion Integrationen

Abbildung 13: Suche nach MQTT

Nun ist MQTT auf der Smart Home Zentrale einsatzbereit.

### 3.3 Installation des Zigbee2MQTT Add-ons

Auch für die Installation des Zigbee2MQTT Add-ons nutzen wir den Supervisor Add-on Shop.

Schritt 1: Hinzufügen des Repositorys
Es ist notwendig, das Repository von Zigbee2MQTT hier als Quelle anzugeben. Hierzu klicken Sie auf die oben rechts zu sehenden drei Punkte und fügen folgendes Repository hinzu:
https://github.com/zigbee2mqtt/hassio-zigbee2mqtt

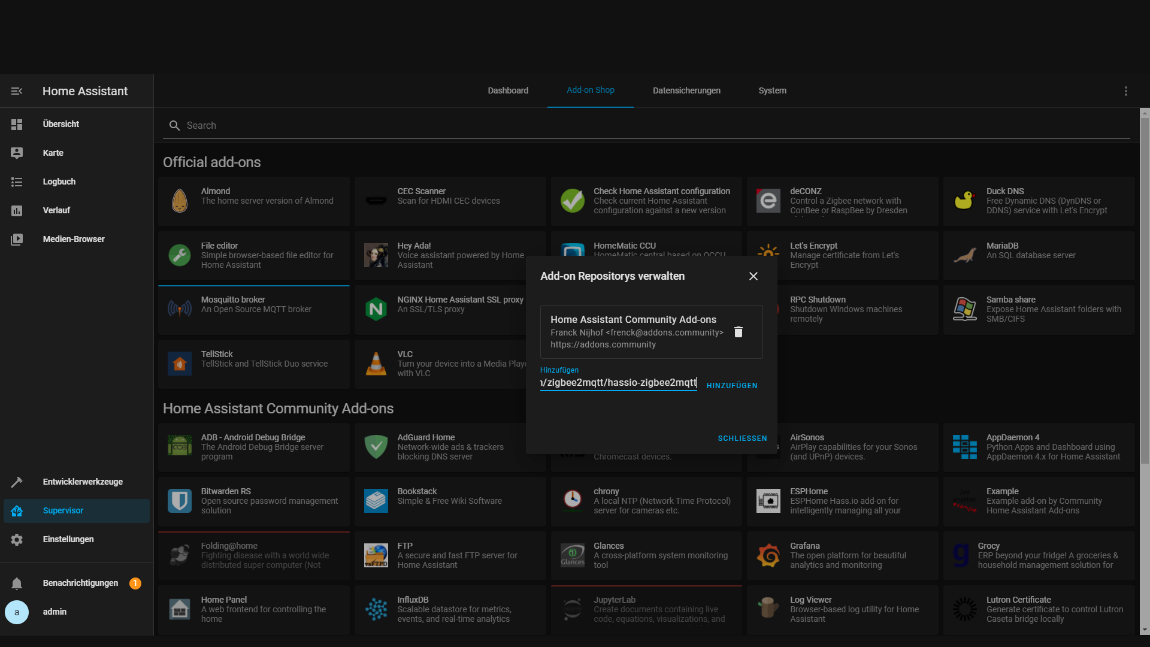
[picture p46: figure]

Abbildung 14: Repository in Add-on Shop einpflegen

Nun ist es möglich, das Zigbee2MQTT Add-on über den Add-on Store zu installieren.

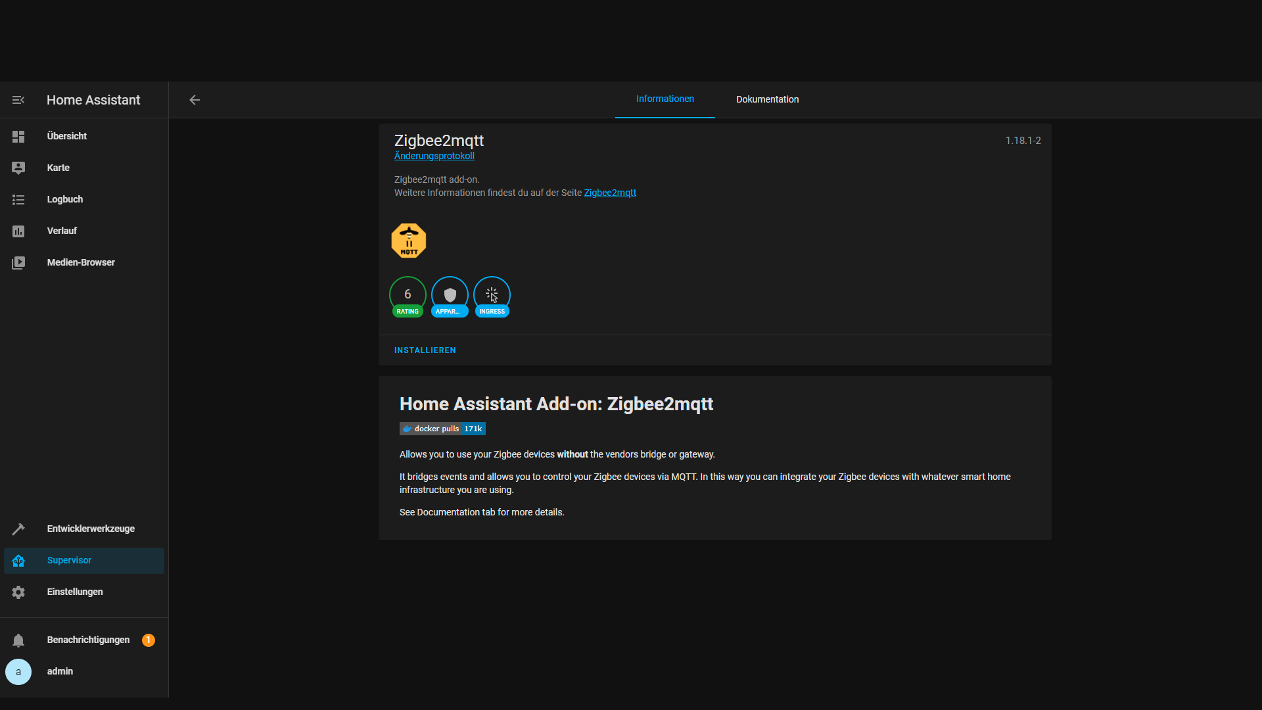
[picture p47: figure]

Abbildung 15: Zigbee2MQTT Add-on Seite

Schritt 2: Konfiguration des Add-ons
Um eine funktionierende Installation zu ermöglichen, muss die configuration.yaml im Add-on unter Konfiguration überprüft werden. Nur wenn hier unter serial der korrekte Pfad für den Zigbee USB Adapter angegeben und "permit_join": true gesetzt ist, können später neue Geräte eingelernt werden. Um den korrekten Pfad für den Zigbee USB Adapter zu überprüfen, navigieren Sie über Supervisor System zu Hardware.

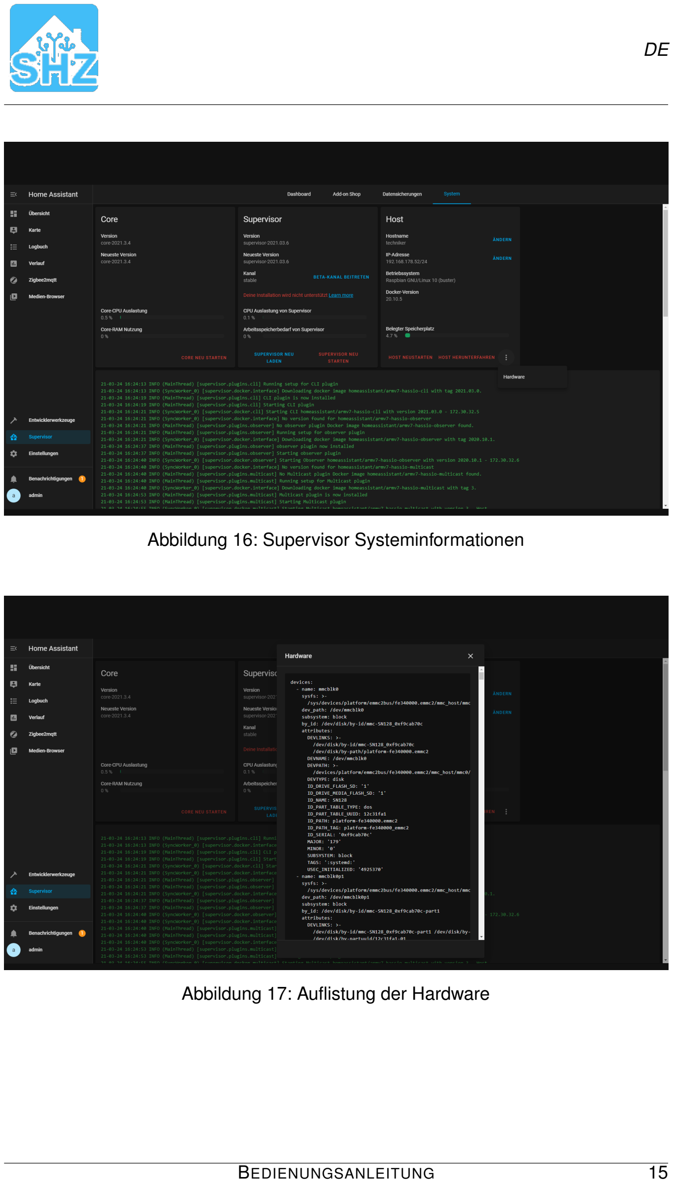
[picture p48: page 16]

Abbildung 16: Supervisor Systeminformationen

Abbildung 17: Auflistung der Hardware

Schritt 3: Aktivieren von Zigbee2MQTT
Sind alle oben aufgeführten Schritte ausgeführt worden, kann das Add-on gestartet werden.

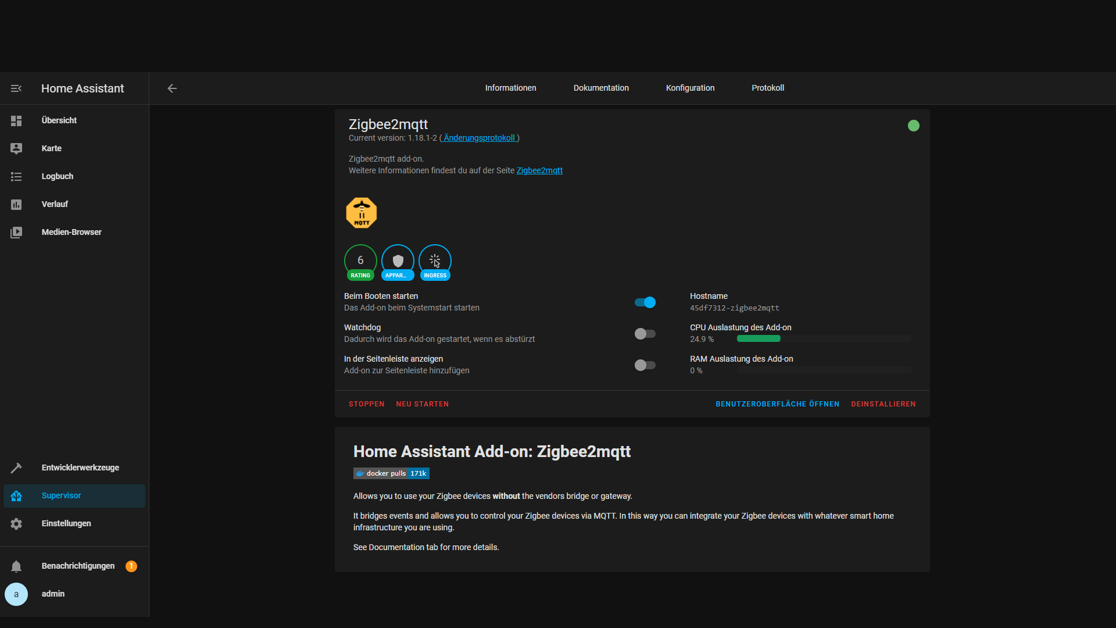
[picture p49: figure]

Abbildung 18: Aktiviertes Zigbee2MQTT Add-on

Damit ist Zigbee2MQTT auf der Smart Home Zentrale einsatzbereit

## 4 Einbinden von Endgeräten

Schritt 1: Zurücksetzen der Geräte
Setzen sie das einzulernende Gerät nach Herstellerangaben zurück.

Schritt 2: Einlernen aktivieren
Vergewissern Sie sich das in der
configuration.yaml "permit_join": true
gesetzt ist.
Alternativ kann auch die Benutzeroblerfläche des Zigbee2MQTT Add-ons genutzt werden um in der configuration.yaml "permit_join": true zu setzen.

Schritt 3: Einlernen von Geräten
Eingelernete Geräte werden automatisch der MQTT Inegration zugeordnet.

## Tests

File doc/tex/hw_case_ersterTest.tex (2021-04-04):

\subsubsection{Erster Test zur Fertigung des Gehäuses}\label{hw_case_ersterTest}
Zur Erstellung des Gehäuses haben wir die Maße des Bildschirms als Anhaltspunkt genommen. 
Die erste Messung haben wir mit einem Meterstab durchgeführt.
Der Bildschirm hatte an der Hinterseite eine Erhebung, weshalb wir diese ebenfalls ausgemessen haben. 
Die Maße beliefen sich nach der ersten Messung auf:
\begin{itemize}
	\item 255,5 mm Breite
	\item 167 mm Höhe
	\item Kantenradius 10 mm
\end{itemize}
\begin{figure}[H]
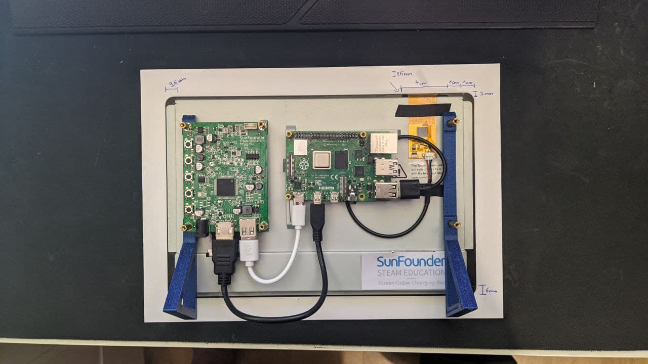
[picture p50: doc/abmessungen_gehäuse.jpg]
	
	\caption[Abmessungen Bildschirm Rückseite]{Abmessungen Bildschirm Rückseite}
	\label{fig:screen-back-01}
\end{figure}
\noindent Anhand dieser Maße haben wir dann in Fusion 360 eine Grundplanzeichnung und ein 3D-Modell erstellt.\par	
\noindent Nach Überprüfung der Maße haben wir dann allerdings festgestellt, dass der zur Verfügung stehende 3D-Drucker, der Ender 3 Pro der Firma Creality3D, ein maximales Druckvolumen von 235 x 235 x 220 mm besitzt und somit das Gehäuse nicht wie ursprünglich geplant aus einem Stück, sondern in mehreren Teilen gedruckt werden muss. \\
\noindent Die ursprüngliche Konstruktion musste geändert werden. 
Das Gehäuse besteht nun aus vier Teilen, zwei davon bilden jeweils die Seitenwände, während zwei weitere den Deckel des Gehäuses bilden. 
Die Teile werden mit langen M3 Senkkopfschrauben verbunden, die zusätzlich als Verschluss des Gehäuses dienen.\par
\begin{figure}[H]
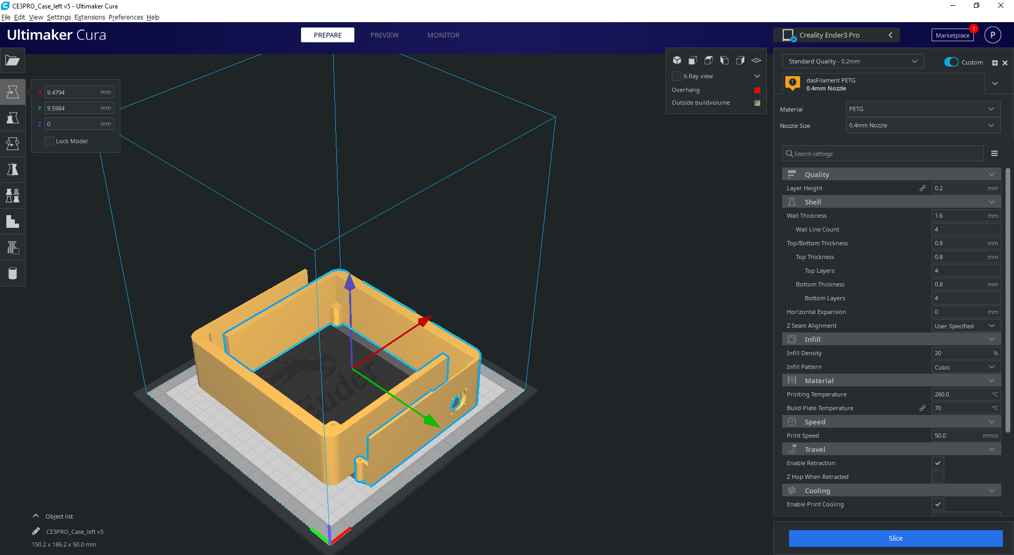
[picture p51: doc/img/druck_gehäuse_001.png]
	
	\caption[Platzierung der beiden Gehäusewände in CURA]{Platzierung der beiden Gehäusewände in CURA}
	\label{fig:print-case-test_01}
\end{figure}
\begin{figure}[H]
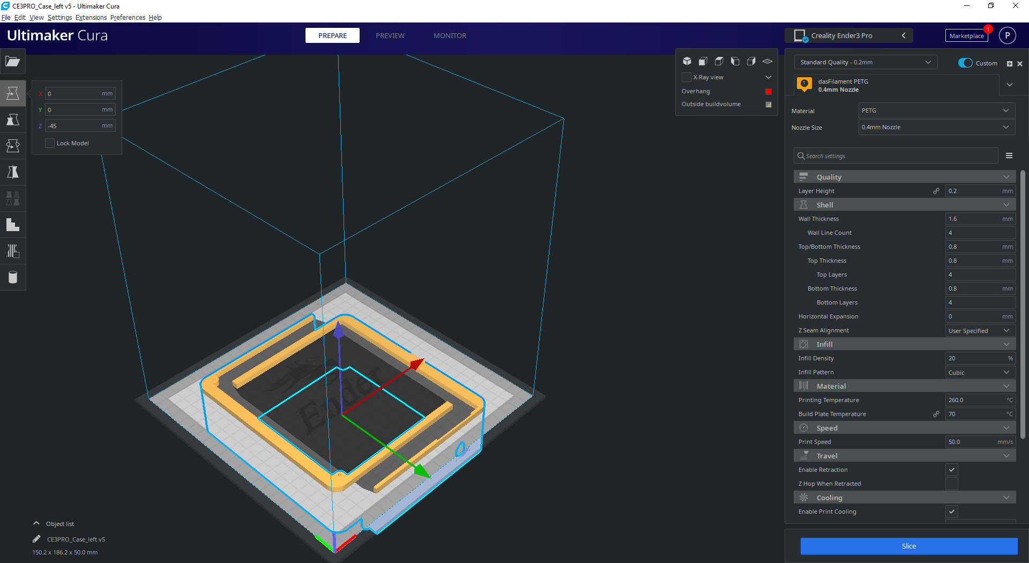
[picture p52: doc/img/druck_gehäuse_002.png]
	
	\caption[Verschiebung der Modelle entlang der Z-Achse um 45mm]{Verschiebung der Modelle entlang der Z-Achse um 45 mm}
	\label{fig:print-case-test_02}
\end{figure}
\begin{figure}[H]
	
	\caption[Slicen der Modelle]{Slicen der Modelle}
	\label{fig:print-case-test_03}
\end{figure}
\begin{figure}[H]
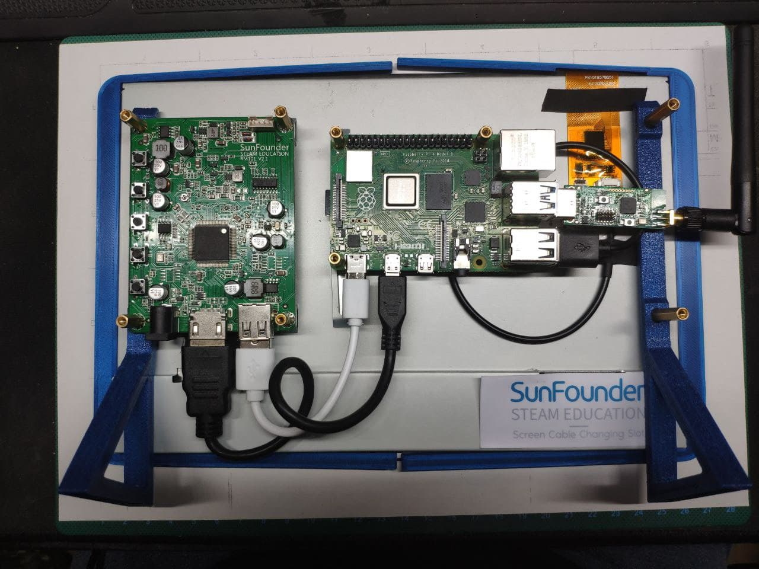
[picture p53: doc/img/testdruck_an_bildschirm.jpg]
	
	\caption[Anlegen des Testdrucks]{Anlegen des Testdrucks}
	\label{fig:print-case-test_04}
\end{figure}
\noindent Um die Genauigkeit der Konstruktion zu testen, haben wir eine 5 Millimeter hohe Schablone ausgedruckt, die am Bildschirm ausprobiert wurde. 
Der Ausdruck entstand mit Hilfe des Slicers CURA (vgl. Abb. \ref{fig:print-case-test_01}: \nameref{fig:print-case-test_01}), in dem die Modelle der beiden Seitenteile so angeordnet wurden, dass lediglich 5 Millimeter des Teils im druckbaren Bereich des Druckers verblieben (vgl. Abb. \ref{fig:print-case-test_02}: \nameref{fig:print-case-test_02}). 
Anschließend haben wir die Teile noch auf dem Druckbett zentriert (vgl. Abb. \ref{fig:print-case-test_03}: \nameref{fig:print-case-test_03}).\\
\noindent Nach dem Ausdrucken war klar, dass die Maße des ersten Versuchs nicht genau genug waren (vgl. Abb. \ref{fig:print-case-test_04}: \nameref{fig:print-case-test_04}, weshalb wir zum Ausmessen einen digitaler Messschieber mit einer Nachkommastelle und einer  Genauigkeit von $\pm$ 0.2 mm verwendeten.

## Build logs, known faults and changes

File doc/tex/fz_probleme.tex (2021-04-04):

\subsection{Fehler \& Probleme}\label{fz_fehler}
Probleme auf die wir während dem Projekt gestoßen sind, Fehler die wir begangen haben und Anekdoten.
\begin{itemize}
    \item \LaTeX   ist toll
    \item Ein Leerzeichen kann über einige Stunden Arbeit entscheiden
    \item Bei einem Test einer Version des Installationsskripts haben wir stundenlang nach einer Lösung gesucht, warum die Installation des Home Assistant fehlschlug, bis wir feststellten, dass unser Testsystem lediglich über WLAN mit unserem Netzwerk vergebunden war. 
    Der Network-Manager aber während der Installation neu gestartet wurde, wodurch die WLAN Verbindung neu startete und unsere SSH Verbindung zum PI abbrach. Darüber hinaus war das Installationsskript nicht mit der langen Wiederverbindungszeit im WLAN klargekommen.
    \item Stützstrukturen können auch mal Spaghetti produzieren
    \item Da wir uns auch als Ziel gesetzt haben, auf einem Raspberry Pi sowohl Desktop Umgebung als auch Home Assistant zu installieren, disqualifizierte sich von Anfang an das Home Assistant OS Image. Es gab für uns also keine andere Möglichkeit, als Home Assistant auf unserem Raspberry Pi nachzuinstallieren. 
    Nach einigen Fehlschlägen in der Einrichtung von Home Assistant Core, Mosquitto broker und Zigbee2MQTT entschieden wir uns zunächst für eine Installation der Komponenten in Docker Containern. 
    Als wir aber auch hier auf nicht durchgehend reproduzierbare Erfolge stießen und zeitgleich auch eine Integration des Home Assistant Supervisor anstrebten, fiel unsere finale Wahl auf die Installation des Home Assistant Supervised Docker Container, der von Home Assistant für Fortgeschrittene Nutzer über GitHub angeboten wird. 
    Dies ermöglichte uns die Nutzung der offizellen MQTT und Zigbee2MQTT Add-ons. 
    Um dennoch unser Ziel einer vereinfachten Installation erfüllen zu können, schrieben wir ein Installationsskript, welches benötigte Programme und Konfigurationen automatisch installiert.
    Außerdem erstellten wir zwei fertige Images, die ein Neuaufsetzen des Betriebssystems mit vorinstallierten Home Assistant Supervised Containers deutlich beschleunigen.  
\end{itemize}

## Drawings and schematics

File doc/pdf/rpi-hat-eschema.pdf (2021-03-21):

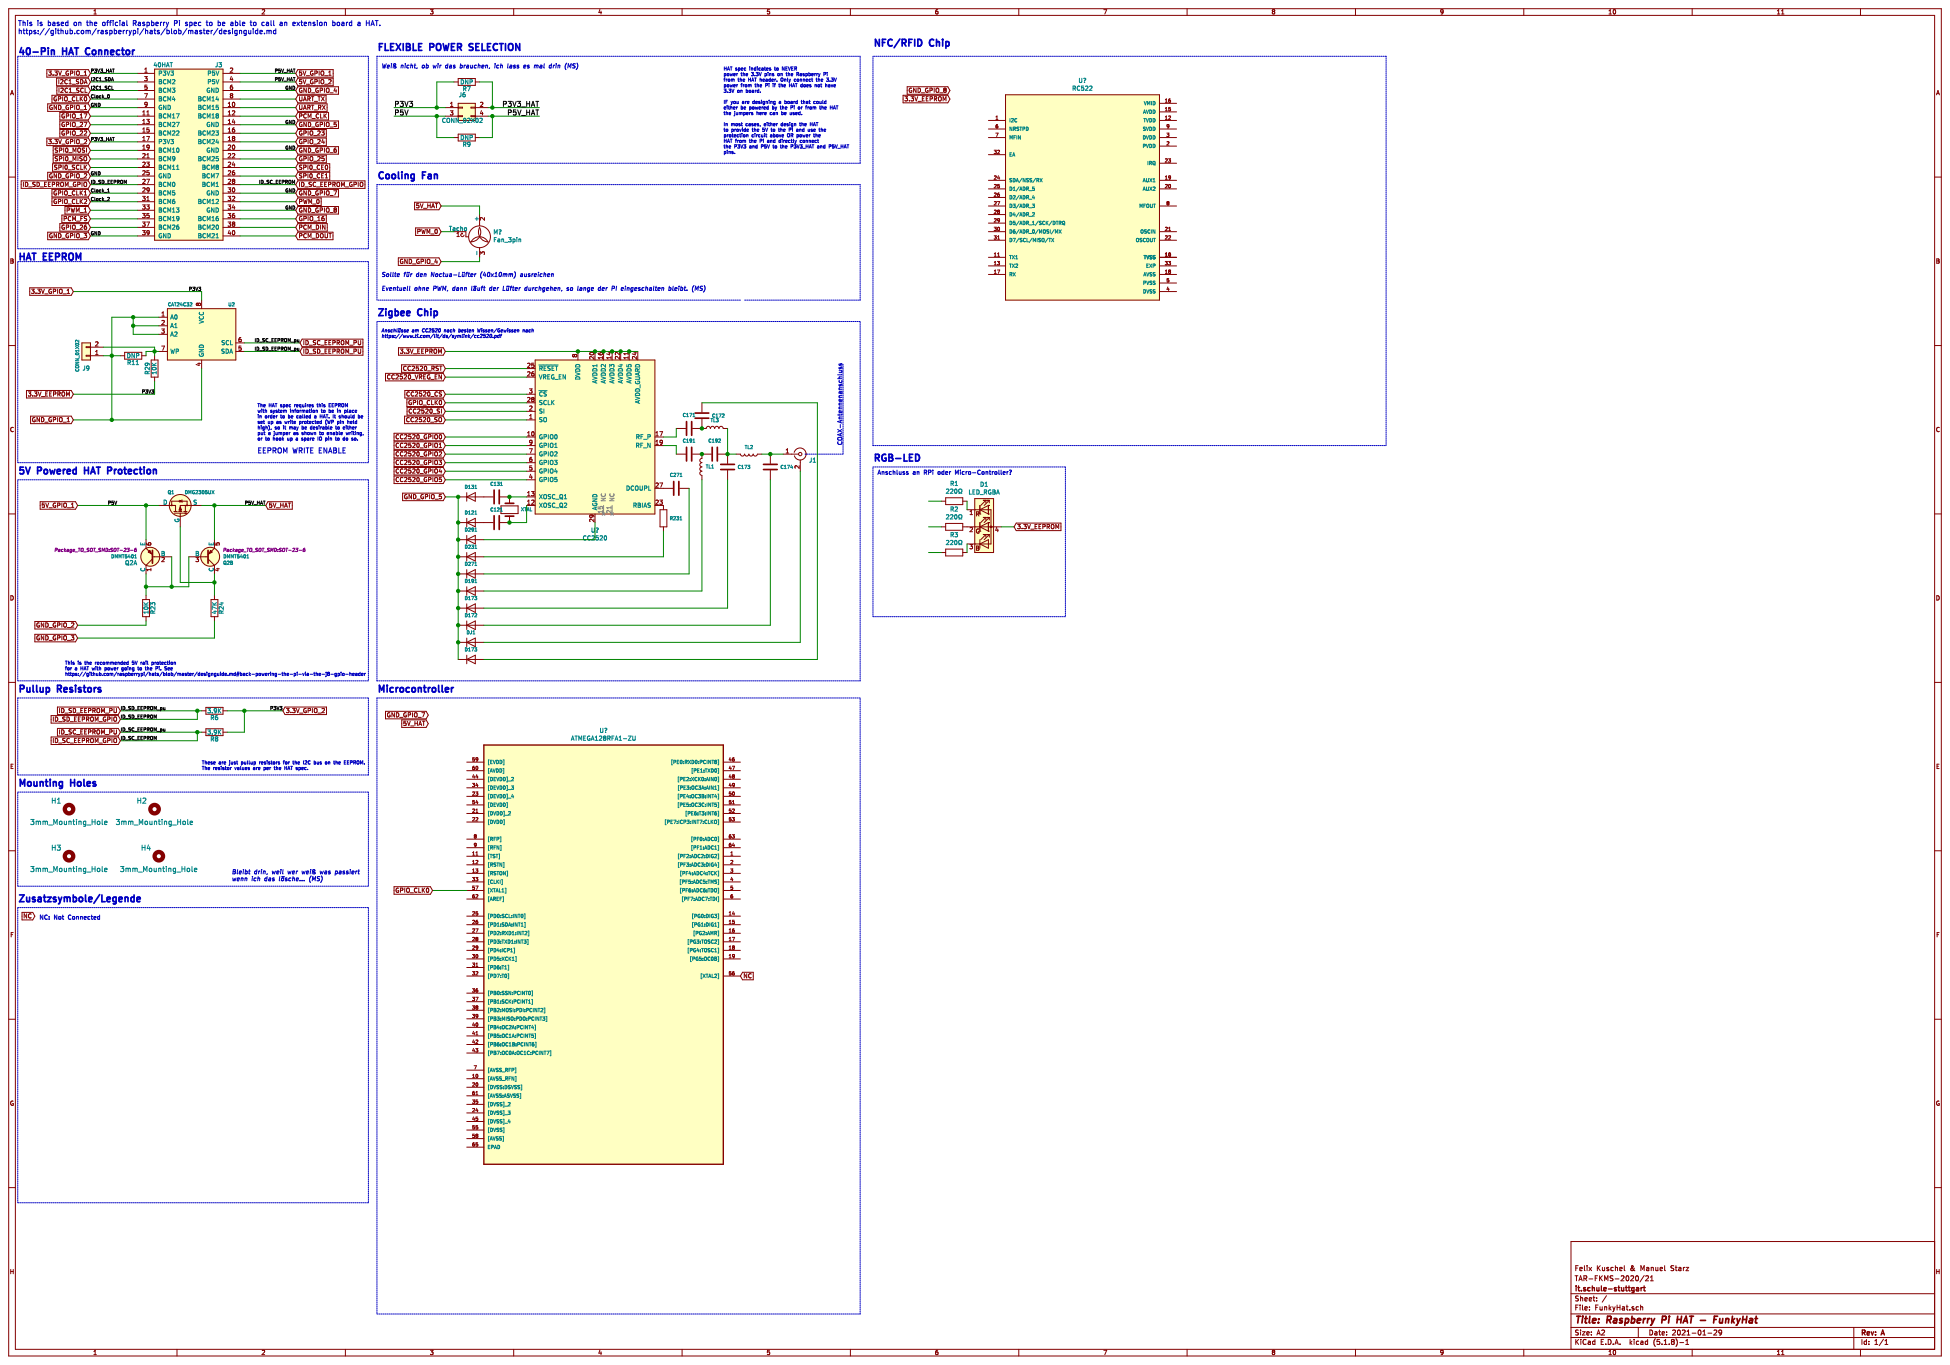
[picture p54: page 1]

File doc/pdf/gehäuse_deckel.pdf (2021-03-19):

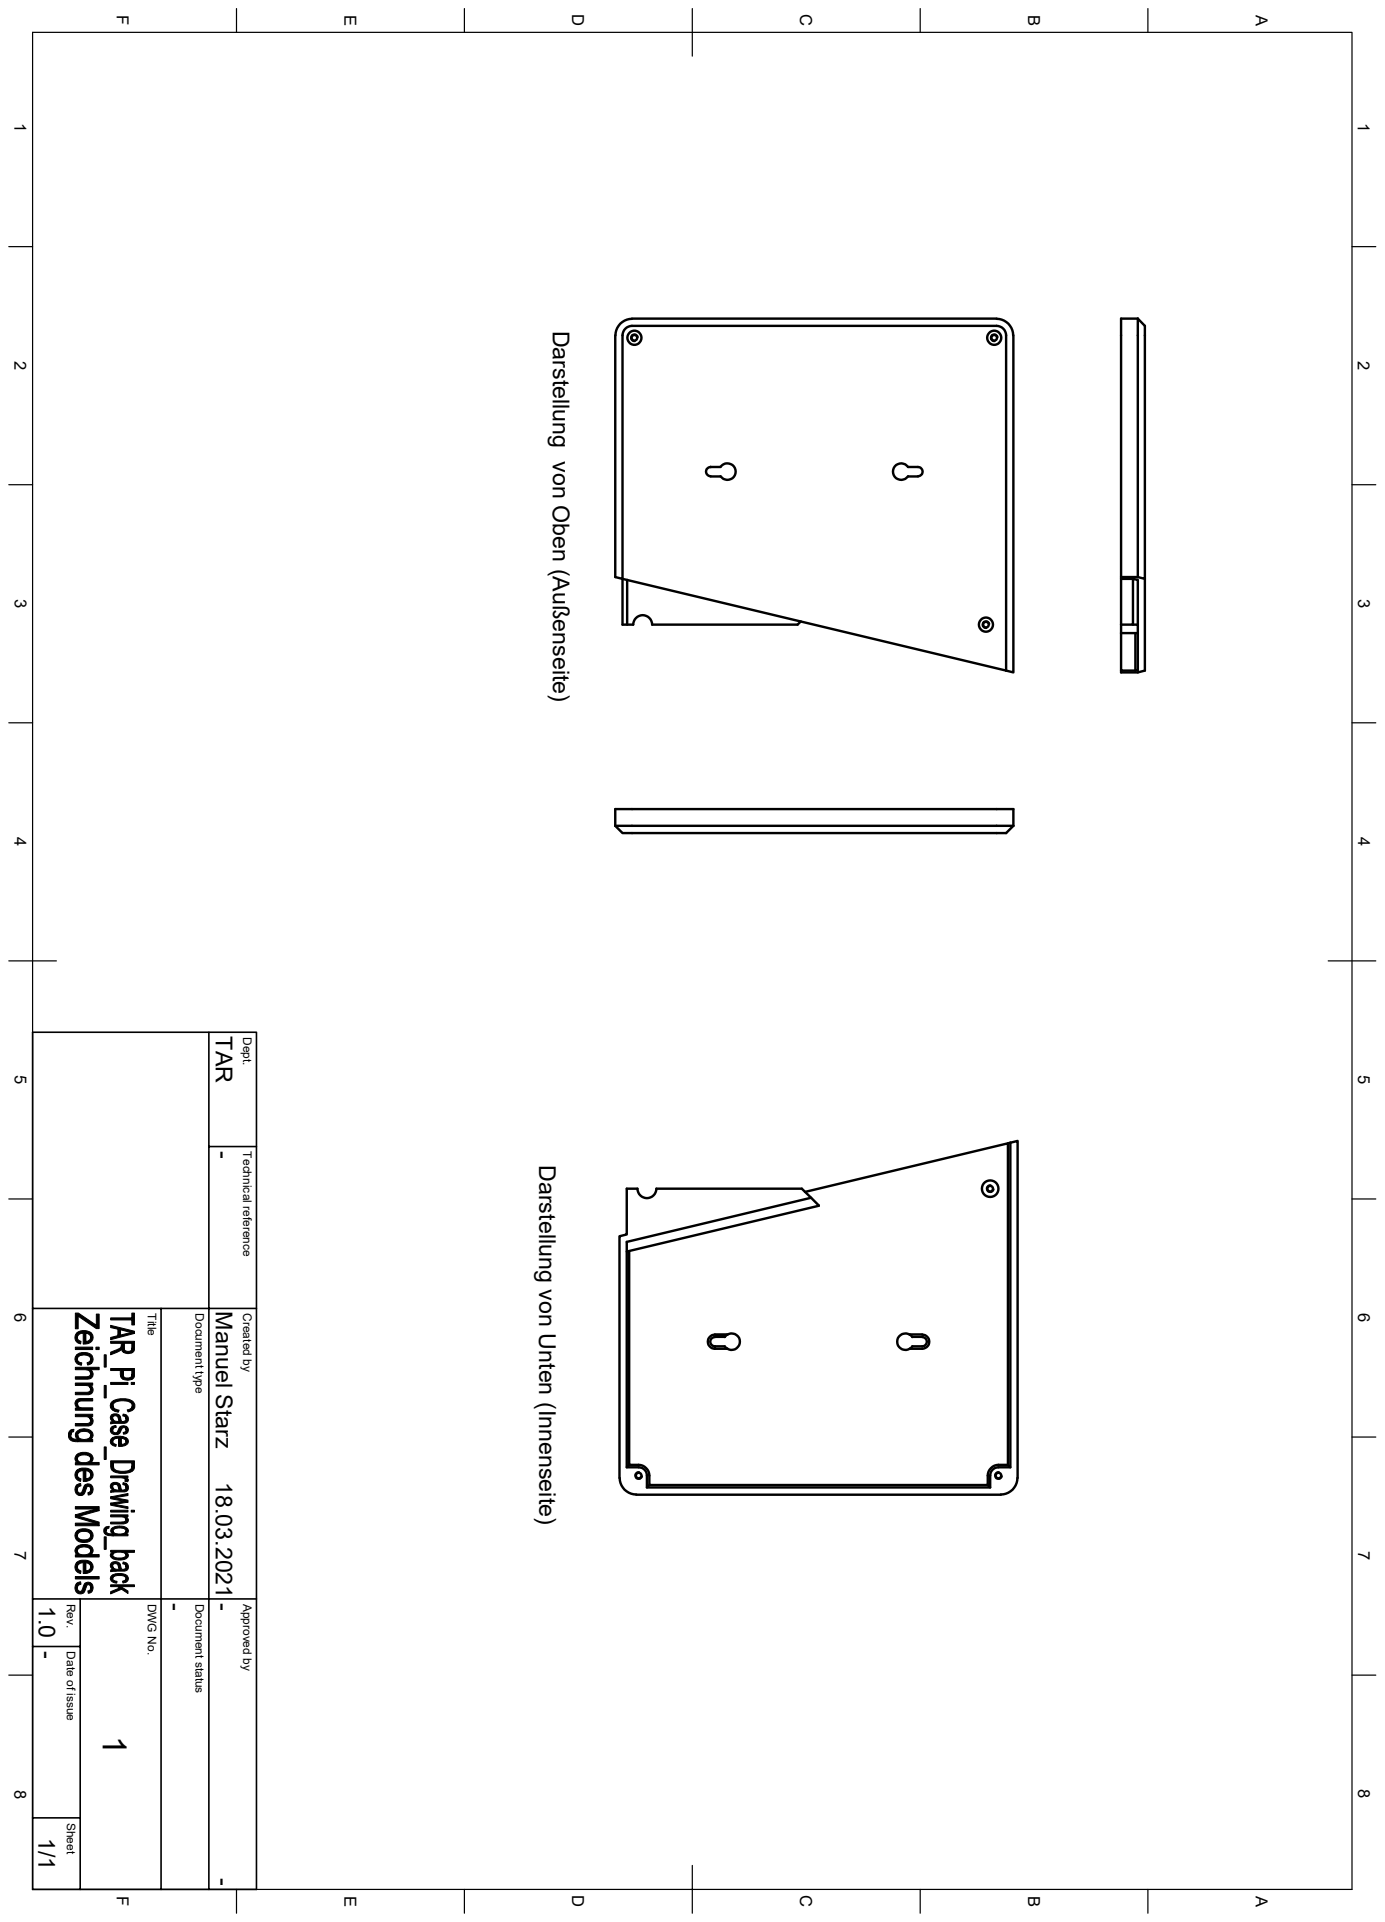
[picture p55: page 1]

1 A 2 3 4 5 6 7 8 1 2 3 4 5 6 7 8 FEDCB FEDCBA Dept. Technical reference Created by Approved by Title DWG No. Document type Document status Rev. Date of issue Sheet - 1.0 - - 18.03.2021 1/1 1 - Manuel Starz - TAR Darstellung von Oben (Außenseite) Darstellung von Unten (Innenseite)

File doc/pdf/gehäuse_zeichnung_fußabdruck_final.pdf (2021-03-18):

167

3.4

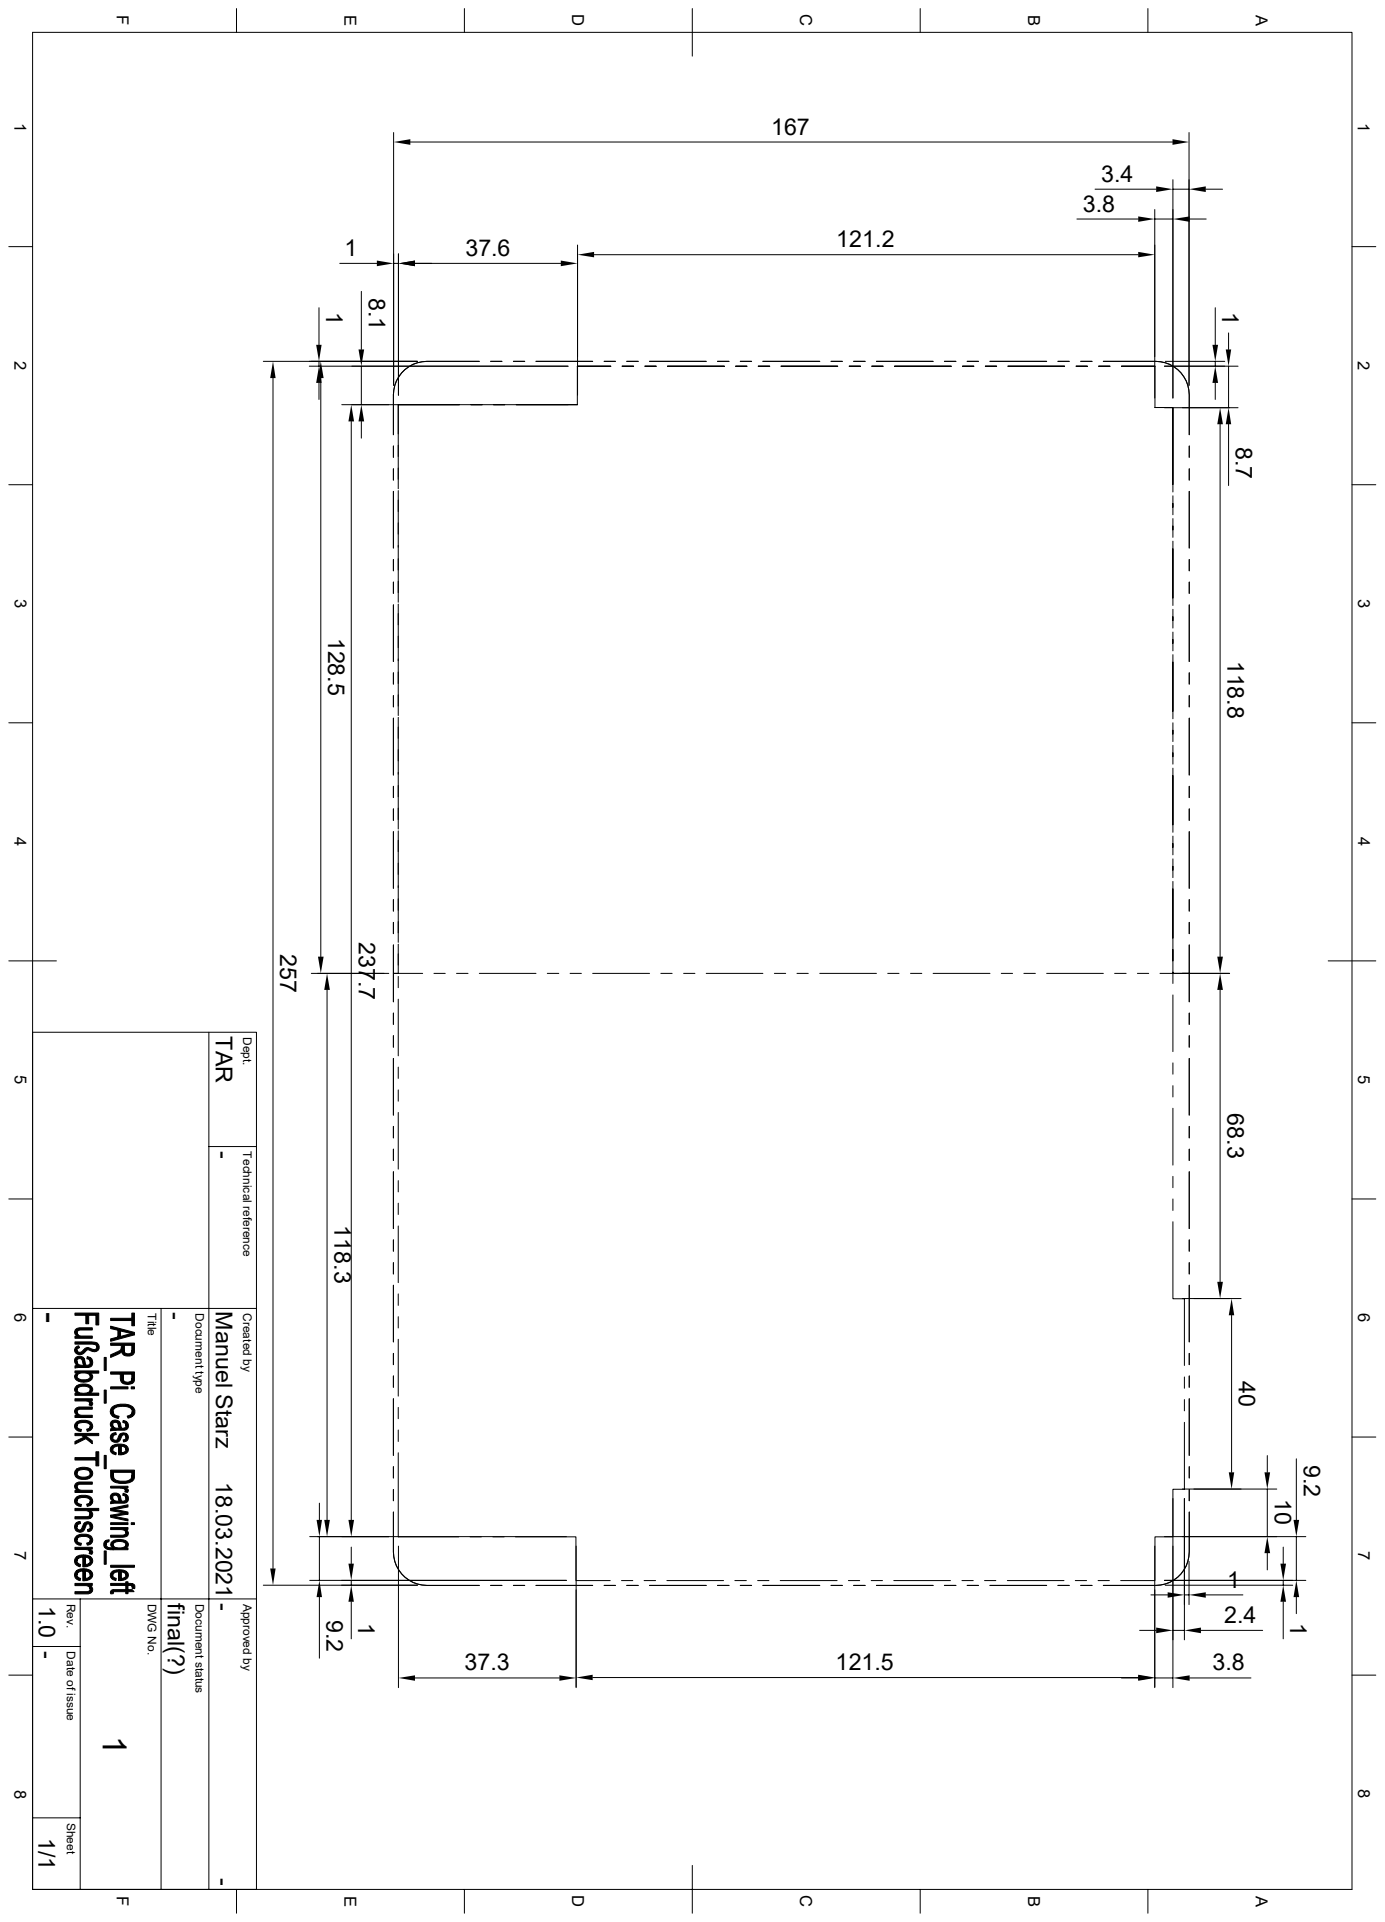
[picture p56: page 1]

1 A 2 3 4 5 6 7 8 1 2 3 4 5 6 7 8 FEDCB FEDCBA Dept. Technical reference Created by Approved by Title DWG No. Document type Document status Rev. Date of issue Sheet - 1.0 - final(?) - - 18.03.2021 1/1 1 - Manuel Starz - TAR 8.11 9.21 237.7 257

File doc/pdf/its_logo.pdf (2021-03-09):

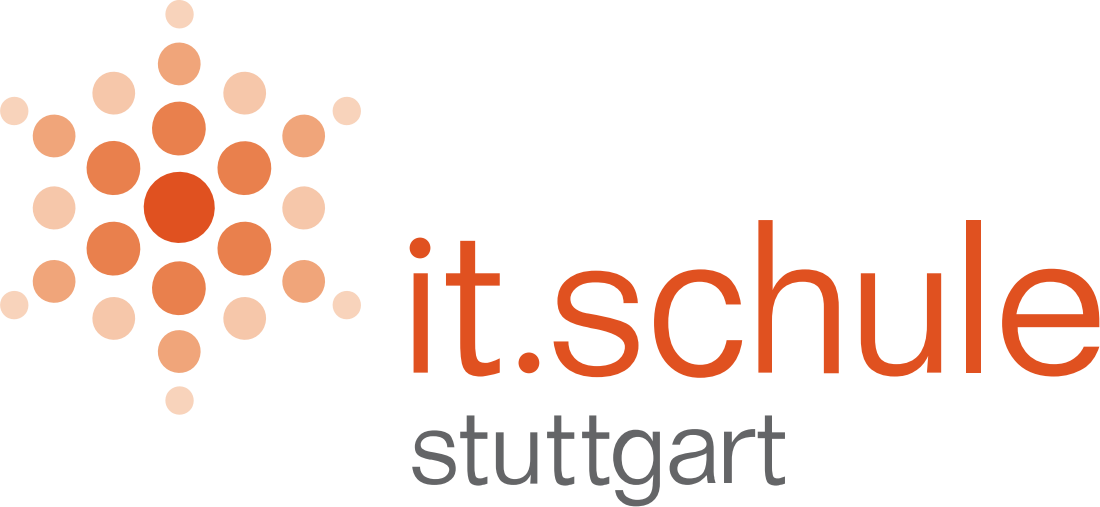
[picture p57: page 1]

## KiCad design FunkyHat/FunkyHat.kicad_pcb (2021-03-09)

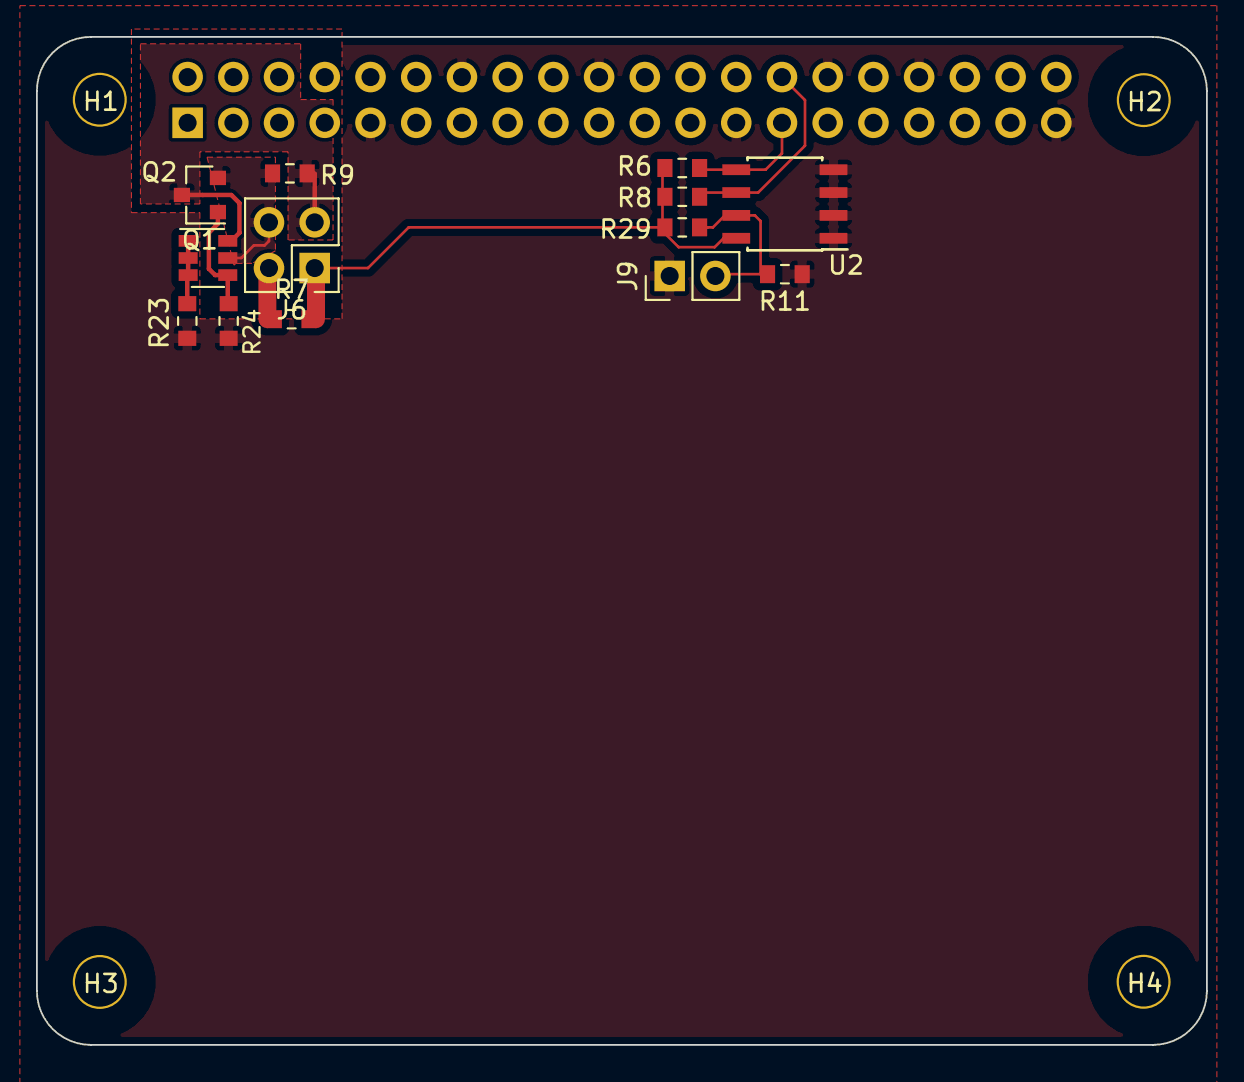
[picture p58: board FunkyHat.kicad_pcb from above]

Board: 4 copper layers, 65.0 x 56.0 mm, 18 parts (1 on the bottom side), 10 nets.

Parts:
H1, H2, H3, H4: 3mm_Mounting_Hole; NPTH_3mm_ID
J3: 40HAT; PinSocket_2x20_P2.54mm_Vertical
J6: CONN_02X02; PinHeader_2x02_P2.54mm_Vertical
J9: CONN_01X02; PinHeader_1x02_P2.54mm_Vertical
Q1: DMG2305UX; SOT-23
Q2: DMMT5401; SOT-23-6
R6, R8: 3.9K; R_0603_1608Metric_Pad0.84x1.00mm_HandSolder
R7, R9, R11: DNP; R_0603_1608Metric_Pad0.84x1.00mm_HandSolder
R23, R29: 10K; R_0603_1608Metric_Pad0.84x1.00mm_HandSolder
R24: 47K; R_0603_1608Metric_Pad0.84x1.00mm_HandSolder
U2: CAT24C32; SOIC-8_3.9x4.9mm_P1.27mm

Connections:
/ID_SC_EEPROM: J3.28, R8.2, U2.6
/ID_SD_EEPROM: J3.27, R6.2, U2.5
/P3V3: J6.1, R6.1, R7.2, R8.1, R29.1, U2.8
/P3V3_HAT: J3.1, J6.2, R7.1
/P5V: J6.3, Q1.3, Q2.6, R9.2
/P5V_HAT: J3.2, J3.4, J6.4, Q1.2, Q2.5, R9.1
GND: J3.6, J3.9, J3.14, J3.20, J3.25, J3.30, J3.34, J3.39, J9.1, R11.2, R23.2, R24.2, U2.1, U2.2, U2.3, U2.4
unnamed: J9.2, R11.1, R29.2, U2.7
unnamed: Q1.1, Q2.4, R24.1
unnamed: Q2.1, Q2.2, Q2.3, R23.1

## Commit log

2021-03-09 Initial Upload
    Hochladen der lokalen Dateien
    [FunkyHat.kicad_pcb, FunkyHat.sch]
2021-03-09 Doku erweitert
    Anpassung der Tabelle Software
    Hinzufügen der Tabelle Hardware
2021-03-09 Doku erweitert, Schaltplan fortgesetzt
    [FunkyHat.sch]
2021-03-10 Erstellung des Gehäusedesigns
    Erstellt in FreeCAD
    [case.FCStd]
2021-03-10 Case mit Fusion 360 erstellt
    stls exportiert und testdruck-datei erstellt (nur 5 mm hoch um zu schauen, ob es an den Bildschirm passt.
    [Case_left v3.stl, Case_right v2.stl, case.FCStd]
2021-03-10 Gehäuse fertig
    Mit Mit Deckel
    [Case_back v1.stl, Case_left v5.stl, Case_right v4.stl]
2021-03-15 Weiterschreiben an der Doku
    - Erstellung eines (vorläufigen) Gantt-Diagrams
    - Ausformulieren von Kapitel 2 der Doku
2021-03-18 Doku verbessert...
    Latex sortiert und entwirrt.
2021-03-18 cont..
    - Doku weitergeschrieben
    - Gehäuse fertig
    [Case_back v1.stl, Case_left v3.stl, Case_left v5.stl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]
2021-03-19 Doku weitergeschrieben
    - Kostenrechnung angefangen
    - Fertigung des Gehäuses beschrieben
    - Datenschutzhinweis
    - Gehäuse-Pläne bearbeitet
    - Gehäuse überarbeitet (Löcher für Kabelage)
    - Anfertigung einer "Stand"-Version des Gehäuses.
    [TAR_Pi_Case_right.stl]
2021-03-20 Create Installation der Software.txt
2021-03-20 Update Installation der Software.txt
    Instalations Code ohne MQTT
    mit Quellenangabe
2021-03-20 Install.sh erstellt
    Work in progress
    bisher nur Docker und Home Assistant
    MQTT und Zigbee2MQTT folgen
    script noch nicht getestet
2021-03-21 update der scripte
2021-03-21 Update install_hassio.bash
    zeigt jetzt IP der Hass-IO-Instanz an
2021-03-22 doku & script
    skirpt:
    - gibt nach ende der installation den Link für Home Assistan Web interface an
    doku
    - weitergeschrieben
2021-03-25 Bilder für HAssio,MQTT und Zigbee einrichten
2021-03-25 Doku erweitert
    - (danke Leon) Seitenangabe nach oben, Autoren nach unten
    - Matheformel für Kostenberechnung der Druckteile
    - Softwareüberblick verfasst
    - kleiner Rechtschreibfehler gefunden
2021-03-26 Erstellen des shz_install skripts. Mit Methoden, anderen Spielereien und viel mehr. NICHT GETESTET!
2021-03-26 bilder in der Doku
2021-03-26 shz_install überarbeitet
    Funkt noch nicht fehlerfrei... Werd da morgen nochmal weiter dran arbeiten... aber das mit den Flags setzten und die Installation funktioniert (teilweise)...
